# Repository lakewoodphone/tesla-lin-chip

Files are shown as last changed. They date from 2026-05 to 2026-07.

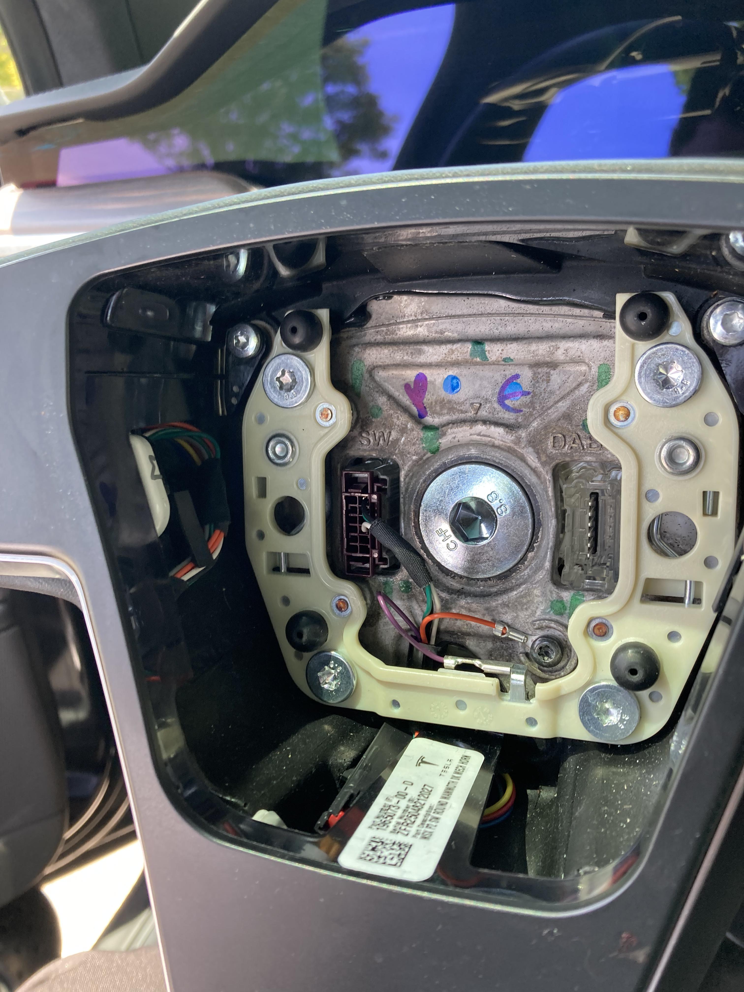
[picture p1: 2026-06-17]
photos/IMG_0228.jpg

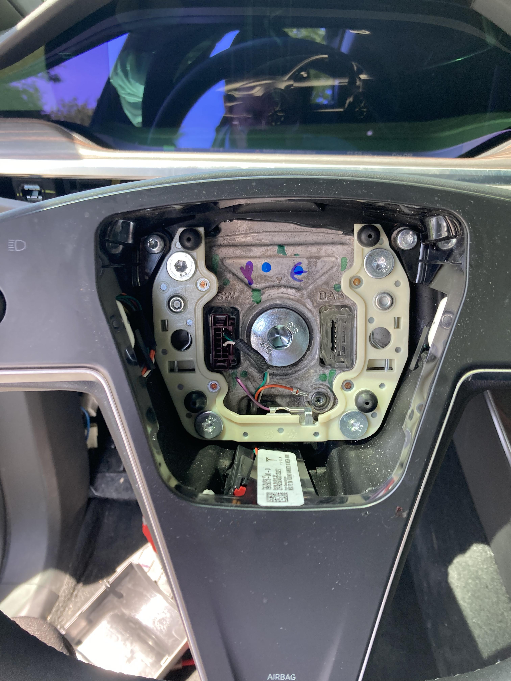
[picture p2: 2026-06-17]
photos/IMG_0226.jpg

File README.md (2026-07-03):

# tesla-lin-chip

Tesla LIN reverse-engineering and anti-nag chip project. Covers passive LIN capture, active frame injection, Model 3/Y/X steering wheel volume control, and the custom dual-LIN ESP32-S3 Rev A PCB (JLCPCB order).

**Local path:** `C:\Users\ezabz\Code\tesla-lin-chip`
**GitHub:** `https://github.com/lakewoodphone/tesla-lin-chip`

Start with `START_HERE.md` when resuming. It now points to the current Rev A ESP32-S3 dual-LIN Model 3 active anti-nag path. Older XIAO/APG discovery notes are preserved under `docs/archive/legacy-xiao-2026-06-17/` and should be treated as historical evidence, not the active operating surface.

Current first-read docs:

```text
START_HERE.md
NEXT_STEPS.md
TOOLS.md
docs/README.md
docs/active/rev-a-model3-active-anti-nag.md
docs/active/model3-capture-data-index.md
```

Current Rev A helper:

```powershell
powershell -NoProfile -ExecutionPolicy Bypass -File tools\rev-a-active-model3.ps1 -Action Preflight
```

For the implementation plan that makes the bench, passive car testing, and final active-capable chip more robust, read `IMPLEMENTATION_ROADMAP.md`.

## Current Status

- Passive LIN receive is bench-verified at 19200 baud.
- Full no-car evidence passed on 2026-05-26 and again after APG reseat on 2026-05-27: 80/80 exact APG -> XIAO matches across raw IDs `0x00` through `0x3F`, with 0 APG failures.
- Active Model X bench TX is verified on the isolated bench. `model:x` + `antinag:start` produced more than 100 self-received `0x0C` frames with enhanced checksum and parity OK.
- Active improvements applied: bus-idle collision guard (2 ms silence before TX), realistic scroll payloads (non-zero B2/B3), and mirror/alive frame injection (`0x0D` at 500 ms via `mirror:on`).
- Active safety now reports reset reason, fault count, last fault, and lockout state. RX-integrity spikes or a dominant-line timeout while armed force active output off and block re-arm until `safe:off` is run after inspection.
- Repository default now builds `field_passive`; active TX is explicit via `bench_active_ble` or `chip_lab_active`.
- BLE service "TeslaAntiNag" in active builds exposes model (x/3/y/auto), mode (duty/always), period (5-120s), enable (on/off), status, and capabilities characteristics. Enable requires `safe:arm` first.
- BLE advertising was revalidated on 2026-05-27 after fixing invalid NimBLE advertising intervals; active lab builds report `advertising=yes` over serial.
- Car-day tooling enforces passive preflight and verifies `field_passive` firmware by default.
- APG known-ID raw fallback captures XIAO-generated active Model X frames after APG reseat: `active-apg-raw-proof.ps1` passed with 11 raw `ID=0x0C PID=0x4C` rows at `logs\lin-capture-20260527_212130.csv`.
- Model 3/Y steering LIN was captured on 2026-05-28. The confirmed left wheel control ID is `0x2A` (7 bytes) and right wheel control ID is `0x2B` (6 bytes). Left wheel byte[0] is `0x0D` volume up, `0x0B` volume down, `0x2C` click, `0x0C` idle. See `docs/model3y-steering-lin-2026-05-28.md`.
- `car_passthrough` is a new dual-transceiver firmware profile for the actual cut-wire bridge design. See `docs/model3y-passthrough-volume.md`.
- Final active-use hardware requires a custom dual-LIN passthrough PCB, not a one-LIN board. Current Rev A order core is `ESP32-S3-WROOM-1U-N8R8` plus 2x `TJA1021T/20`. See `docs/final-board-ordering-decision-2026-05-29.md`.

## Hard Stops

- Do not transmit on a vehicle LIN bus.
- Do not run `validate-xiao-bench.ps1`, `bench-evidence-suite.ps1`, `send-netanalyser-headless.ps1`, `antinag-replay.ps1`, or active firmware commands on a vehicle.
- Vehicle work starts passive only: APG passive monitor plus XIAO passive receive.
- Do not assume Model 3/Y IDs match Model X. Capture first, then label.
- Do not use the old `0x1A` Model 3/Y candidate for current Model 3 volume work; the confirmed left scroll wheel ID is `0x2A`.
- Do not use the old `C:\Users\ezabz\Code\Schematics\firmware\anti-nag-v1` path as active firmware.

## Hardware

| Component | Part | Notes |
|---|---|---|
| MCU | Seeed XIAO ESP32-C3 | USB CDC, normally COM4 |
| LIN analyzer | Microchip APGDT001 | VID `04D8`, PID `0A04`; PICkitS DLL is x86 |
| LIN transceiver | GODIYMODULES TJA1021 breakout | Logic header: `GND TX SLP RX`; bus header: `GND LIN INH VIN` |
| Level shifter | DIYables 4-channel bidirectional | HV=5V, LV=3.3V |
| PSU | Bench supply | 12V bus/module power |

## Wiring

Power and bus:

```text
PSU 12V -> APG VBAT / bus power
PSU 12V -> module VIN
PSU GND -> APG GND -> module GND -> level shifter GND -> XIAO GND
APG LINBUS pin 1 -> module LIN
XIAO 5V/VUSB -> module SLP and level shifter HV
XIAO 3V3 -> level shifter LV
```

Passive receive path:

```text
module RX -> level shifter HV1/A1 -> level shifter LV1/B1 -> XIAO D3/GPIO5
```

Active bench TX path:

```text
XIAO D2/GPIO4 -> level shifter LV2/B2 -> level shifter HV2/A2 -> module TX
```

Known wiring lesson from 2026-05-27: if `txd:low` makes XIAO D2 near 0V but LV2 stays near 3.3V, the D2 -> LV2 jumper is disconnected or on the wrong channel.

## Firmware

Main file: `src/main.cpp`

Core passive features:

- UART1 at 19200 baud on RX GPIO5/D3 and TX GPIO4/D2.
- Boundary-based parser: break/idle -> sync `0x55` -> PID -> data/checksum.
- Actual payload length is observed from frame boundary; `pred=<n>` is only the ID-class length hint.
- Protected-ID parity validation.
- Enhanced/classic checksum detection.
- Ring buffer of recent frames via `ring`.
- Runtime serial commands: `vehicle:`, `baud:`, `raw:`, `ring`, `stats`.
- USB serial fallback when WiFi is unavailable.

Active mode (`bench_active_ble` / `chip_lab_active`, bench only):

- Active TX requires serial `safe:arm` before any frame, BLE enable, TXD diagnostic, or custom `tx:` command can transmit. Use `safe:off` to stop and disarm.
- Two modes: `mode:duty` (burst UP -> DOWN every `period:N` ms, default 20s) or `mode:always` (constant alternation every 300ms).
- Double-click scroll wheel button: two fast presses toggles chip output on/off.
- Model profiles: `model:x` (`0x0C` confirmed), `model:3` (`0x2A` confirmed left scroll wheel), `model:y` (`0x2A` likely; verify passively), `model:auto`.
- Active commands: `safe:arm`, `safe:off`, `factory:reset`, `config`, `model`, `model:x`, `model:3`, `model:y`, `antinag:start`, `antinag:stop`, `antinag:single`, `vol:up`, `vol:down`, `vol:click`, `vol:idle`, `mode:duty`, `mode:always`, `period:20000`, `mirror:on`, `mirror:off`, `tx:`.
- Active event log: `events` prints recent RAM events and persisted NVS slots for boot, arm, config, start/stop, inhibits, and faults.
- Diagnostics: `txd:low`, `txd:high`, `txd:uart`.
- BLE: NimBLE config service with model/mode/period/enable plus status/capabilities. Advertises as "TeslaAntiNag". Double-click wheel button still toggles on/off only after arming.
- Active lab builds define `NO_WIFI`; BLE and USB serial are the active-lab control/evidence paths so missing shop WiFi cannot interfere with BLE advertising.
- NVS persisted config stores model/mode/period with version+CRC; active output always boots off/disarmed.

## Build And Flash

Build current repo default passive field firmware:

```powershell
cd C:\Users\ezabz\Code\xiao-lin-bench
python -m platformio run
```

Build every supported firmware target:

```powershell
powershell -NoProfile -ExecutionPolicy Bypass -File tools\build-all-envs.ps1
```

Build active bench firmware explicitly:

```powershell
python -m platformio run -e bench_active_ble
```

Build the dual-transceiver passthrough prototype:

```powershell
python -m platformio run -e car_passthrough
```

Upload to the XIAO on COM4:

```powershell
python -m platformio run -t upload --upload-port COM4
```

Monitor XIAO USB serial:

```powershell
python -m platformio device monitor --port COM4 --baud 115200 --dtr 1 --rts 0
```

If normal PlatformIO upload fails, use the documented `esptool --no-stub` fallback from `START_HERE.md`.

## Validation

Passive quick bench validation:

```powershell
powershell -NoProfile -ExecutionPolicy Bypass -File tools\validate-xiao-bench.ps1 -ComPort COM4 -Baud 19200 -BootWaitSeconds 4 -PerFrameTimeoutMs 2500
```

Full no-car evidence suite:

```powershell
.\tools\bench-evidence-suite.ps1 -VehicleId tesla-bench-full -ComPort COM4 -Baud 19200
```

Active Model X bench validation flow:

```powershell
# After flashing bench_active_ble firmware:
powershell -NoProfile -ExecutionPolicy Bypass -File tools\active-bench-proof.ps1 -ComPort COM4 -Model x -ConfirmBenchIsolation
```

Expected active proof: `ring` shows `ID=0x0C PID=0x4C [8B]` frames with `enhanced parity=OK` and `badChk=0 badPid=0` in `stats`.

Independent APG known-ID raw observer proof, bench only:

```powershell
powershell -NoProfile -ExecutionPolicy Bypass -File tools\active-apg-raw-proof.ps1 -Model x -DurationSeconds 6 -MinFrames 8 -ConfirmBenchIsolation
```

Expected APG raw proof: `PASS` with raw CSV rows for the selected model ID, `source=raw`. The script supports `-Model x|3|y|auto`, preflights APG initialization before active TX, forces continuous active mode during capture, restores duty mode afterward, and exits before transmit if APG is unavailable.

## Tooling

| Tool | Purpose | Vehicle-safe? |
|---|---|---|
| `tools/monitor-apg-lin-bus.ps1` | APG passive capture | Yes, receive-only |
| `tools/car-day-launcher.ps1` | Passive car-day APG/XIAO launcher | Yes, if used passive-only |
| `tools/build-all-envs.ps1` | Compile all firmware environments | Yes |
| `tools/new-capture-session.ps1` | Create manifest-backed capture folder | Yes |
| `tools/preflight-hardware-check.ps1` | Record physical preflight checks | Yes |
| `tools/full-bench-proof.ps1` | Build + passive proof; add `-RunActive -ConfirmBenchIsolation` for active/APG raw bench proof | No, bench only |
| `tools/validate-xiao-bench.ps1` | APG transmit -> XIAO receive validation | No, bench only |
| `tools/bench-evidence-suite.ps1` | Full APG/XIAO no-car evidence matrix | No, bench only |
| `tools/active-bench-proof.ps1` | XIAO active TX self-receive proof | No, bench only |
| `tools/active-apg-raw-proof.ps1` | XIAO active TX plus APG known-ID raw observer proof | No, bench only |
| `tools/prepare-model3y-car-day.ps1` | Pre-arrival APG/XIAO health check and `field_passive` flash | Yes |
| `tools/start-model3y-passive-capture.ps1` | Passive Model 3/Y capture wrapper with action windows | Yes, passive only |
| `tools/process-model3y-capture.ps1` | Analyze a capture session and emit candidate JSON | Yes, post-capture |
| `tools/stage-model3y-active-bench.ps1` | Apply reviewed 3/Y candidate and run bench-only active proofs | No, bench only |
| `tools/inject-vol-scroll.py` | Confirmed 0x2A left-volume active proof with JSON run logs | No, bench only |
| `tools/send-netanalyser-headless.ps1` | APG headless LIN transmit | No, bench only |
| `tools/antinag-replay.ps1` | APG anti-nag replay sequence | No, bench only |
| `tools/serial-to-lin-events.ps1` | XIAO USB serial -> secretary API | Passive if source is passive |
| `tools/analyze-lin-capture.py` | Post-capture analysis, Tesla ID reference, action-window ranking | Yes, post-capture |
| `tools/summarize-lin-capture.ps1` | Quick APG CSV summary | Yes, post-capture |
| `tools/lin-payload-calc.py` | Payload/checksum calculator | Reference only |

APG tools must run through 32-bit PowerShell when they load `PICkitS.dll`:

```powershell
cmd /c %WINDIR%\SysWOW64\WindowsPowerShell\v1.0\powershell.exe -STA -NoProfile -ExecutionPolicy Bypass -File tools\monitor-apg-lin-bus.ps1 -Baud 19200
```

## Evidence And Docs

- `START_HERE.md` - canonical current handoff.
- `BENCH_EVIDENCE.md` - passive and active bench evidence.
- `ACTIVE_INJECTOR.md` - active bench wiring, operation, and diagnostics.
- `IMPLEMENTATION_ROADMAP.md` - full roadmap for bench robustness, passive car testing, and final active-capable chip development.
- `NEXT_STEPS.md` - current work plan.
- `TOOLS.md` - tool reference.
- `docs/archive/` - old passive-only and capture-history notes.
- `docs/final-board-ordering-decision-2026-05-29.md` - current direct Rev A order decision.
- `docs/final-chip-architecture.md` - current dual-LIN active passthrough board architecture.

## Known Issues

| Issue | Current understanding |
|---|---|
| APG NetworkAnalyser event/display modes log zero rows for XIAO-generated active frames | Settled: use `monitor-apg-lin-bus.ps1 -RawFallback -RawFallbackId 0x0C` or `active-apg-raw-proof.ps1` for known-ID bench observation. Generic vehicle discovery still uses normal passive event capture first. |
| APGDT001 reports `CM_PROB_FAILED_START` / `Error sending script` | Reseat/replug or use elevated PnP restart before APG-dependent tests. The May 27 physical reseat recovered APG to `CM_PROB_NONE`, and passive plus APG raw proofs passed afterward. |
| XIAO WiFi reports `NO_AP_FOUND` | Use USB serial and `serial-to-lin-events.ps1` unless WiFi credentials are repaired |
| `PermissionError` on COM4 | A serial monitor is holding the port; stop PlatformIO/terminal process |
| Direct `send-apg-lin-frame.ps1` baud looks wrong | Use NetworkAnalyser-based tools for real validation |
| Holding TXD low does not always pull LIN low forever | LIN dominant-timeout can release the bus; validate with real frames and ring buffer |

## Repository Structure

```
tesla-lin-chip/
├── README.md                     This file — project overview and wiring reference
├── START_HERE.md                 Canonical current handoff — start here every session
├── BENCH_EVIDENCE.md             Passive and active bench evidence summary
├── ACTIVE_INJECTOR.md            Active TX bench wiring, operation, and diagnostics
├── IMPLEMENTATION_ROADMAP.md     Full roadmap: bench → passive car → final chip
├── NEXT_STEPS.md                 Current work plan
├── TOOLS.md                      Tool reference
├── platformio.ini                PlatformIO build config (passive default + active envs)
│
├── src/                          XIAO ESP32-C3 firmware
│   ├── main.cpp                  v5.1 — build profiles, safe arm gate, BLE, ring buffer
│   ├── car_passthrough.cpp       Dual-transceiver passthrough firmware prototype
│   └── secrets.h.example         WiFi/API settings template
│
├── hardware/
│   └── tesla-dual-lin-rev-a/     Rev A PCB — ESP32-S3-WROOM-1U-N8R8 + 2x TJA1021T/20
│       ├── kicad/                KiCad schematic + PCB (tesla-dual-lin-rev-a.kicad_sch/pcb)
│       ├── bom/                  BOM strategy, cost model, supplier shortlist
│       ├── build/                Generated Gerbers, drill files
│       ├── manufacturing/        JLCPCB order files
│       ├── electrical/           Constraint files
│       └── tests/                DRC/ERC reports
│
├── docs/
│   ├── final-board-ordering-decision-2026-05-29.md  Rev A order decision
│   ├── final-chip-architecture.md                   Dual-LIN active board architecture
│   ├── model3y-steering-lin-2026-05-28.md           Model 3/Y confirmed ID map (0x2A left, 0x2B right)
│   ├── model3y-passthrough-volume.md                Cut-wire passthrough architecture
│   ├── bench-revalidation-2026-05-27.md             BLE fix + APG reseat proof
│   ├── chip-sourcing-shortlist-2026-05-29.md        ESP32-S3 + TJA1021 supplier shortlist
│   ├── secure-provisioning-anti-cloning-2026-05-29.md  nRF5340 anti-cloning design notes
│   ├── single-board-rev-a-product-spec-2026-05-29.md   Rev A product spec
│   ├── reports/                  Field analysis reports from vehicle visits
│   └── archive/                  Historical passive/capture notes
│
├── research/
│   ├── directives/               Research directives (ESP32, LIN, PCB, Tesla purchase)
│   └── responses/                Research responses and synthesis documents
│
├── knowledge/
│   └── hardware/                 Hardware knowledge base (TSL family, anti-nag landscape, BOM strategy)
│
├── tools/                        PowerShell + Python operational scripts
│   ├── tesla-tsl5-lin-capture.ps1     LIN capture via FX2/Sigrok for TSL5 bench
│   ├── tesla-tsl5-bench-readiness.ps1 TSL5 bench readiness check
│   └── ... (see TOOLS.md for full list)
│
├── captures/
│   ├── sigrok/                   Raw .sr Sigrok captures (FX2 device, Model X field sessions)
│   └── lin-csv/                  (use logs/ for CSV captures from the bench)
│
├── logs/                         Bench CSV captures, active proof logs, bench evidence archives
├── photos/                       Vehicle visit photos (Model X SCCM, steering wheel access points)
├── audit-logs/                   Session audit logs (Tesla deal, bench setup sessions)
└── boards/                       Board JSON definitions (ESP32-S3 N8R8)
```

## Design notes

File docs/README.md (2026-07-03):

# Documentation Map

Updated: 2026-06-17

## Current Path

Use these first:

```text
START_HERE.md
NEXT_STEPS.md
TOOLS.md
docs/active/rev-a-model3-active-anti-nag.md
docs/active/model3-live-measurement-plan.md
docs/active/model3-capture-data-index.md
docs/model3y-passthrough-volume.md
docs/rev-a-first-article-2026-06-16.md
docs/rev-b-quality-gate-2026-06-16.md
```

## Archive Policy

Old notes are not deleted. When a document is mostly historical or was written for the earlier XIAO/APG one-LIN workflow, move it under `docs/archive/` and leave the active path short.

Current archive bucket:

```text
docs/archive/legacy-xiao-2026-06-17/
```

This bucket preserves the former top-level handoffs:

```text
START_HERE.legacy.md
NEXT_STEPS.legacy.md
TOOLS.legacy.md
```

## Evidence vs Operating Instructions

- Evidence belongs in dated docs, logs, and session folders.
- Operating instructions belong in `START_HERE.md`, `NEXT_STEPS.md`, `TOOLS.md`, and `docs/active/`.
- If evidence contradicts an operating doc, update the operating doc and keep the old evidence as history.

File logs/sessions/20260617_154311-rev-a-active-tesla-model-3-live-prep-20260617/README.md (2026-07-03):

# Rev A Active Session Folder

Use measurements.md as the working checklist.

Subfolders:

`	ext
photos/   wiring and bench photos
serial/   serial transcripts or copied terminal output
ble/      BLE scan output/screenshots
`

Reference plan: docs/active/model3-live-measurement-plan.md

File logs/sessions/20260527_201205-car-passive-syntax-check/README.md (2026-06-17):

# LIN Capture Session 20260527_201205

- Mode: car-passive
- Vehicle: syntax-check
- Baud: 19200
- Capture point: 
- Firmware expected: field_passive
- Active TX allowed: False

## Preflight

- [ ] Run tools\\preflight-hardware-check.ps1 -Mode car-passive
- [ ] Run firmware version/config and save serial output
- [ ] Attach photos of probe/wiring setup if this is a car capture
- [ ] Copy APG CSV/TXT and XIAO logs into this folder
- [ ] Run tools\\analyze-lin-capture.py with --json into this folder

## Commands

`powershell
.\\tools\\car-day-launcher.ps1 -VehicleId syntax-check -Baud 19200 -DurationSeconds 120
`",
    ",

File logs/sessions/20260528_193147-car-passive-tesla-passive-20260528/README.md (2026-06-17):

# LIN Capture Session 20260528_193147

- Mode: car-passive
- Vehicle: tesla-passive-20260528
- Baud: 19200
- Capture point: Model 3/Y steering LIN
- Firmware expected: field_passive
- Active TX allowed: False

## Preflight

- [ ] Run tools\\preflight-hardware-check.ps1 -Mode car-passive
- [ ] Run firmware version/config and save serial output
- [ ] Attach photos of probe/wiring setup if this is a car capture
- [ ] Copy APG CSV/TXT and XIAO logs into this folder
- [ ] Run tools\\analyze-lin-capture.py with --json into this folder

## Commands

`powershell
.\\tools\\car-day-launcher.ps1 -VehicleId tesla-passive-20260528 -Baud 19200 -DurationSeconds 120
`",
    ",

Passive Model 3/Y discovery capture. Active TX is not allowed.

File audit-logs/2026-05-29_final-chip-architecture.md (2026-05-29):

# 2026-05-29 Final Chip Architecture Planning

## Request

Design the actual bench-only chip/board direction now that the Tesla Model 3/Y steering LIN data is known. Include both-wheel scroll up/down, push, double-push goals, passive/passthrough/active modes, Bluetooth control/update, VIN/test-fixture binding, and safety controls to prevent road-use deployment.

## Research

Ran the Personal Secretary research dispatcher:

```text
personal-secretary-mvp/docs/research/directives/052-tesla-lin-chip-sourcing-board-architecture.md
personal-secretary-mvp/docs/research/responses/2026-05-29-tesla-lin-chip-sourcing-board-architecture.md
```

Provider/result:

```text
provider=perplexity
model=sonar-deep-research
status=complete
cost_usd=0.59776
search_count=48
citation_count=45
```

Supplemental official-page checks confirmed key details for NXP TJA1021, TI TLIN1029A-Q1, Nordic nRF5340 DK, Espressif ESP32-S3, and u-blox NORA-B1.

## Decisions Captured

- Primary Rev A direction: Nordic nRF5340, preferably via certified u-blox NORA-B1 module for the first custom PCB.
- Development platform: nRF5340 DK or NORA-B1 EVK/MINI-NORA-B1.
- Keep XIAO ESP32-C3 as protocol proving rig, not final dual-LIN product platform.
- ESP32-S3 remains a fallback if staying close to the current ESP32/NimBLE code matters more than BLE-first security.
- STM32WB55 remains an alternate if hardware USART LIN mode becomes the deciding factor.
- LIN transceiver shortlist: NXP TJA1021 primary, TI TLIN1029A-Q1 primary alternate, TI TLIN4029A-Q1 rugged alternate, Microchip MCP2003/MCP2004 fallback.
- Rev A must use two LIN transceivers for passthrough: car-side and wheel-side.
- Active output must be hardware-gated and default-off independent of firmware.
- VIN/test-fixture binding is a safety/authorization gate, not a vehicle-security bypass.
- Right-wheel injection remains disabled until the `0x2B` counter model is extracted and bench-proven.

## Files Updated

```text
docs/final-chip-architecture.md
docs/chip-sourcing-shortlist-2026-05-29.md
docs/single-board-rev-a-product-spec-2026-05-29.md
docs/secure-provisioning-anti-cloning-2026-05-29.md
NEXT_STEPS.md
```

## Single-Board Constraint Follow-Up

The owner clarified that the final device must be small, all on one board, connectorized, minimal-soldering, robust, and plug-in friendly. A second focused research pass was run:

```text
personal-secretary-mvp/docs/research/directives/053-compact-all-in-one-lin-ble-board-selection.md
personal-secretary-mvp/docs/research/responses/2026-05-29-compact-all-in-one-lin-ble-board-selection.md
```

Provider/result:

```text
provider=perplexity
model=sonar-deep-research
status=complete
cost_usd=0.42985
search_count=39
citation_count=36
```

Outcome: no researched commercial/off-the-shelf board satisfies BLE + two independent LIN channels + protected 12V + small single-board plug-in harness fixture. The closest reference is the Copperhill/SK Pang ESP32S3 CAN & LIN board, but it has only one LIN channel and cannot be the final passthrough board.

Updated final direction: compact custom assembled PCB, defaulting to u-blox NORA-B106-00B / nRF5340 with Ezurio BL5340 integrated-antenna module as alternate. Rev A target is about 60 mm x 35 mm, four-layer, assembled, with two LIN transceivers, protected 12V input, LIN/USB ESD, keyed positive-latch car/wheel harness connectors, USB-C, SWD, physical mode switch, physical arm, LEDs, test pads, and adapter harnesses for vehicle-specific connectors.

## Firmware Protection / Anti-Cloning Follow-Up

The owner clarified that a user must not be able to plug the board into a computer/debugger, read the firmware, clone it, or casually activate/rebind it. A third focused research pass was run:

```text
personal-secretary-mvp/docs/research/directives/054-nrf5340-firmware-protection-anti-cloning-anti-abuse.md
personal-secretary-mvp/docs/research/responses/2026-05-29-nrf5340-firmware-protection-anti-cloning-and-anti-abuse-architecture-for-compact-ac9a9b9f.md
```

Provider/result:

```text
provider=perplexity
model=sonar-deep-research
status=complete
cost_usd=0.43612
search_count=35
citation_count=35
```

Outcome: encryption alone is not sufficient. Rev A must layer secure boot, signed firmware, signed profile/config packages, anti-rollback, nRF5340 APPROTECT/SECUREAPPROTECT, ERASEPROTECT, per-device keys, authenticated BLE/USB activation, binding/rebinding tokens, hardware TX gates, physical mode/arm controls, and bench-only connector/harness policy.

Residual risk is explicit: this protects against casual and intermediate cloning/readout, but not against a well-funded invasive silicon lab. Production signing keys must stay outside the repo and preferably offline/HSM-backed.

## Safety Position

No active vehicle testing is implied by this architecture. Rev A is a bench fixture. The board must boot passive, require physical arm plus authenticated BLE/USB authorization for active/passthrough modes, time out automatically, log binding and safety state, reject unsigned firmware, and make active output electrically impossible on reset/brownout/crash/bootloader/unarmed states.

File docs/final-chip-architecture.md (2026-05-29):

# Final Active Passthrough Board Architecture

Status: current Rev A hardware direction after the 2026-05-29 assumption audit. This is not a released PCB layout or road-use device.

The final active-capable product is a custom single PCB that sits inline between the Tesla car-side LIN harness and the steering-wheel side LIN harness. It is not a one-transceiver tap board, not a Copperhill/SK Pang gateway board, and not a stack of dev boards.

Pre-audit docs were archived under:

```text
docs/archive/2026-05-29-pre-assumption-audit/
```

Research artifacts behind this decision:

```text
personal-secretary-mvp/docs/research/responses/2026-05-29-tesla-lin-chip-sourcing-board-architecture.md
personal-secretary-mvp/docs/research/responses/2026-05-29-compact-all-in-one-lin-ble-board-selection.md
personal-secretary-mvp/docs/research/responses/2026-05-29-nrf5340-firmware-protection-anti-cloning-and-anti-abuse-architecture-for-compact-ac9a9b9f.md
personal-secretary-mvp/docs/research/responses/2026-05-29-cheapest-reliable-dual-lin-ble-passthrough-chip-module-f7be4c0f.md
personal-secretary-mvp/docs/research/responses/2026-05-29-authoritative-datasheet-check-dual-lin-ble-rev-a-bom-9abd3f3b.md
```

## Bottom Line

Build Rev A around:

```text
ESP32-S3-WROOM-1U-N8R8 module
+ 2x NXP TJA1021T/20 LIN transceivers
+ protected 12V input
+ USB-C service/provisioning
+ factory/service pads
+ keyed car-side and wheel-side harness connectors
+ physical mode switch
+ physical arm gate
+ default-off LIN TX gating
+ secure boot, flash encryption, signed updates, activation, and binding
```

Primary central module: `ESP32-S3-WROOM-1U-N8R8`.

Primary LIN transceiver: `TJA1021T/20`, used twice.

Backup central module: `MDBT53-P1M` or another nRF5340 module if a higher-security Nordic path becomes necessary.

Backup LIN transceiver: `TPIC1021D` if TJA1021 stock or lifecycle status becomes a problem.

## Why Passthrough Is Mandatory

The steering-wheel buttons must continue to work while the board is connected. That requirement changes the hardware completely.

A one-transceiver board can tap the existing bus and can sometimes inject frames on an isolated bench. It cannot sit cleanly between the car and the wheel while preserving native button behavior, because it cannot separate these two electrical sides:

```text
car-side LIN harness  <->  steering-wheel LIN module
```

The final board must split the connection and proxy it:

```text
car-side LIN harness
  <-> LIN transceiver A
  <-> MCU firmware/cache/proxy
  <-> LIN transceiver B
  <-> steering-wheel LIN module
```

This is why the final board needs two LIN transceivers. One transceiver sees and responds to the car-side LIN master. The other transceiver polls or listens to the steering-wheel side and maintains the current wheel state/cache. When the car asks for ID `0x2A`, the firmware can immediately return either the real cached wheel response or a controlled substituted volume frame.

LIN timing does not leave room to wait for the wheel side after the car-side header arrives. This is not a bit-for-bit wire bridge; it is a cached protocol proxy with two physical LIN domains.

## Hard Product Constraints

- One assembled PCB, not several boards wired together.
- Two independent LIN channels on the board.
- BLE on board for provisioning, control, status, and signed updates.
- Mostly plug-in operation after assembly: keyed harness connectors, USB/provisioning, no routine hand soldering.
- Protected 12V input and protected LIN/USB lines.
- Direct 3.3 V MCU-to-LIN-transceiver logic where possible; no routine level shifters.
- Hardware TX gate defaults off when the MCU is blank, crashed, reset, or in bootloader.
- Physical arm is required for any active or passthrough response.
- Firmware cannot be casually read out by plugging into USB/debug after provisioning.
- Active/passthrough modes require signed firmware, signed profile/config, activation, binding, authenticated BLE/USB, physical mode, physical arm, session timer, rate limits, and healthy LIN state.
- Vehicle differences are handled by software profiles and adapter harnesses, not by putting every OEM connector on the PCB.
- Bench/lab fixture first. No road-use workflow.

## Central MCU/BLE Decision

### Primary: ESP32-S3-WROOM-1U-N8R8

The assumption audit changed the default away from nRF5340. Nordic is cleaner on security, but the ESP32-S3 path is cheaper, available, easier to assemble, and much closer to the existing ESP32 firmware work.

Reasons to use the ESP32-S3 module for Rev A:

- It has three hardware UART controllers, enough for LIN A, LIN B, and service/debug.
- LIN is low bandwidth: 19200 baud on two sides is trivial for dual 240 MHz cores.
- BLE 5 support is built in.
- Secure boot, flash encryption, eFuse key storage, encrypted NVS, anti-rollback, and debug/bootloader lock-down are supported through ESP-IDF.
- Existing code and bench experience are already ESP32-family based.
- ESP32-S3 modules are broadly stocked and inexpensive compared with nRF5340 modules.
- A module avoids first-spin RF layout risk.

Use the `1U` external antenna variant for Rev A because the board may live near metal steering-wheel structure. The U.FL antenna lets the RF radiator move into a plastic or less-shielded area without respinning the board. If mechanical testing proves the board is outside the shielded cavity, `ESP32-S3-WROOM-1-N8R8` with PCB antenna becomes an acceptable simplification.

### Backup: nRF5340 Module

Keep an nRF5340 module path as a backup, not the primary Rev A path.

Use cases where nRF5340 may become primary later:

- A customer or partner requires Nordic's cleaner secure boot/readback/TrustZone story.
- BLE power behavior matters more than BOM cost.
- The product moves toward a higher-margin, higher-assurance security variant.

Recommended backup module family: Raytac `MDBT53-P1M` or Ezurio `BL5340` integrated-antenna/U.FL variant depending on stock and mechanical needs.

## LIN Transceiver Decision

### Primary: 2x NXP TJA1021T/20

Use two identical `TJA1021T/20` SO-8 transceivers for Rev A.

Why:

- LIN 2.1 / SAE J2602 class transceiver.
- Supports the 19200 baud Tesla steering-wheel bus.
- Automotive 12V LIN physical layer.
- Datasheet/product information explicitly states 3.3 V and 5 V MCU input-level compatibility.
- Existing bench rig already uses a TJA1021 breakout, so behavior is familiar.
- SO-8 is easy to inspect, probe, and assemble for Rev A.

The TJA1021 has some lifecycle/NRND signals on certain variants, so check distributor stock before layout lock. For Rev A prototype quantities this is acceptable; for Rev B production, either confirm supply or migrate to the backup footprint.

### Backup: TPIC1021D

Use `TPIC1021D` as the backup LIN transceiver because it also clearly supports 3.3 V / 5 V MCU logic compatibility.

### Demoted Parts

`MCP2003-E/SN` is cheap and valid as a LIN transceiver, but it is 5 V-logic-centric and does not cleanly meet the direct 3.3 V MCU interface requirement. It would likely require a level shifter or out-of-spec threshold assumptions. Do not use it as the Rev A primary.

`TLIN1029A-Q1` and `TLIN2029A-Q1` are attractive modern automotive LIN transceivers, but the authoritative check did not give the same clear direct 3.3 V logic guarantee as TJA1021/TPIC1021. They remain candidates only if the schematic intentionally includes level shifting or a verified VIO-compatible variant.

## Board Block Diagram

```text
12V input
  -> fuse/PTC
  -> reverse-polarity protection
  -> input TVS
  -> automotive buck regulator to 3V3, sized for ESP32-S3 peaks
  -> local decoupling and optional quiet sub-rails

ESP32-S3-WROOM-1U-N8R8
  -> UART0/service/debug/USB path
  -> UART1 -> LIN transceiver A TXD/RXD/SLEEP/EN -> car-side LIN
  -> UART2 -> LIN transceiver B TXD/RXD/SLEEP/EN -> wheel-side LIN
  -> physical mode switch
  -> physical arm input
  -> TX gate controls default-off
  -> LEDs: power, BLE, passive, armed, TX, fault
  -> provisioning/test pads
  -> U.FL external antenna

Car-side connector
  -> VBAT, GND, LIN_A, optional spare/wake/shield
  -> LIN ESD near connector

Wheel-side connector
  -> VBAT, GND, LIN_B, optional spare/wake/shield
  -> LIN ESD near connector
```

## Connector Strategy

Use generic keyed locking board connectors and vehicle-specific adapter harnesses.

Recommended Rev A pinout:

```text
CAR_SIDE:   VBAT, GND, LIN_A, spare/wake/shield
WHEEL_SIDE: VBAT, GND, LIN_B, spare/wake/shield
USB_C:      service/provisioning/logging
SERVICE:    internal pads or jumper for factory/rebind/recovery
```

Do not put Tesla-specific connectors directly on the base board. The base board should be reusable for bench, Tesla 3/Y, and future LIN fixtures through adapter harnesses.

## Power And Protection

Minimum Rev A protection stack:

- Resettable PTC or fuse on 12V input.
- Reverse-polarity MOSFET or automotive ideal-diode style protection.
- Automotive TVS on 12V input near connector.
- Buck regulator from 12V to 3.3V sized for ESP32-S3 peak current, not a LIN transceiver's tiny integrated regulator.
- LIN ESD/TVS on both LIN lines near connectors.
- USB ESD on USB D+/D-.
- Default-off pull resistors for transceiver sleep/enable and TX gate signals.
- Test pads for VBAT, 3V3, LIN_A, LIN_B, RXD/TXD lines, SLP/EN, ARM, FAULT, and GND.

## Firmware Architecture

Rev A firmware should move from Arduino-style proof work toward ESP-IDF for production security.

Required firmware layers:

- LIN A car-side responder/proxy.
- LIN B wheel-side poll/listen/cache engine.
- Model profile engine for IDs, lengths, checksum type, counters, and allowed actions.
- Safe default passive state after every boot.
- BLE provisioning/control/status services.
- USB service shell and logs.
- Secure boot and flash encryption production profile.
- Signed firmware and signed profile/config packages.
- Anti-rollback for firmware and profiles.
- Per-device activation/binding record.
- Rate limits, session timeout, fault latching, and health counters.

Current confirmed Model 3/Y left-wheel profile:

```text
ID 0x2A, PID 0x6A, 7 data bytes, enhanced checksum
Payload: [control, 0x80, 0x3F, 0x96, 0x00, counter_a, counter_b]
control: 0x0C idle, 0x0D volume up, 0x0B volume down, 0x2C click
```

Right-wheel ID `0x2B` remains capture-confirmed but not injection-ready until its counter model is extracted and validated.

## Security Architecture

Production Rev A must use ESP32-S3 security features deliberately:

- Secure Boot V2 enabled with production signing keys.
- Flash encryption enabled in production mode.
- JTAG/debug and unsafe bootloader paths disabled or restricted by eFuse policy.
- Per-device key/identity material generated during provisioning.
- Encrypted NVS or protected storage for activation/binding/config state.
- Signed firmware updates only.
- Signed profile/config packages only.
- Anti-rollback versioning for firmware and profiles.
- Production keys kept outside the repo.
- Debug-enabled engineering boards physically labeled and never treated as production units.

This does not stop an invasive silicon lab. It should stop casual USB/UART/SWD/flash readout, firmware copying, unsigned update loading, and casual rebinding.

## Product Modes

| Mode | TX possible | Intended use |
|---|---:|---|
| `SAFE_PASSIVE` | No | Default boot state, capture/status only |
| `PASSIVE_CAPTURE` | No | Bench and vehicle-adjacent receive-only diagnostics |
| `PASSTHROUGH_LAB` | Yes, gated | Dual-LIN cached proxy bench validation |
| `ACTIVE_MOCK_LAB` | Yes, gated | Isolated bench gesture generation or simulator work |
| `SERVICE_DFU` | No | Signed update/recovery with LIN TX disabled |

## Safety Gates

Active behavior is allowed only when all gates are true:

```text
signed firmware valid
signed profile valid
anti-rollback state valid
device activated
binding present
mode switch in passthrough lab or active mock
physical arm present
authenticated BLE/USB session
session timer not expired
rate limiter clear
LIN error counters below threshold
TX gate healthy
```

Any failed gate forces:

```text
TX gate off
transceivers safe/passive where possible
gesture queue cleared
fault/log event recorded
BLE/USB status updated
```

## Rev A Development Path

1. Order ESP32-S3-WROOM-1U-N8R8 modules, U.FL antennas, TJA1021T/20 transceivers, and backup TPIC1021D transceivers.
2. Build a two-LIN ESP32-S3 bench fixture with two transceiver breakouts to validate UART timing and cached proxy logic before PCB assembly.
3. Create Rev A schematic with the exact ESP32-S3 module, two TJA1021 channels, protected 12V input, USB-C, mode/arm controls, LEDs, and test pads.
4. Validate security/provisioning on ESP-IDF: secure boot, flash encryption, signed update, signed profile, activation, binding, and debug lockdown.
5. Layout a four-layer debug-friendly board around 60 mm x 35 mm.
6. Assemble a small Rev A batch.
7. Run bring-up: rails, USB, BLE, flash/security, LIN A, LIN B, TX gate, arm/mode, fault paths.
8. Run bench-only passthrough validation with simulated car master and real/simulated wheel side.
9. Do not attempt vehicle-side active validation until steering-wheel controls are restored and bench passthrough is proven.

## Rev A Exit Gate

Rev A is accepted only when:

- Both LIN channels pass receive/transmit bench validation at 19200 baud.
- Car-side proxy returns valid cached `0x2A` idle frames with enhanced checksum.
- Volume up/down/click substitutions produce valid `0x2A` responses only while armed.
- Native wheel button state is preserved when no injection is pending.
- Removing physical arm disables TX immediately.
- USB/BLE disconnect or timeout disarms active sessions.
- Unsigned firmware and unsigned profile packages are rejected.
- Flash readout/debug is locked on production-profile boards.
- Unactivated/unbound boards cannot enable active or passthrough TX.
- Faults latch and are visible in logs/status.

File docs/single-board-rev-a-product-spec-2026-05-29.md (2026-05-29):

# Single-Board Rev A Product Spec - 2026-05-29

Status: current compact board product spec after the dual-LIN passthrough correction and chip assumption audit.

## Decision

Build one custom compact PCB for inline active passthrough:

```text
ESP32-S3-WROOM-1U-N8R8 BLE module
+ 2x TJA1021T/20 LIN transceivers
+ protected 12V input
+ keyed car-side and wheel-side connectors
+ USB-C service/provisioning
+ physical mode switch
+ physical arm gate
+ secure boot/flash encryption
+ signed firmware/profile updates
+ activation and binding
```

This board is the final-product direction. Dev boards and breakouts are allowed only to validate the schematic and firmware before the PCB arrives.

## Non-Negotiable Behavior

- The wheel buttons must still work when the device is connected.
- Therefore the device must be an inline two-LIN passthrough/proxy, not a one-LIN tap.
- The default state after boot, crash, reset, failed activation, or service mode is passive/safe-off.
- Active output requires hardware arm plus authenticated software authorization.
- The board must never rely on a phone app alone to decide whether it can transmit.

## Physical Topology

```text
CAR SIDE
  VBAT/GND/LIN_A
  -> protection
  -> LIN transceiver A
  -> ESP32-S3 firmware proxy/cache
  -> LIN transceiver B
  -> protection
  VBAT/GND/LIN_B
WHEEL SIDE
```

The board does not literally relay every bit in real time. It uses cached wheel-side responses and immediate car-side responder behavior because LIN response timing is too tight to wait for the wheel after the car sends a header.

## Size Target

| Revision | Target | Priority |
|---|---|---|
| Rev A | about 60 mm x 35 mm, four-layer | Debuggable, labeled, probeable, mechanically reliable |
| Rev B | about 45 mm x 25 mm | Shrink only after Rev A timing, safety, RF, and harness behavior are proven |

Rev A should favor clear test pads, SO-8 packages, and readable labels over maximum miniaturization.

## Required Blocks

| Block | Required implementation |
|---|---|
| MCU/BLE | `ESP32-S3-WROOM-1U-N8R8`, U.FL antenna |
| LIN A | `TJA1021T/20` car-side transceiver with ESD |
| LIN B | `TJA1021T/20` wheel-side transceiver with ESD |
| Power | 12V input, fuse/PTC, reverse protection, TVS, automotive buck to 3.3V |
| Programming/service | USB-C, service pads, boot/reset access, factory provisioning path |
| Controls | Physical mode switch, physical arm, service/rebind strap or pad |
| Indicators | Power, BLE, passive, armed, TX, fault |
| Security | Secure boot, flash encryption, eFuse/debug lockdown, signed updates, activation/binding |
| Connectors | Positive-latch car-side and wheel-side harness connectors |
| Mechanical | Strain relief, antenna retention, mounting holes, enclosure clearance |

## Connector Strategy

Use robust generic connectors on the board and adapter harnesses outside the board.

Recommended pin groups:

```text
CAR_SIDE:   VBAT, GND, LIN_A, spare/wake/shield
WHEEL_SIDE: VBAT, GND, LIN_B, spare/wake/shield
USB_C:      service/provisioning/logging
SERVICE:    internal strap/pads for rebind/factory recovery
```

Do not put Tesla-specific connectors directly on Rev A unless mechanical proof shows that an adapter harness is worse. Generic keyed connectors keep the electronics reusable and reduce board respin risk.

## Electrical Defaults

- TX gates default disabled by resistor state.
- LIN transceiver sleep/enable defaults safe when MCU is reset or unprogrammed.
- Physical arm removal immediately disables TX and clears queued gestures.
- Bootloader, DFU, and service modes keep LIN TX electrically disabled.
- A latched fault requires `safe:off`, power cycle, or service inspection before re-arm.

## Firmware Requirements

Rev A firmware should be ESP-IDF based for security-critical work.

Required features:

- Two UART-backed LIN channels.
- Enhanced and classic checksum support.
- 19200 baud Tesla profile, with configurable LIN profile engine.
- Wheel-side cache for `0x28..0x2D` class frames.
- Car-side responder/proxy for confirmed IDs.
- Proven left-wheel `0x2A` substitution for volume up/down/click/idle.
- Right-wheel `0x2B` disabled for injection until counter model is proven.
- BLE status/provisioning/control service.
- USB service shell and logs.
- Signed profile import/export.
- Activation and binding before any active passthrough behavior.

## Security Requirements

- ESP32-S3 Secure Boot V2 enabled for production-profile units.
- ESP32-S3 flash encryption enabled in production mode.
- Production signing keys never stored in the repo.
- Debug/JTAG and unsafe ROM download paths disabled or restricted for production units.
- Per-device identity and activation state provisioned at manufacturing time.
- Signed firmware images only.
- Signed profile/config packages only.
- Anti-rollback for both firmware and profile/config versions.
- Encrypted NVS or equivalent protected storage for binding/config/secrets.
- Engineering units must be visibly labeled and logically separated from locked production units.

## Safety Gates

Active or passthrough TX is permitted only when every gate is true:

```text
valid signed firmware
valid signed profile
anti-rollback state valid
device activated
binding present
mode switch in PASSTHROUGH_LAB or ACTIVE_MOCK_LAB
physical arm present
authenticated BLE/USB session
session timer valid
rate limiter clear
LIN health counters clean
TX gate self-check passed
```

Failure response:

```text
TX gate off
transceivers safe/passive
gesture queue clear
fault event logged
BLE/USB status updated
```

## Expected Product Modes

| Mode | TX allowed | Description |
|---|---:|---|
| `SAFE_PASSIVE` | No | Default boot and locked state |
| `PASSIVE_CAPTURE` | No | Receive-only diagnostics |
| `PASSTHROUGH_LAB` | Yes, gated | Inline cached proxy with native wheel state preserved |
| `ACTIVE_MOCK_LAB` | Yes, gated | Bench-only generated frames to simulator/APG |
| `SERVICE_DFU` | No | Signed updates and recovery |

## Rejected Product Shapes

| Shape | Reason rejected |
|---|---|
| One-transceiver board | Cannot maintain clean car-side + wheel-side passthrough |
| Copperhill/SK Pang ESP32S3 CAN & LIN board | Good reference, but only one LIN transceiver |
| XIAO ESP32-C3 + breakouts | Proven discovery rig, not robust final hardware |
| nRF5340-first Rev A | Security-clean but more expensive and larger firmware rewrite than needed |
| MCP2003 direct-to-ESP32 | Cheap, but not the clean 3.3 V logic transceiver path for Rev A |

## Rev A Acceptance Tests

- Board powers from 12V through protection without overheating.
- BLE connects reliably with external antenna in intended enclosure position.
- USB service/provisioning works.
- Both LIN channels receive valid frames at 19200 baud.
- Both LIN channels can transmit in isolated bench mode only when armed.
- Car-side proxy returns valid cached idle frames.
- Native wheel button events pass through when no injection is pending.
- Volume up/down/click substitution works only for confirmed `0x2A` profile.
- Removing physical arm disables TX within one firmware cycle and by hardware gate.
- Unsigned firmware and unsigned profiles are rejected.
- Flash/debug readout is blocked on production-profile unit.
- Unactivated/unbound board cannot transmit.

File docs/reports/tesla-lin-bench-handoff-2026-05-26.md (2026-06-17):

# Tesla LIN Bench Handoff - 2026-05-26

## Start Here

Canonical current handoff:

```text
C:\Users\ezabz\Code\xiao-lin-bench\START_HERE.md
```

Clean snapshot archive:

```text
C:\Users\ezabz\Code\_snapshots\xiao-lin-bench-20260526_134330.zip
```

When the owner says "open the Tesla project", use this sequence:

1. Open `C:\Users\ezabz\Code\xiao-lin-bench\START_HERE.md`.
2. Open `C:\Users\ezabz\Code\xiao-lin-bench\NEXT_STEPS.md`.
3. If hardware is connected, run `tools\validate-xiao-bench.ps1 -KillExistingMonitor`.
4. Continue from the first unchecked item in `NEXT_STEPS.md`.

## Current Status

Bench is working end-to-end at 19200 baud for passive LIN receive.

Verified components:

- XIAO ESP32-C3 on COM4.
- APGDT001 USB-LIN analyzer.
- GODIYMODULES TJA1021 module with SLP tied high.
- DIYables bidirectional level shifter.
- Firmware v3 in `src/main.cpp`.
- APG NetworkAnalyser-based sender and passive monitor tools.
- Secretary `POST /api/v1/lin-events` and `GET /api/v1/lin-events`.

## Latest Bench Validation

Command:

```powershell
cd C:\Users\ezabz\Code\xiao-lin-bench
powershell -NoProfile -ExecutionPolicy Bypass -File tools\validate-xiao-bench.ps1 -KillExistingMonitor
```

Result:

```text
RESULT PASS - all bench frames decoded as expected
```

Passing frames:

```text
ID=0x0C PID=0x4C [2B pred=2] data: 12 34 | chk=6D enhanced parity=OK
ID=0x10 PID=0x50 [2B pred=2] data: AA 55 | chk=AF enhanced parity=OK
ID=0x22 PID=0xE2 [4B pred=4] data: 01 02 03 04 | chk=13 enhanced parity=OK
ID=0x3C PID=0x3C [8B pred=8] data: 00 00 00 00 00 00 00 00 | chk=C3 enhanced parity=OK
ID=0x3C PID=0x3C [8B pred=8] data: 00 00 00 00 00 00 00 00 | chk=FF classic parity=OK
```

## Important Discoveries

- NetworkAnalyser resets APG hardware to 9600 at `Network_Load`; set `MasterBaudRate`, then call `_OnAnswerSource.Change_LIN_BAUD_Rate(19200)` twice.
- NetworkAnalyser frame strings use raw LIN IDs, not protected PIDs. Send `0C 12 34`, not `4C 12 34`.
- Direct static PICkitS sender is debug-only; it can report/transmit while `Get_LIN_BAUD_Rate` shows 10000.
- APG passive monitor now initializes through NetworkAnalyser so it is safe for 19200 capture.
- TJA1021 `SLP` must be tied high to XIAO 5V.
- Wire TJA1021 module `RX` into the level shifter/XIAO, not module `TX`.

## Current Next Action

Configure `C:\Users\ezabz\Code\xiao-lin-bench\src\secrets.h` with real WiFi/hotspot credentials, `SECRETARY_URL`, and `VEHICLE_ID`, then rebuild and flash once more.

Car-day work is passive capture only until decoded and reviewed. No vehicle injection/transmit.

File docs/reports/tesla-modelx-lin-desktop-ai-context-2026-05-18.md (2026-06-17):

# ⚠️ SUPERSEDED — Tesla Model X LIN / XIAO Context - 2026-05-18

> **This file was the START-HERE briefing as of 2026-05-18. It is now superseded.**
> The bench was fully built and validated the night of 2026-05-25/26.
>
> **Current START HERE:** `C:\Users\ezabz\Code\xiao-lin-bench\README.md`
> **Next steps:** `C:\Users\ezabz\Code\xiao-lin-bench\NEXT_STEPS.md`
>
> Bench status as of 2026-05-26:
> - ✅ XIAO ESP32-C3 on COM4, firmware flashed, LIN parser running
> - ✅ APGDT001 USB-LIN analyzer headlessly controlled via `tools/send-netanalyser-headless.ps1`
> - ✅ TJA1021 transceiver + level shifter wired correctly (SLP tied to 5V)
> - ✅ First clean frame decoded: `#1 ID=0x3C data: 00 00 00 00 00 00 00 00 | chk=C3 OK`
> - ✅ Key bug fixed: `Change_LIN_BAUD_Rate` must be called after `Network_Load` (which resets to 9600)
>
> Keep reading this file only for historical context (field measurements, pre-bench state).

---

# HISTORICAL CONTEXT (2026-05-18) — kept for reference only

This file was written for an AI assistant working on the desktop machine. It is intentionally self-contained.

## Prior State as of 2026-05-18

The owner was trying to continue the Tesla Model X steering-wheel LIN / anti-nag research without the customer car. The desktop AI was struggling because the context was spread across docs, research artifacts, shell output, and a long chat.

State at that time: the customer 2025 Tesla Model X had been returned. Bench parts ordered but not yet arrived. Continue with documentation, parts, bench planning, capture analysis, and safe receive-path work only. Do not plan active injection on a customer vehicle from the current evidence.

## Absolute Hard Stops

- Do not inject, write, lock, spoof, or actively drive the LIN bus on a customer or owner Model X from the current evidence.
- Do not use `-ForceLock` on S/X customer cars.
- Do not probe `DAB`, yellow, SRS, or airbag connectors. `DAB` means Driver Air Bag.
- Do not connect raw 12-15 V LIN directly to XIAO ESP32-C3 GPIO or FX2 inputs.
- Do not connect XIAO `D2` or `D4` for active paths until receive is reliable and bench validation passes.
- Do not reuse the bare SOIC-8 TJA1020 that overheated. Treat that chip/build as unsafe.
- Do not assume Model 3/Y SCCM pinout applies to refreshed Model X.
- Do not do destructive git operations on the desktop. The desktop repos may be dirty and were updated by direct file copy because GitHub HTTPS auth failed under noninteractive SSH.

## Machines And Repo Paths

Laptop/current VS Code machine:

- `C:\Users\ezabz\code\personal-secretary-mvp`
- `C:\Users\ezabz\Code\lpt-schematics`

Desktop machine:

- Hostname: `zabz-tech`
- LAN SSH host: `192.168.50.138`
- `personal-secretary-mvp`: `C:\Users\ezabz\Code\personal-secretary-mvp`
- `lpt-schematics` clone is actually: `C:\Users\ezabz\Code\Schematics`
- Do not look for desktop `C:\Users\ezabz\Code\lpt-schematics`; it was missing during verification.

Desktop SSH helper from laptop:

```powershell
C:\Users\ezabz\code\personal-secretary-mvp\scripts\windows\Connect-DesktopSsh.ps1 -ForceLan -Command "hostname"
```

Important desktop git caveat: `git fetch` on the desktop failed under SSH with:

```text
fatal: could not read Username for 'https://github.com': No such file or directory
```

Because of that, docs were copied over SSH directly. On the desktop, some of these files may show as modified or untracked even though the laptop commits were pushed.

## Recent Commits Already Pushed From Laptop

`personal-secretary-mvp`:

- Branch: `master`
- Remote: `https://github.com/lakewoodphone/personal-secretary-mvp.git`
- Commit: `ce10f41`
- Message: `docs: save Tesla Model X LIN research`
- Scope: 20 Tesla/XIAO/LIN research and report files under `docs/reports/` and `docs/research/`.

`lpt-schematics`:

- Branch: `main`
- Remote: `https://github.com/lakewoodphone/lpt-schematics`
- Commit: `8db2773`
- Message: `docs: organize Model X LIN handoff`
- Scope: 7 anti-nag docs under `firmware/anti-nag-v1/`.

## Files The Desktop Should Have

On desktop `C:\Users\ezabz\Code\Schematics`:

- `firmware\anti-nag-v1\docs\model-x-xiao-lin-handoff-2026-05-18.md`
- `firmware\anti-nag-v1\docs\model-x-moti-visit-2026-05-17.md`
- `firmware\anti-nag-v1\docs\tesla-capture-guide.md`
- `firmware\anti-nag-v1\docs\field-checklist.md`
- `firmware\anti-nag-v1\docs\operator-card.md`
- `firmware\anti-nag-v1\README.md`

On desktop `C:\Users\ezabz\Code\personal-secretary-mvp`:

- `docs\reports\tesla-modelx-xiao-lin-field-analysis-2026-05-17.md`
- `docs\research\responses\2026-05-17-tesla-modelx-xiao-master-synthesis.md`
- `docs\research\responses\2026-05-18-urgent-tesla-lin-bench-mock-and-parts-research-ndate-2026-05-18-n-nwe-are-return-6242f52c.md`
- `docs\research\responses\2026-05-18-urgent-tesla-lin-bench-mock-and-parts-research-ndate-2026-05-18-n-nwe-are-return-6242f52c.json`
- Research directives 044, 045, 046, 047 under `docs\research\directives\`.

This file should also be copied to:

- `C:\Users\ezabz\Desktop\TESLA_MODEL_X_LIN_START_HERE_FOR_AI_2026-05-18.md`
- `C:\Users\ezabz\Code\Schematics\firmware\anti-nag-v1\docs\desktop-ai-context-2026-05-18.md`
- `C:\Users\ezabz\Code\personal-secretary-mvp\docs\reports\tesla-modelx-lin-desktop-ai-context-2026-05-18.md`

## Vehicle And Visit Facts

- Customer: Moti Zaks / Muteezax.
- Vehicle: 2025 Tesla Model X refresh, dark silver, AWD.
- Partial VIN / serial detail: `SF468907`.
- Plate: `H65 VSL`.
- Goal of visit: passive LIN discovery for steering-wheel / anti-nag research.
- Visit mode: capture-only. No BLE lock/write, no injection, no `-ForceLock`.
- Field access: steering wheel center airbag/horn pad was released using two stick-like tools through the rear wheel release holes.
- Useful connector found: labeled `SW`.
- Connector to avoid: labeled `DAB`; this is Driver Air Bag / SRS.

## SW Connector Wiring From Field Measurements

The `SW` connector had green, white, and black populated wires.

| Wire | Field measurement | Interpretation |
|---|---:|---|
| Black | about 1.8 mV to chassis | Ground / near-ground reference |
| Green | about 15.43 V | Vehicle low-voltage power; do not use for logic capture |
| White | about 11.57 V initially | LIN candidate before connector fully seated |
| White | about 8.15 V after SW connector was seated | Active/loaded LIN bus average |

Critical correction: early captures were taken while the SW connector was not fully seated, so the car was not reading steering-wheel presses. Those early captures still proved bus traffic on the white wire, but they did not show real wheel input changes.

## Confirmed Capture Wiring

Successful passive capture path:

```text
SW connector white wire
    -> backprobe / test lead
    -> breadboard row 1
    -> 4x10k divider
    -> breadboard row 4
    -> FX2 D0

Vehicle chassis ground
    -> breadboard GND rail
    -> FX2 GND
```

Do not connect the SW white wire directly to FX2 or XIAO. It must go through the divider or, preferably for XIAO receive, through a real LIN transceiver.

## Capture Artifacts

Useful capture folders in the `lpt-schematics` anti-nag project:

| Purpose | Path | Notes |
|---|---|---|
| First manual, SW not seated | `firmware/anti-nag-v1/captures/moti-modelx-manual-20260517-133400/white-sw-d0-90s.sr` | Decoded LIN, but steering controls were not being read |
| Seated / controls active | `firmware/anti-nag-v1/captures/moti-modelx-seated-20260517-134748/white-sw-seated-60s.sr` | Primary discovery capture |
| Hands-off baseline | `firmware/anti-nag-v1/captures/moti-modelx-baseline-20260517-135436/white-sw-baseline-30s.sr` | Baseline comparison |
| Single-control | `firmware/anti-nag-v1/captures/moti-modelx-single-control-20260517-135746/white-sw-single-control-30s.sr` | Best one-action comparison capture |

Ignore or treat as failed/debug:

- `firmware/anti-nag-v1/captures/moti-modelx-targeted-20260517-133732/`
- `firmware/anti-nag-v1/captures/moti-modelx-targeted-20260517-133739/`
- `moti-modelx-targeted-verified-*` folders from transient command experiments.

FX2 connection IDs change. Always run `sigrok-cli --scan` immediately before capture.

## Protocol Facts

- LIN baud confirmed: `19200`.
- Observed IDs on SW white bus: `0x0C`, `0x0D`, `0x0E`, `0x0F`, `0x16`, `0x17`.
- Main control-sensitive candidate: ID `0x0C`.
- PID for ID `0x0C`: `0x4C`.
- Frame layout: Break -> sync `0x55` -> PID -> 8 data bytes -> checksum.
- Checksum type: LIN 2.x enhanced checksum, includes PID and data.
- `0x0C` is strong enough for bench analysis planning, not strong enough for in-vehicle active manipulation.

Useful decode command pattern:

```powershell
& 'C:\Program Files\sigrok\sigrok-cli\sigrok-cli.exe' `
  -i white-sw-seated-60s.sr `
  -P "uart:rx=D0:baudrate=19200:format=hex,lin:version=2" `
  --protocol-decoder-samplenum > lin_decoded_exact_19200.txt
```

sigrok may emit only `lin-1: Break condition` plus raw `uart-1: XX` bytes. Analysis scripts must reconstruct frames from break -> `0x55` sync -> PID -> data/checksum. Do not rely only on friendly LIN PID/data annotations.

## Decoded ID 0x0C Semantics

The user explicitly said they scrolled up and down for volume change during capture. That ties the changing payloads to left steering-wheel scroll behavior.

Frame has 8 data bytes plus checksum:

| Byte | Name | Idle | Active / observed range | Meaning |
|---|---|---:|---|---|
| B0 | Control / scroll delta | `0x10` | `0x0A` to `0x15` | Direction/position around neutral |
| B1 | Button/control bits | `0x00` | `0x04`, `0x08`, `0x0C`, `0x10`, `0x1C` | Bit-packed control state; `0x04` likely touch/engage |
| B2 | Rate | `0x00` | `0x08` to `0x48` | Instantaneous scroll velocity |
| B3 | Accumulated count | `0x00` | `0x10` to `0xB0` | Accumulated scroll count, often about 2x B2 |
| B4 | Reserved | `0x00` | `0x00` | Always zero in observed data |
| B5 | Reserved | `0x00` | `0x00` | Always zero in observed data |
| B6 | Status | `0xC0` | `0xC0` | Invariant alive/status |
| B7 | Counter | `XF` | `0x0F` to `0xFF` with low nibble F | Rolling 4-bit counter in upper nibble |
| B8 | Checksum | variable | variable | LIN enhanced checksum |

Confirmed B0 interpretation:

| B0 value | Meaning |
|---|---|
| `0x10` | Neutral, wheel at rest |
| Greater than `0x10`, such as `0x11` to `0x15` | Scroll up / volume increase |
| Less than `0x10`, such as `0x0F` to `0x0A` | Scroll down / volume decrease |

Example new `0x0C` payloads from single-control vs baseline:

```text
10 04 00 00 00 00 C0 CF
10 04 00 00 00 00 C0 DF
11 00 00 00 00 00 C0 FF
10 00 00 10 00 00 C0 FF
10 04 00 00 00 00 C0 FF
```

Interpretation examples:

- `10 04 00 00 ...` means B1 bit 2 set: scroll touch/engage.
- `11 00 00 00 ...` means B0 one step above neutral: scroll up.
- `10 00 00 10 ...` means accumulated count tick in B3.

## Enhanced Checksum Formula

For ID `0x0C`, PID is `0x4C`. The checksum includes PID and all 8 data bytes.

```python
def lin_enhanced_checksum(pid: int, data: list[int]) -> int:
    checksum_sum = pid
    for value in data:
        checksum_sum += value
        if checksum_sum > 0xFF:
            checksum_sum -= 0xFF
    return 0xFF - checksum_sum
```

This was verified 15/15 against real payloads from baseline, single-control, and seated captures.

## Other IDs

- `0x0D`: same approximate frame rate as `0x0C`, but only 17 unique payloads across full seated session. Mostly rolling counter / passive mirror-like behavior. It did not gain single-control payloads vs baseline in the final comparison.
- `0x0E` and `0x0F`: alternate between two values, likely heartbeat/alive toggles. `0x0F` had one minor new payload but far lower confidence than `0x0C`.
- `0x16` and `0x17`: static across captures, likely configuration/version/status frames.

## XIAO ESP32-C3 State

The XIAO firmware, flashing, and USB logging pipeline are recovered. The remaining blocker is physical-layer conditioning into ESP32-C3 RX.

Observed diagnostic pattern:

- USB CDC heartbeat stable.
- `rx`, `breaks`, `syncerr`, and `skips` increase.
- `frames` remains `0`.
- Divider row 4 measured about `2.575 V`.

Interpretation: XIAO is seeing electrical activity, but the divided waveform is too marginal/noisy for reliable UART LIN decode. Treat this as a physical-layer problem, not a PlatformIO or USB problem, unless diagnostics change.

Known intended XIAO pins in the current firmware work:

- `D3/GPIO5`: LIN RX.
- `D2/GPIO4`: LIN TX.
- `D4/GPIO6`: CD4066B / active path control.

For passive receive next step, only `D3/GPIO5` and GND should matter, fed from LIN transceiver RXD.

Known-good PlatformIO settings:

```ini
platform = espressif32@6.9.0
board = seeed_xiao_esp32c3
framework = arduino
upload_protocol = esptool
upload_speed = 115200
monitor_speed = 115200
monitor_dtr = 0
monitor_rts = 0
build_flags =
  -DARDUINO_USB_MODE=1
  -DARDUINO_USB_CDC_ON_BOOT=1
  -DCORE_DEBUG_LEVEL=3
  -DCONFIG_UART_ISR_IN_IRAM=1
```

Direct esptool `--no-stub` at 115200 is the recovery path when PlatformIO upload is unstable.

## Hardware Decision

Current ordered equipment inventory and bench organization is saved in `docs/reports/tesla-lin-bench-equipment-inventory-2026-05-19.md`.

Abandoned path:

- Bare/tiny SOIC-8 TJA1020 breadboard attempt overheated badly. Do not continue that exact hardware path.
- Do not hand-wire or revive a loose tiny TJA chip by guessed pinout. That failure mode is exactly what the new bench plan is avoiding.

Recommended path:

- Use APGDT001 as the PC-side USB-LIN master/analyzer.
- Use a ready-made TJA1021-class or MC33662-class TTL UART to LIN transceiver breakout module only as the XIAO-side physical-layer interface, after measuring its pin labels and logic voltages.
- Recommended Amazon candidate from research/shopping: ASIN `B0F31584W1`, TJA1021-based TTL UART <-> LIN module.
- TJA1021/MC33662 class is appropriate for LIN 2.x / ISO 17987 12 V systems, 3.3 V logic, and up to 20 kBd. Tesla bus is 19.2 kBd.
- Avoid CAN transceiver modules. CAN is a different physical layer.
- Avoid USB-TTL-only adapters. They do not provide LIN physical-layer level shifting.
- Avoid RS485 modules. RS485 is differential and not LIN.

## Correct Receive Topology

For vehicle passive receive or bench passive receive:

```text
Vehicle or bench LIN wire
    -> LIN transceiver LIN pin

LIN transceiver RXD
    -> XIAO D3/GPIO5

Common ground
    -> XIAO GND and transceiver GND

Vehicle/bench LV rail
    -> transceiver VBAT only, fused/protected
```

Do not connect raw LIN to XIAO. Do not connect XIAO `D2` or `D4` during passive receive stabilization.

## Bench Mock Goal

Goal: continue work without the Tesla by reproducing the steering-wheel LIN cluster off-vehicle.

Core bench topology:

```text
12-15 V bench supply with current limit/fuse
    -> Tesla steering-wheel module green LV power
    -> LIN transceiver VBAT

Bench supply ground
    -> Tesla module black ground
    -> LIN transceiver ground
    -> XIAO ground

XIAO UART TX/RX
    -> LIN transceiver TXD/RXD

LIN transceiver LIN
    -> Tesla module white LIN
```

Bench master requirements:

- 19200 bps.
- LIN break at least 13 dominant bit times.
- Sync byte `0x55`.
- PID `0x4C` for ID `0x0C`.
- 8 data bytes plus enhanced checksum.
- Correct LIN master pull-up / termination: typically 1k plus diode from VBAT to LIN. Verify whether the module includes this; add it if not.

## Parts To Order Or Stage

Minimum:

- TJA1021 or MC33662 TTL-to-LIN module/breakout with separate VBAT, GND, LIN, TXD, RXD.
- Adjustable 0-20 V bench supply with current limiting, or known-good 12-15 V supply.
- Inline automotive fuse holder and 2-5 A blade fuses for Tesla module LV power.
- Small screw-terminal board or proto board for repeatable wiring.
- Jumper wires, labels, and non-destructive harness pigtails.
- DMM.

Strongly useful:

- Logic analyzer or oscilloscope with LIN decode. FX2/sigrok is acceptable if carefully decoded.
- Extra TJA1021/MC33662 modules so one failed board does not stop work.
- TVS / basic automotive transient protection components for the bench harness.
- Mating connector or sacrificial harness pigtail for the Tesla steering-wheel module if available.

Do not buy as substitutes:

- CAN transceiver module.
- RS485 module.
- Bare USB-TTL adapter.
- Random 12 V relay / optocoupler board marketed for automotive signals without LIN support.

## What Was Still Worth Capturing If The Vehicle Was Present

If the car is somehow still available, these are useful but not required enough to hold the vehicle indefinitely:

- Clear photos of SW connector orientation, pin numbering, wire colors, part labels, and module labels/barcodes.
- Green-to-black voltage in off, accessory/wake, and active/ready states.
- White LIN idle/min/max voltage to black ground, ideally scoped.
- Approximate module current draw if safe.
- No-touch baseline capture.
- Single-control captures for left scroll up/down, right controls, voice, turn signal/stalks, and other steering controls.
- Power-up/wake capture from cold/off to active.
- Restore SW connector fully seated and confirm no airbag/steering warnings.

The working decision already given: the Tesla did not need to be held once photos/restoration/no-warning checks were done.

## Tooling And Script State

Important local `lpt-schematics` scripts were improved during the session but may not have been committed in the doc-only push. Check their presence before depending on desktop copies:

- `firmware/anti-nag-v1/scripts/analyze-lin-capture.ps1`
- `firmware/anti-nag-v1/scripts/compare-lin-captures.ps1`
- `firmware/anti-nag-v1/scripts/flash-xiao-field.ps1`
- `firmware/anti-nag-v1/scripts/read-xiao-diagnostic.ps1`
- `firmware/anti-nag-v1/scripts/lin-payload-calc.py`

At the time of handoff, these were untracked or modified locally in the laptop `lpt-schematics` working tree and were deliberately not included in the two doc-only commits. If the desktop AI needs these tools and they are missing on desktop, copy them from the laptop repo or ask the owner before committing/staging broader work.

Useful script behavior:

- `analyze-lin-capture.ps1` reconstructs frames from raw sigrok break + UART byte annotations and reports per-capture varying IDs.
- `compare-lin-captures.ps1` ranks baseline-vs-event new payloads; the rerun ranked `0x0C` top.
- `lin-payload-calc.py` can verify/generate enhanced checksums and candidate payloads; keep generated payload use bench-only.

## Suggested Next Work Order For Desktop AI

1. Read this file first, then read `C:\Users\ezabz\Code\Schematics\firmware\anti-nag-v1\docs\model-x-xiao-lin-handoff-2026-05-18.md`.
2. Verify whether the desktop has the latest docs by checking the files listed above. Do not force-reset or clean the desktop repos.
3. If asked to continue hardware work, focus on a transceiver RXD -> XIAO D3 passive receive adapter.
4. If asked to order parts, recommend TJA1021/MC33662-class LIN module, 12-15 V bench supply/current limit, inline fuses, screw terminal/proto board, and analyzer/scope support. Mention ASIN `B0F31584W1` as the cheap Amazon candidate.
5. If asked to run analysis, use the seated, baseline, and single-control captures. Ignore targeted/debug folders unless specifically investigating failed commands.
6. If asked about active anti-nag/injection, answer that current evidence is bench-analysis-only; active work must wait until receive quality, attribution, bench replay, isolation, and non-customer validation gates pass.
7. If asked why XIAO is not decoding frames, explain physical layer margin: divider row 4 shows transitions but is not reliable enough for ESP32-C3 UART LIN decode; use proper LIN transceiver RXD.
8. Keep all customer-facing conclusions conservative: Model X refresh is not a supported customer install from this evidence alone.

## Confidence Gates Before Any Active Step

These gates must pass in order:

1. Passive capture quality gate: stable decoded frames with transceiver receive path and no persistent checksum/parity anomalies.
2. Attribution gate: repeated labeled datasets prove `0x0C` semantics better than all other IDs.
3. Bench replay gate: framing, PID, schedule, and enhanced checksum validated off-vehicle.
4. Isolation gate: active path hardware cannot unintentionally drive the bus.
5. Controlled non-customer validation gate: bounded reversible tests, no adverse vehicle effects.
6. Customer-car gate: explicit owner approval after all prior gates pass.

Current status: these gates have not all passed. Stay passive/bench-only.

## Short Answer If Owner Asks What We Know

We found a real 19.2 kbps LIN bus on the 2025 Model X steering-wheel `SW` connector white wire. The green wire is about 15.4 V LV power, black is ground, and `DAB` is airbag/SRS and must not be touched. The strongest control frame is ID `0x0C` / PID `0x4C`; B0 centers at `0x10`, rises for volume up, falls for volume down, B1 `0x04` looks like touch/engage, B6 is constant `0xC0`, and B7 is a rolling counter. Checksum is LIN enhanced. The customer car should remain research-only; next step is a TJA1021/MC33662 LIN transceiver module feeding clean RXD into XIAO D3 and a fused 12-15 V bench mock.

## Do Not Lose This Context

The practical reason this file exists: the desktop AI did not have enough context from the scattered docs. Keep this as the first briefing for future desktop chats about Tesla Model X LIN, XIAO, anti-nag, or Moti Zaks vehicle work.

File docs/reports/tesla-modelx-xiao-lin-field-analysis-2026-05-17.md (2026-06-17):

# Tesla Model X XIAO LIN Field Analysis (2026-05-17)

> **Status as of 2026-05-26: BENCH COMPLETE.** The blocker documented here (physical-layer signal conditioning / `frames=0`) has been resolved. A proper TJA1021 transceiver + level shifter was added and first clean LIN frame decoded: `#1 ID=0x3C data: 00 00 00 00 00 00 00 00 | chk=C3 OK`.
>
> **Active project is now `C:\Users\ezabz\Code\xiao-lin-bench`.**  
> This doc is preserved as the field evidence baseline and root-cause record.

---

## Scope

This document consolidates field observations, firmware state, serial diagnostics, and risk analysis for the 2025 Tesla Model X steering wheel LIN work performed on 2026-05-17.

Goal of this phase: establish reliable passive receive on XIAO ESP32-C3 and validate whether candidate LIN frame ID `0x0C` can be safely advanced toward controlled testing.

## Executive Summary

The firmware stack and flashing/logging pipeline are now operational and stable:

- Build succeeds on `espressif32@6.9.0`.
- Direct esptool `--no-stub` flashing at `115200` is reliable.
- USB CDC logging on COM6 is stable with ESP32-C3-specific flags enabled.

However, passive decode on the current resistor-divider tap is not yet valid:

- XIAO reads transitions (`rx` flips, `breaks` and `skips` rise).
- No valid LIN sync/PID decode (`frames=0`).
- Measured tap voltage `row4 -> GND = 2.575V` indicates the node is active and electrically safe, but likely marginal for robust UART-high discrimination on ESP32-C3 under in-vehicle noise/edge conditions.

Conclusion: software path is recovered; current blocker is physical-layer signal conditioning into XIAO RX.

## Live Hardware / Field Context

- Vehicle: 2025 Tesla Model X (Moti visit set)
- Proven candidate wire for passive LIN capture: SW white wire
- Passive divider chain in use: 4x10k ladder
- Current XIAO hookup:
  - `D3/GPIO5` -> divider row 4 (RX tap)
  - `GND` -> shared ground
  - `D2/GPIO4` and `D4/GPIO6` intentionally disconnected for passive mode
- Voltage:
  - `row4 -> GND = 2.575V`

Safety status for current customer-car work:

- Keep passive-only mode.
- Do not connect TX/injection path yet.
- Do not perform write/lock/injection actions until receive path is clean and frame semantics are reconfirmed.

## Firmware / Build State (Current)

External source tree in active use: `C:\Users\ezabz\Code\lpt-schematics\firmware\anti-nag-v1`

### platformio.ini

Current key settings:

- `platform = espressif32@6.9.0`
- `upload_protocol = esptool`
- `upload_speed = 115200`
- `monitor_dtr = 0`
- `monitor_rts = 0`
- `-DARDUINO_USB_MODE=1`
- `-DARDUINO_USB_CDC_ON_BOOT=1`
- BLE intentionally stubbed for field build stability

### Config and scan start

- `SCAN_ID_START = 0x0C`
- `SCAN_ID_END = 0x2F`
- Auto-scan starts at `0x0C` when no locked frame ID exists.

### Runtime diagnostics in loop heartbeat

Heartbeat reports include:

- `baud`, `inv`, `scan`, `candidate`, `known`
- `rx`
- `breaks`, `syncerr`, `skips`, `frames`
- `err`, `inj`

This instrumentation is sufficient to separate:

1. board dead / serial dead,
2. RX electrically dead,
3. RX active but decode-invalid.

Current state is (3).

## Verified Command Outcomes

### Flash / transport

Direct esptool no-stub write with verification succeeded after PlatformIO uploader instability.

Known stable command family (already validated during session):

- `--chip esp32c3 --port COM6 --baud 115200 --before usb_reset --after hard_reset --no-stub write_flash ...`

### Serial capture

Stable COM6 diagnostic capture returned repeating heartbeats, for example:

- `ALIVE #2 ... rx=1 breaks=157 syncerr=160 skips=3960 frames=0 ...`
- `ALIVE #3 ... rx=1 breaks=237 syncerr=240 skips=5880 frames=0 ...`
- `ALIVE #4 ... rx=1 breaks=317 syncerr=320 skips=7800 frames=0 ...`
- `ALIVE #5 ... rx=0 breaks=397 syncerr=401 skips=9720 frames=0 ...`

Interpretation:

- Data transitions are present.
- Parser is not seeing clean LIN sync/PID sequences.
- This is not a firmware boot crash or dead COM problem.

## Technical Root-Cause Analysis

Most probable cause chain:

1. Raw LIN waveform is being reduced via passive divider to a logic-level-adjacent tap.
2. At row4, idle sits near `2.575V`, only moderately above ESP32-C3 VIH threshold margin in real noisy automotive conditions.
3. Edge distortion/noise plus threshold margin causes UART byte stream corruption.
4. Stream shows activity but cannot consistently produce valid `0x55` sync and parity-valid PID.

Secondary contributors considered:

- Wrong baud: tested broadly during session, no decode win.
- RX inversion mismatch: attempted runtime inversion probe, resulted in instability and was rolled back.
- USB/serial transport issue: ruled out by stable heartbeat telemetry.

## Risks and Guardrails

### Immediate technical risks

- False confidence from "activity seen" without frame decode.
- Overstepping into injection with incomplete receive confidence.
- Raising tap voltage unsafely (for example by moving to a high divider node) and damaging XIAO GPIO.

### Operational guardrails

- Passive capture only on customer vehicle.
- Keep `D2` and `D4` disconnected until explicit bench validation gates are met.
- No frame lock/write action from candidate findings alone.

## Recommended Next Actions

### Priority A (field-safe)

1. Keep current wiring (`D3 + GND` only).
2. Add mild pull-up assist from row4 to XIAO `3V3` using ~`30k-47k` effective resistance to improve high-level margin without overdriving pin limits.
3. Re-capture heartbeat and evaluate whether `frames` starts incrementing.

### Priority B (preferred robust path)

1. Insert a proper LIN physical receiver stage (for example TJA1020-class transceiver RXD output) between vehicle LIN and XIAO RX.
2. Feed only cleaned logic-level RXD into `D3/GPIO5`.
3. Re-run passive decode metrics and compare frame quality with FX2 baseline.

### Priority C (validation/control)

1. Reconfirm control sensitivity of ID `0x0C` under repeatable input sequences.
2. Build byte-level transition matrix and entropy/time correlation before any lock/injection decision.
3. Keep customer-car testing non-invasive until deterministic control mapping is established.

## Open Questions

1. Exact row-level waveform shape at the XIAO pin (rise/fall, ringing, duty under load).
2. Whether Schmitt/comparator conditioning materially outperforms transceiver RXD for this setup.
3. Whether a software edge-time decoder on GPIO can recover frames if UART remains unreliable.

## Artifact Relationship

This report is the local evidence baseline. Research directives 044/045/046 extend this with external documentation and comparative engineering options, then synthesis should be folded back into this operating plan.

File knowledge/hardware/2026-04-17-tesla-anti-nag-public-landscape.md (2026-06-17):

---
title: "Tesla Anti-Nag Public Landscape - 2026 Snapshot"
date: 2026-04-17
category: research
tags: [tesla, anti-nag, autopilot, tsl5, tsl6, public-landscape, automotive]
status: in-progress
priority: high
related:
  - research/hardware/2026-04-17-tesla-research-set-overview.md
  - research/hardware/2026-04-17-tesla-tsl-family-reverse-engineering-map.md
  - research/hardware/2026-04-17-tesla-tsl-source-matrix.md
  - research/hardware/2026-04-17-tesla-tsl-vendor-family-timeline.md
  - research/hardware/2026-04-17-tesla-tsl-decision-memo.md
  - research/hardware/2026-04-17-tesla-tsl-bench-proof-plan.md
  - research/hardware/2026-04-17-tesla-anti-nag-vendor-map-and-diy-difficulty.md
  - hardware-diagnostics/intake-moti-zaks-tesla-modules-2026-04-15.md
case_type: customer-linked-research
customer_name: Moti Zaks
customer_phone: +17328061206
---

# Tesla Anti-Nag Public Landscape - 2026 Snapshot

## Purpose

This note expands the Tesla `TSL` research into the broader latest public ecosystem around Autopilot and FSD nag-reduction products, adjacent accessories, and public owner behavior.

This is a research map, not a field playbook. It is intended to capture what people appear to be using, how those methods are publicly framed, and where the ecosystem seems to be moving.

It does not document procedural camera interference, update pinning, or other tactical evasion workflows.

## Research Set Position

This is the current-market context note for the Tesla bundle.

Use it when the question is `what are people doing now`, not when the question is `what exactly is the seized board`.

## Customer / Case Linkage

- Customer: Moti Zaks
- Phone: (732) 806-1206
- Ticket: Unknown
- Order: Unknown
- Work Order ID: Unknown
- Related Case Log: hardware-diagnostics/intake-moti-zaks-tesla-modules-2026-04-15.md
- Related Main Note: research/hardware/2026-04-17-tesla-tsl-family-reverse-engineering-map.md
- Related Matrix: research/hardware/2026-04-17-tesla-tsl-source-matrix.md

## Executive Snapshot

- The public market no longer looks like a single anti-nag gadget category. It now looks like several overlapping method families.
- The older pattern was narrow steering-wheel-path hardware. The newer pattern is broader plug-style or app-linked ecosystems that advertise anti-nag as one feature among many.
- Compatibility claims are increasingly software-version-sensitive.
- The split between `basic Autopilot` and `FSD with stronger camera-era attention enforcement` now matters more than it did in older seller copy.
- Chinese vendor ecosystems look increasingly OTA-driven, mini-program-linked, and feature-bundled rather than one-device-one-function.

## Current Public Method Families

| Family | Public framing | Typical placement or surface | What is actually being claimed | Current internal take |
| --- | --- | --- | --- | --- |
| Manual driver compensation | Owner habit, not product | Hands on wheel or controls | Owners discuss satisfying nag requirements through driving behavior rather than hardware | Important context, but not a product family |
| Passive physical add-ons | `Buddy`, weight, or nag-reduction accessory | Steering wheel | Simple physical bias or wheel interaction substitutes remain openly sold | Oldest and bluntest public category |
| Steering-wheel-path electronics | `TSL2`, `TSL5`, steering-wheel auxiliary chips | Steering wheel connector area | Simulated wheel or scroll input through a local path | Best match for the seized `TSL5` board |
| Plug-style OBD or gateway modules | `TSL6` and similar | Rear console, OBD-like, passenger-side, or front hidden location depending on platform | Faster install, app linkage, broader feature bundles, still centered on nag reduction | Strongly looks like the later mainstream commercial family |
| Multifunction Tesla accessory platforms | `Commander`, `S3XY Buttons`, `S3XY Knob`, broader Chinese `6代模块` stack | App plus connected controller or gateway | Anti-nag-like behavior is advertised as one convenience feature among many automations | Shows the market is converging toward broader control ecosystems |

## What Feels Newer Than The Older TSL Story

### 1. App-linked ecosystems are replacing single-purpose boards

The older `TSL` story can be told as one hardware family at a time. The newer public picture is less tidy.

- The Chinese-side `TSL电子模块` ecosystem now looks like app plus firmware plus multi-product branding, not just one PCB label.
- Vendor-run Chinese posts describe push firmware updates, mini-program configuration, and linkage across `6代模块`, `非凡司令官 / 非凡指挥官`, and adjacent modules such as `WL5`.
- Late-2025 Chinese posts explicitly advertise firmware support against Tesla software `2025.38.11`, which means the ecosystem is now openly competing on update cadence.

### 2. OBD or gateway-style devices are being sold as the easy mainstream option

Owner reports and seller pages now consistently frame `TSL6`-class devices as the easier install path compared with steering-wheel teardown.

- Tesla Motors Club owner reports describe `TSL6` as a daisy-chained rear or OBD-style module.
- Seller pages market `TSL6` around fast install, OTA support, and version compatibility.
- This newer family appears to have become the commercial default for `Model 3/Y`-type fitments.

### 3. Anti-nag is being absorbed into broader feature stacks

Enhance Auto's `Buttons` and `Commander` ecosystem is not marketed as a single anti-nag gadget. It is marketed as a broad Tesla control platform with many shortcuts and automations.

- Public reviews and community posts describe `continuous autopilot` as one feature inside a larger automation stack.
- The official product page emphasizes high action count, app macros, and commander-based integration rather than a single-purpose nag device.
- This suggests a broader market trend: anti-nag behavior is becoming bundled into multi-feature controllers instead of being sold only as standalone modules.

### 4. Software whiplash is now part of the product category itself

Public discussion increasingly treats compatibility as temporary rather than fixed.

- Owner discussion on Tesla Motors Club says scroll-wheel acknowledgement behavior degraded on `FSD v12`-era releases while still working for some `AP` use cases.
- Public seller copy now repeatedly qualifies products with phrases like `AP only`, `not FSD`, or `works if scroll-wheel acknowledgement works on your car`.
- The market is responding by advertising updates, OTA support, and newer fitment claims for `Highland`, `Juniper`, and refreshed `S/X` vehicles.

## High-Level Public `How`

At a non-procedural level, the public ecosystem appears to cluster around three mechanism stories:

### Wheel-input satisfaction

Many public products and owner descriptions still revolve around the idea that a valid wheel-side interaction is enough to satisfy the system in some modes or software versions.

This is the strongest public story behind `TSL2`, `TSL5`, and many seller descriptions of `TSL6`.

### Gateway or command-surface integration

Newer products increasingly present themselves as connected controllers that sit on a broader vehicle-access path and trigger multiple software-facing conveniences, with nag reduction as only one result.

This is the strongest public story behind `TSL6` and Commander-class products.

### Attention-system boundary management

Recent owner chatter shows a growing split between what works against simple wheel or torque prompts and what no longer works once stronger camera-based attention logic becomes the real limiter.

This is the most important reason the `AP` versus `FSD` distinction is now central.

## What The Latest Public Sources Are Actually Saying

### Tesla Motors Club owner reports

- `TSL6` is being discussed as the easier plug-style successor to older wheel-installed solutions.
- Some owners say it works well for `AP` while not solving stronger `FSD` attention enforcement.
- Some owners describe scroll-wheel toggle behavior and pairing or control paths that line up with older `TSL` claims.
- The same thread shows that users increasingly think in terms of firmware drift and temporary effectiveness.

### Seller pages and marketplaces

- `TSL6` is now marketed with `Highland`, `Juniper`, and late-model fitment language.
- Listings increasingly qualify compatibility with phrases like `AP only` or `works only if turning the scroll wheel clears the warning on your car`.
- Older wheel-centric devices are still sold, but the higher-visibility marketing energy is now around faster install and broader convenience language.

### Chinese vendor ecosystem

- `TSL电子模块` appears as a mini-program or app name, not just a PCB label.
- `6代模块`, `非凡司令官 / 非凡指挥官`, and adjacent modules like `WL5` are being sold as updateable, Bluetooth-capable, app-configurable systems.
- The ecosystem increasingly markets custom buttons, linked modules, and other non-core features, which makes it feel more like a platform than a single nag-removal device.

### Adjacent mainstream accessory ecosystem

- `S3XY Buttons` and `Commander` show that the commercial space around Tesla convenience automation is now mature enough that AP-related features can be marketed as one small subset of a much wider control surface.
- This is important because it means future Tesla `TSL` work should not be framed only as `anti-nag hardware`. The broader market is converging toward programmable Tesla-side control ecosystems.

## What This Means For The Repo's TSL Interpretation

- `TSL5` now looks even more like an older or narrower wheel-path family rather than the state of the art.
- `TSL6` looks less like `the next board number` and more like a later market phase: easier install, broader feature bundling, stronger app identity, and heavier software-compatibility marketing.
- The Chinese `TSL电子模块` and `6代模块` material suggests that later public `TSL` branding may be inseparable from the vendor's software ecosystem.
- Future Tesla notes in this repo should treat `anti-nag` as one slice of a broader Tesla accessory-control market, not the whole picture.

## Safety And Analysis Boundary

This note intentionally stops short of operational tactics.

- It does not document camera-coverage workflows.
- It does not document update-avoidance or firmware-pinning tactics.
- It does not document field-install steps.

Those tactics are increasingly present in public chatter, but they are not needed to understand the product landscape or to classify the seized board correctly.

## Source Base Used For This Snapshot

- Tesla Motors Club owner discussion on anti-nag devices and later software behavior
- Evooor seller pages and news posts for `TSL6`
- AliExpress and other marketplace snippets for late-model `TSL6` and wheel-based products
- Enhance Auto `Buttons` and `Commander` product material and public reviews
- Chinese-language Bilibili vendor posts for `TSL电子模块`, `6代模块`, `非凡司令官 / 非凡指挥官`, and `WL5`

## Internal Recommendation

Use this note as the repo's answer to `what are people doing now`.

Use the family map and source matrix when the question is `what exactly is this seized board`.

Use the bench proof plan when the question is `what should we physically test next`.

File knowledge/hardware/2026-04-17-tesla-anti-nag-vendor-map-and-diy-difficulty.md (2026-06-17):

---
title: "Tesla Anti-Nag Vendor Map And DIY Difficulty"
date: 2026-04-17
category: research
tags: [tesla, vendor-map, diy-difficulty, anti-nag, autopilot, automotive]
status: in-progress
priority: high
related:
  - research/hardware/2026-04-17-tesla-research-set-overview.md
  - research/hardware/2026-04-17-tesla-anti-nag-public-landscape.md
  - research/hardware/2026-04-17-tesla-tsl-vendor-family-timeline.md
  - research/hardware/2026-04-17-tesla-tsl-source-matrix.md
  - research/hardware/2026-04-17-tesla-tsl-family-reverse-engineering-map.md
  - research/hardware/2026-04-17-tesla-tsl-decision-memo.md
  - hardware-diagnostics/intake-moti-zaks-tesla-modules-2026-04-15.md
  - docs/customer-operations/sync-records/tesla-modules-moti-zaks-2026-04-15.json
case_type: customer-linked-research
customer_name: Moti Zaks
customer_phone: +17328061206
---

# Tesla Anti-Nag Vendor Map And DIY Difficulty

## Purpose

This note answers two current questions from the public-source side:

1. Which companies or brands appear to be the main current players in this space?
2. At a high level, how hard would it be to make one yourself?

This is a market and engineering-effort note only. It does not provide a build recipe, schematic, firmware design, installation sequence, or field-evasion workflow.

## Research Set Position

This is the vendor-role and difficulty note for the Tesla bundle.

Use it for maker-versus-seller attribution and high-level engineering effort, not for seized-board identification or exact architecture claims.

## Customer / Case Linkage

- Customer: Moti Zaks
- Phone: (732) 806-1206
- Ticket: Unknown
- Order: Unknown
- Work Order ID: Unknown
- Related Case Log: hardware-diagnostics/intake-moti-zaks-tesla-modules-2026-04-15.md
- Related Main Note: research/hardware/2026-04-17-tesla-tsl-family-reverse-engineering-map.md
- Related Landscape Note: research/hardware/2026-04-17-tesla-anti-nag-public-landscape.md

## Scope Warning

The public market mixes actual makers, ecosystem operators, brands, affiliate sellers, and generic storefront resellers.

So this note distinguishes:

- `maker-like`: strong public evidence that the brand designs or owns the platform or ecosystem
- `brand-distributor`: a distinct brand that markets and sells the category but is not clearly proven to be the OEM
- `reseller`: a storefront repeating the category without clear evidence of original engineering ownership

## Short Answer

If the question is `who really seems to matter right now`, the strongest names from public sources are:

- `Enhance Auto` for the mainstream multifunction controller ecosystem
- `AP PAPA` for physical nag-reduction phone-holder style products
- `非凡科技FPV` and the `TSL电子模块 / 6代模块 / 非凡司令官 / 非凡指挥官` ecosystem for the later Chinese OTA mini-program stack
- `T-Launch` and `Evooor` as visible sellers of `TSL6`-class products in the Western-facing market

If the question is `how hard is it to make one`, the answer depends heavily on which type:

- physical wheel-bias accessory: relatively easy compared with everything else
- narrow wheel-path electronics like older `TSL5`-style products: hard, but not insane for an experienced embedded reverse engineer
- modern plug-style or OBD controller with software resilience: very hard
- full current-market ecosystem with app, OTA, cross-model support, and constant compatibility upkeep: extremely hard

## Vendor Map

| Brand or company | Best current role | Main public evidence | Current confidence | Notes |
| --- | --- | --- | --- | --- |
| `Enhance Auto` | Maker-like platform owner | Official `S3XY` pages and blogs describe the `Commander` as `the brain behind all S3XY products`, with OTA updates, app integration, and automations including `Continuous Autopilot` | Strong | This is clearly more than a reseller. It looks like a real product platform company. |
| `AP PAPA` | Maker-like nag-reduction brand | Official site says `after spending years on research & design, we have developed` the nag-reduction device line; product family spans Tesla plus Ford and Volvo | Moderate to strong | Public evidence supports treating this as a real product brand, though full OEM manufacturing arrangements are still not public. |
| `非凡科技FPV` | Maker-like or ecosystem-operator brand | Official Bilibili account pushes dated firmware updates, app or mini-program updates, synchronized release notes, and feature bundles across `6代模块`, `非凡司令官`, `非凡指挥官`, and related modules | Strong | This is the clearest public operator of the later Chinese `TSL电子模块` ecosystem. |
| `TSL电子模块` | Software and ecosystem label, not just one board | Public Chinese posts treat it as the mini-program or app surface for updates and settings | Strong | Better understood as a software-facing ecosystem name than as a standalone company. |
| `T-Launch` or `Teslaunch` | Brand-distributor, possibly private-label seller | Official store and official social media presence sell `TSL6` products and related accessories, but public evidence does not clearly prove original engineering ownership | Moderate | Important public-facing seller, but do not automatically treat it as the OEM. |
| `Evooor` | Brand-distributor or curated seller | Official collection and blogs market `TSL6` anti-nag products, fitment, and compatibility language | Moderate | Publicly visible seller with its own content marketing, but no strong evidence that it designed the hardware. |
| `EVAAM` | Reseller or distributor | Sells `AP PAPA` products under an `Autopilot Buddy & Nag Elimination` category | Strong | Best treated as a reseller channel, not the original design owner. |
| `AFA Motors`, `Hautosport`, `JAAutoUSA`, similar storefronts | Reseller | Multiple storefronts repeat near-identical steering-wheel module listings with little evidence of original engineering identity | Moderate | These look more like cloned or syndicated store listings than primary makers. |

## Main Companies By Product Class

### 1. Mainstream multifunction controller ecosystem

The clearest name here is `Enhance Auto`.

- Official material presents `Commander` as the core brain behind a larger `S3XY` ecosystem.
- Public sources explicitly connect it to `Continuous Autopilot` and many other automation features.
- This is not being sold as one narrow anti-nag device. It is sold as a Tesla control platform.

Internal read:

- This is a real engineering company in the adjacent market, not a thin storefront.
- It matters because it shows where the market is going: broader Tesla control platforms instead of one-purpose anti-nag boards.

### 2. Physical nag-reduction holder category

The clearest name here is `AP PAPA`.

- Official site frames the products as `nag reduction device & cellphone holder` combinations.
- It spans multiple variants such as `Lite`, `Standard`, `Pro`, `MagSafe`, and `Yoke`.
- The same brand also markets similar concept products for non-Tesla vehicles, which makes it look like a distinct brand family rather than a one-off Tesla accessory page.

Internal read:

- This appears to be a product brand with its own category identity.
- It is a different class from the later `TSL6` ecosystem and from `Commander`-style OBD controllers.

### 3. Chinese OTA mini-program and module ecosystem

The strongest public operator here is `非凡科技FPV`, with ecosystem labels including:

- `TSL电子模块`
- `6代模块`
- `非凡司令官`
- `非凡指挥官`
- `WL5`

Why this matters:

- Public posts are dated and update-oriented, not just static listings.
- The same account announces firmware compatibility with Tesla software `2025.38.11` and synchronized pushes through the `TSL电子模块` mini-program.
- The ecosystem is marketed as a growing stack of features, modules, remote controls, Bluetooth buttons, and settings rather than a single anti-nag part.

Internal read:

- This is the strongest current evidence of a maker-like Chinese ecosystem behind later `TSL6`-era products.
- If one wants to understand where the TSL market ended up, this stack matters more than any one reseller.

### 4. Western-facing `TSL6` seller layer

The most visible names are `T-Launch` and `Evooor`.

- `T-Launch` publicly rebrands from `Teslaunch` and is repeatedly linked in videos and listings around `TSL6`.
- `Evooor` maintains `TSL6` product pages, compatibility posts, and anti-nag collections.

Internal read:

- These are important commercial channels.
- But public evidence is weaker that they are the original engineering source.
- At present they are better treated as visible brand-distributors than as confirmed OEMs.

## If You Mean `Who Actually Makes The Hardware?`

Public evidence is strongest for these conclusions:

- `Enhance Auto` clearly makes or owns its own controller ecosystem.
- `非凡科技FPV` clearly operates the later Chinese module and app ecosystem.
- `AP PAPA` likely owns a real product line in the physical-holder category.
- `T-Launch`, `Evooor`, and many similar storefronts are easier to prove as sellers than as original hardware makers.

That distinction matters because the public market is full of duplicated listings and affiliate-driven pages.

## How Hard Would It Be To Make One Yourself?

## Difficulty Table

| Product target | High-level difficulty | Why |
| --- | --- | --- |
| Simple physical wheel-bias holder or accessory | Low to medium | Mechanical design, fitment, and user ergonomics are the main issues, not deep embedded control |
| Older narrow steering-wheel-path electronics | Medium-high to high | Requires reverse engineering the wheel-side path, reliable embedded behavior, packaging, and model fitment |
| Plug-style `TSL6`-class module | High to very high | Requires broader vehicle integration, fitment variation, more software logic, and stronger compatibility handling |
| `Commander`-class multifunction Tesla controller | Very high | Requires hardware, app, OTA, automation framework, product QA, and constant software maintenance |
| Current market-ready platform with cross-model support and frequent updates | Extreme | The hard part becomes long-term maintenance, compatibility drift, support burden, and regression testing, not just one prototype board |

## Practical Engineering Read

### Easiest category to replicate

The easiest category is the physical nag-reduction holder class.

Why:

- Mostly mechanical
- No deep Tesla-side protocol stack required
- No OTA or app layer required

Why it is still a weak target:

- It is the least interesting technically
- It is the least aligned with where the market is moving
- It is also less relevant once attention enforcement shifts away from simple wheel prompts

### Hard but still plausible as a narrow research project

An older `TSL5`-style narrow wheel-path module is hard but not absurd as a lab reverse-engineering project.

What makes it hard:

- You need to identify the actual wheel-side path correctly
- Model and year variation can break assumptions quickly
- You need robust behavior under automotive electrical conditions
- Wireless control and app linkage add another layer if included

Internal read:

- For an experienced embedded and automotive reverse engineer, a narrow proof-of-concept is plausible.
- For a generalist starting from scratch, it is not a quick weekend project.

### Where it becomes genuinely difficult

The modern `TSL6` or `Commander` phase is much harder than a single board suggests.

The hard parts are:

- cross-model and cross-year fitment
- reacting to Tesla software changes
- handling `AP` versus `FSD` behavior drift
- maintaining app or mini-program control surfaces
- OTA delivery and update safety
- customer-facing support and documentation

This is why the later Chinese ecosystem now advertises firmware pushes and synchronized updates. The difficulty is not only hardware anymore. It is maintenance.

## Clean Bottom Line On DIY Difficulty

If your goal is:

- `one-off lab curiosity`: hard but plausible for a narrow older wheel-path product class
- `something current and robust`: very hard
- `a product that competes with the current market leaders`: extremely hard

The main reason is not that the electronics are magically impossible. The main reason is that Tesla-side behavior keeps shifting, and the commercially serious players are now solving a moving compatibility problem, not just a one-time hardware problem.

## Best Current Internal Answer

The main publicly visible companies in this space are not all equal.

- Treat `Enhance Auto` as the clearest mainstream controller-platform company.
- Treat `AP PAPA` as the clearest physical nag-reduction product brand.
- Treat `非凡科技FPV` and the `TSL电子模块 / 6代模块 / 非凡` stack as the clearest late Chinese maker-like ecosystem.
- Treat `T-Launch` and `Evooor` as important seller brands, but not automatically as the hardware OEM.

And on the DIY question:

- copying an old narrow category is much easier than matching the current market
- matching the current market means solving hardware, software, app surface, update cadence, and compatibility drift together
- that is why making one for research is one thing, and making a current competitive product is a very different level of difficulty

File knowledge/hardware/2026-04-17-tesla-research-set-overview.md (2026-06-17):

---
title: "Tesla Research Set Overview"
date: 2026-04-17
category: research
tags: [tesla, overview, navigation, reverse-engineering, automotive]
status: in-progress
priority: high
related:
  - research/hardware/2026-04-17-tesla-tsl-family-reverse-engineering-map.md
  - research/hardware/2026-04-17-tesla-tsl-source-matrix.md
  - research/hardware/2026-04-17-tesla-tsl-vendor-family-timeline.md
  - research/hardware/2026-04-17-tesla-tsl-decision-memo.md
  - research/hardware/2026-04-17-tesla-tsl-bench-proof-plan.md
  - research/hardware/2026-04-17-tesla-tsl-bench-session-worksheet.md
  - research/hardware/2026-04-18-tesla-multi-board-diagnostic-comparison-plan.md
  - research/hardware/2026-04-18-tesla-multi-board-comparison-worksheet.md
  - research/hardware/2026-04-17-tesla-anti-nag-public-landscape.md
  - research/hardware/2026-04-17-tesla-anti-nag-vendor-map-and-diy-difficulty.md
  - external-research/2026-04-15-tsl5-ch571f-return-review/INDEX.md
  - external-research/2026-04-15-tsl5-ch571f-return-review/2026-04-15-vetted-synthesis.md
  - hardware-diagnostics/intake-moti-zaks-tesla-modules-2026-04-15.md
  - docs/customer-operations/sync-records/tesla-modules-moti-zaks-2026-04-15.json
case_type: customer-linked-research
customer_name: Moti Zaks
customer_phone: +17328061206
---

# Tesla Research Set Overview

## Purpose

This note is the navigation layer for the Tesla research bundle in this repo.

Use it when the question is not yet `what is the answer`, but `which Tesla note should I open first`.

This research set now covers:

- seized-board identification
- public family lineage
- strict evidence classification
- later market and vendor evolution
- bench-priority planning
- live worksheet execution

## Customer / Case Linkage

- Customer: Moti Zaks
- Phone: (732) 806-1206
- Ticket: Unknown
- Order: Unknown
- Work Order ID: Unknown
- Related Case Log: hardware-diagnostics/intake-moti-zaks-tesla-modules-2026-04-15.md
- Related Sync Record: docs/customer-operations/sync-records/tesla-modules-moti-zaks-2026-04-15.json
- Intake Summary: Customer brought Tesla-related hardware that now appears to be a small `TSL5` board and harness assembly rather than loose Tesla battery modules.

## Current Set Status

The Tesla document set is now organized into one flagship synthesis plus supporting notes for evidence, chronology, market context, and next-step execution.

The flagship answer remains:

- `2026-04-17-tesla-tsl-family-reverse-engineering-map.md`

Everything else either supports, stress-tests, expands, or operationalizes that note.

## Related External Review Folder

The related external research folder is:

- `external-research/2026-04-15-tsl5-ch571f-return-review/`

Use that folder for upstream returned-research triage and citation history.

Use this internal bundle for the current repo working position.

## Recommended Reading Order

If opening this set cold, read in this order:

1. `2026-04-17-tesla-tsl-family-reverse-engineering-map.md`
2. `2026-04-17-tesla-tsl-source-matrix.md`
3. `2026-04-17-tesla-tsl-vendor-family-timeline.md`
4. `2026-04-17-tesla-tsl-decision-memo.md`
5. `2026-04-17-tesla-anti-nag-public-landscape.md`
6. `2026-04-17-tesla-anti-nag-vendor-map-and-diy-difficulty.md`
7. `2026-04-17-tesla-tsl-bench-proof-plan.md`
8. `2026-04-17-tesla-tsl-bench-session-worksheet.md`

If multiple boards are on hand, insert these before the single-board bench notes:

1. `2026-04-18-tesla-multi-board-diagnostic-comparison-plan.md`
2. `2026-04-18-tesla-multi-board-comparison-worksheet.md`

## By Question

### What is the seized board?

- Start with `2026-04-17-tesla-tsl-family-reverse-engineering-map.md`
- Then use `2026-04-17-tesla-tsl-source-matrix.md`

### Which claims are actually well supported?

- Use `2026-04-17-tesla-tsl-source-matrix.md`
- Then confirm wording in `2026-04-17-tesla-tsl-decision-memo.md`

### How did the market evolve from older TSL labels to the newer ecosystem?

- Use `2026-04-17-tesla-tsl-vendor-family-timeline.md`
- Then use `2026-04-17-tesla-anti-nag-public-landscape.md`

### What are people doing now, and what changed in 2025 to 2026?

- Use `2026-04-17-tesla-anti-nag-public-landscape.md`
- Then use the late rows in `2026-04-17-tesla-tsl-source-matrix.md`

### Who looks like an actual maker versus a seller or reseller?

- Use `2026-04-17-tesla-anti-nag-vendor-map-and-diy-difficulty.md`
- Then use `2026-04-17-tesla-tsl-vendor-family-timeline.md`

### What should be said confidently versus conditionally?

- Use `2026-04-17-tesla-tsl-decision-memo.md`

### What should be tested next on the physical board?

- Use `2026-04-17-tesla-tsl-bench-proof-plan.md`
- Then run the session using `2026-04-17-tesla-tsl-bench-session-worksheet.md`

### How should multiple boards be compared before picking one to deep-dive?

- Use `2026-04-18-tesla-multi-board-diagnostic-comparison-plan.md`
- Then run the session using `2026-04-18-tesla-multi-board-comparison-worksheet.md`

## Note Roles

| Note | Role | Best use |
| --- | --- | --- |
| `2026-04-17-tesla-tsl-family-reverse-engineering-map.md` | Flagship synthesis | Best single-file answer to `what do we think this is` |
| `2026-04-17-tesla-tsl-source-matrix.md` | Strict evidence base | Best file for confidence discipline and claim tagging |
| `2026-04-17-tesla-tsl-vendor-family-timeline.md` | Chronology and phase map | Best file for market evolution and lineage order |
| `2026-04-17-tesla-tsl-decision-memo.md` | Wording boundary | Best file for future note-writing discipline |
| `2026-04-17-tesla-anti-nag-public-landscape.md` | Latest ecosystem map | Best file for `what are people doing now` |
| `2026-04-17-tesla-anti-nag-vendor-map-and-diy-difficulty.md` | Vendor and difficulty view | Best file for `who matters` and `how hard would it be` |
| `2026-04-17-tesla-tsl-bench-proof-plan.md` | Ranked test strategy | Best file for planning the next physical session |
| `2026-04-17-tesla-tsl-bench-session-worksheet.md` | Live capture template | Best file for executing a bench session cleanly |
| `2026-04-18-tesla-multi-board-diagnostic-comparison-plan.md` | Comparison-first strategy | Best file for deciding how to work through several boards in one project |
| `2026-04-18-tesla-multi-board-comparison-worksheet.md` | Multi-board live capture template | Best file for comparing boards before choosing the deepest target |

## Current Internal Bottom Line

- The seized board is still best classified as a `TSL5` family board.
- The family separation between `TSL2`, `TSL5`, and `TSL6` is stronger than any exact signal-path proof.
- The public market has moved beyond single-purpose anti-nag boards toward broader controller ecosystems, OTA updates, and app-linked product stacks.
- The biggest remaining uncertainty is physical board behavior, not internet-side taxonomy.

## Organization Rule For Future Updates

When new Tesla evidence comes in, update in this order:

1. `2026-04-17-tesla-tsl-source-matrix.md`
2. `2026-04-17-tesla-tsl-family-reverse-engineering-map.md`
3. whichever supporting note is actually affected:
   - timeline
   - landscape
   - vendor map
   - decision memo
   - bench plan
4. `research/hardware/INDEX.md`

This keeps the evidence base primary and prevents the overview notes from drifting away from the matrix.

## Current Bundle Inventory

- `2026-04-17-tesla-tsl-family-reverse-engineering-map.md`
- `2026-04-17-tesla-tsl-source-matrix.md`
- `2026-04-17-tesla-tsl-vendor-family-timeline.md`
- `2026-04-17-tesla-tsl-decision-memo.md`
- `2026-04-17-tesla-tsl-bench-proof-plan.md`
- `2026-04-17-tesla-tsl-bench-session-worksheet.md`
- `2026-04-18-tesla-multi-board-diagnostic-comparison-plan.md`
- `2026-04-18-tesla-multi-board-comparison-worksheet.md`
- `2026-04-17-tesla-anti-nag-public-landscape.md`
- `2026-04-17-tesla-anti-nag-vendor-map-and-diy-difficulty.md`

## Best Current Use

If a future session only opens one Tesla note, open the family map.

If a future session needs to verify a claim, open the source matrix.

If a future session is at the bench, open the worksheet.

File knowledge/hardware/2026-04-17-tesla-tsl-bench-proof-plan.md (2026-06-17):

---
title: "Tesla TSL Bench-First Proof Plan"
date: 2026-04-17
category: research
tags: [tesla, tsl5, tsl6, bench-plan, reverse-engineering, automotive, hardware]
status: in-progress
priority: high
related:
  - research/hardware/2026-04-17-tesla-research-set-overview.md
  - research/hardware/2026-04-17-tesla-tsl-family-reverse-engineering-map.md
  - research/hardware/2026-04-17-tesla-tsl-source-matrix.md
  - research/hardware/2026-04-17-tesla-tsl-decision-memo.md
  - research/hardware/2026-04-17-tesla-tsl-bench-session-worksheet.md
  - research/hardware/2026-04-18-tesla-multi-board-diagnostic-comparison-plan.md
  - research/hardware/2026-04-18-tesla-multi-board-comparison-worksheet.md
  - hardware-diagnostics/intake-moti-zaks-tesla-modules-2026-04-15.md
  - docs/customer-operations/sync-records/tesla-modules-moti-zaks-2026-04-15.json
case_type: customer-linked-research
customer_name: Moti Zaks
customer_phone: +17328061206
---

# Tesla TSL Bench-First Proof Plan

## Purpose

This note turns the remaining Tesla `TSL5` mechanism uncertainty into a ranked bench program.

The goal is not to make the module work in a car. The goal is to collapse uncertainty at the board level, with the fewest destructive steps and the highest information gain per hour.

## Current Hold — 2026-05-10

- Source docs were reconciled from this curated set, `C:\Users\ezabz\Code\lpt-hub`, old chat context, and `C:\Users\ezabz\Code\Schematics`.
- The exact `SCROLL_WHEEL_FRAME_ID` and payload are still unknown.
- The Schematics passive vehicle-sniffer branch exists and uses XIAO `D3/GPIO5` through a 4x10k divider, but its three saved 2026-05-10 captures produced `0` LIN frames.
- `sigrok-cli` is installed and the FX2 analyzer scans as `fx2lafw:conn=1.40`.
- The active TJA1020 bench wiring path is paused until the generic TJA1020 breadboard guide is reconciled with the board-measured `SH1020F2S` / TJA1020-family pin map.
- Do not call for a Tesla visit until the passive divider, COM29 sniffer, and backprobe kit are preflighted.

## Research Set Position

This is the planning layer between the synthesis notes and the live worksheet.

Use it after the family map, source matrix, and decision memo have defined what still needs proof.

If multiple boards are available, start with the multi-board comparison plan and worksheet first, then come back to this note for the one board selected as the best deep-dive target.

## Customer / Case Linkage

- Customer: Moti Zaks
- Phone: (732) 806-1206
- Ticket: Unknown
- Order: Unknown
- Work Order ID: Unknown
- Related Case Log: hardware-diagnostics/intake-moti-zaks-tesla-modules-2026-04-15.md
- Related Sync Record: docs/customer-operations/sync-records/tesla-modules-moti-zaks-2026-04-15.json
- Related Main Note: research/hardware/2026-04-17-tesla-tsl-family-reverse-engineering-map.md
- Related Source Matrix: research/hardware/2026-04-17-tesla-tsl-source-matrix.md

## Operating Rules

- Stay non-destructive until the continuity and trace picture is complete.
- Prefer measurements that collapse multiple theories at once.
- Treat public internet claims as hypothesis generators, not proof.
- Do not escalate to vehicle-side testing until the bench evidence says which wired path actually matters.

## Ranked Checks

| Rank | Check | Main Question Resolved | Expected Info Gain | Risk |
| --- | --- | --- | --- | --- |
| 1 | Full harness and connector truth table | Is the seized board truly using a 3-wire path, and is `DOUT` actually present in the installed assembly? | Very high | Very low |
| 2 | Sterile power and BLE re-test | Did the earlier `FNB58` advertiser belong to the board, and what does the module expose when isolated? | Very high | Very low |
| 3 | Rail map and current-state profile | Is the board a simple BLE tag, or a more serious wired interface board with multiple powered domains? | High | Low |
| 4 | Underside trace map and component-role pass | Do the TI device, SOIC-8, inductor, and regulator support an inline wired-interface architecture? | High | Low |
| 5 | Passive BLE and app-surface inventory | Does the firmware or BLE surface directly expose `TSL电子模块`, versioning, update flow, or user-control clues? | Medium-high | Low |
| 6 | Passive wired-signal capture only after the above | Is the wired path consistent with observation, translation, or injection? | High | Medium |

## Check 1: Full Harness And Connector Truth Table

### Objective

Create one definitive map from connector cavity to wire color to PCB net to labeled pad.

### Why this is first

This single step has the best chance of collapsing the `inline proxy` versus `parallel observer` versus `one-way injector` debate.

### Minimum output

- Connector shell size and cavity count
- Which cavities are populated
- Which conductor lands on `DIN`, `DOUT`, `VCC`, and `GND`
- Whether `DOUT` is only a pad, only a test point, or actually routed to the observed harness

### What would change the model fast

- If the installed harness really omits `DOUT`, the board starts looking less like a classic full inline proxy.
- If `DOUT` is routed but simply absent on the currently photographed lead, the inline theory stays much stronger.

## Check 2: Sterile Power And BLE Re-Test

### Objective

Repeat the power-up in a clean RF environment and verify what the board itself advertises.

### Why this matters

The earlier `FNB58` result is useful but still not clean enough to treat as settled.

### Minimum output

- Bench supply voltage and current at idle
- Whether a BLE advertiser appears at all
- Advertised name, manufacturer data, services, and writable or notifiable characteristics if present
- Whether the board's BLE surface changes after power cycling or waiting

### What would change the model fast

- A repeatable `TSL`- or vendor-linked BLE surface would strengthen the `CH571F hosts user-facing control` picture.
- No advertiser at all would push attention back toward wake conditions, alternate radio behavior, or a mistaken earlier attribution.

## Check 3: Rail Map And Current-State Profile

### Objective

Identify the board's powered domains and whether the wireless and wired sides look independently meaningful.

### Minimum output

- Regulator output voltage
- Static current in idle state
- Any current change during BLE advertising or user interaction
- Which major ICs sit on the regulated rail versus the incoming supply

### Why this matters

This is the fastest way to separate a trivial radio board from a real vehicle-interface board.

## Check 4: Underside Trace Map And Component-Role Pass

### Objective

Use sharp underside imagery and continuity work to connect the major silicon blocks to the labeled nets.

### Minimum output

- Trace path from connector to TI-marked TSSOP-16
- Trace path from connector to SOIC-8
- Trace path from connector to `CH571F`
- Any obvious isolation, level shifting, or power-switching features

### Why this matters

Right now the broad architecture is still inferred from top-side clues. One clean underside pass could settle whether the TI device is on the main wired path or just supporting power or switching.

## Check 5: Passive BLE And App-Surface Inventory

### Objective

Inventory the software-facing setup surface without assuming the app must stay connected during normal operation.

### Minimum output

- BLE UUID inventory
- Characteristic permissions and notify or write roles
- Any readable strings, firmware identifiers, or update endpoints
- Any visible linkage to `TSL电子模块`, `蓝牙版`, or the Chinese mini-program ecosystem
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

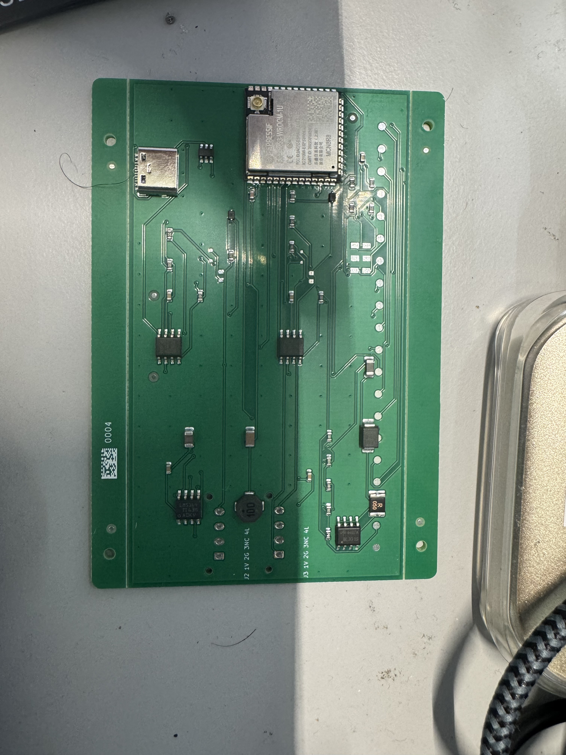
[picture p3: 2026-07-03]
photos/rev-a-first-article-2026-06-16/tesla-dual-lin-rev-a-board-arrival-01.jpg

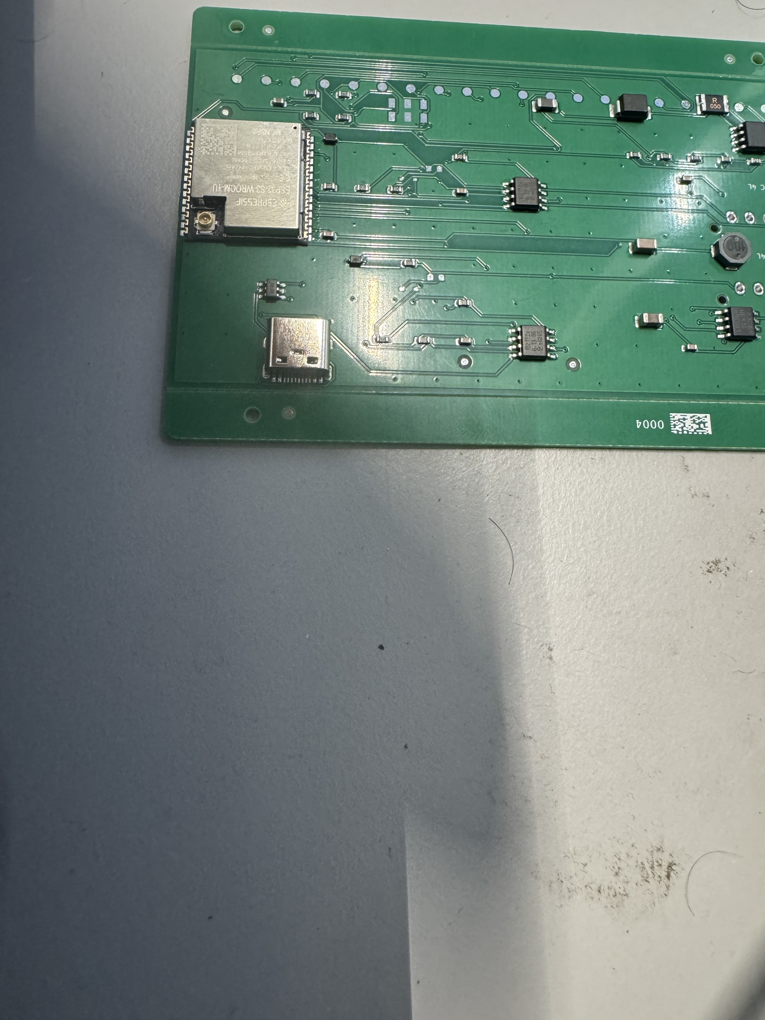
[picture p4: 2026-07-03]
photos/rev-a-first-article-2026-06-16/tesla-dual-lin-rev-a-board-arrival-04.jpg

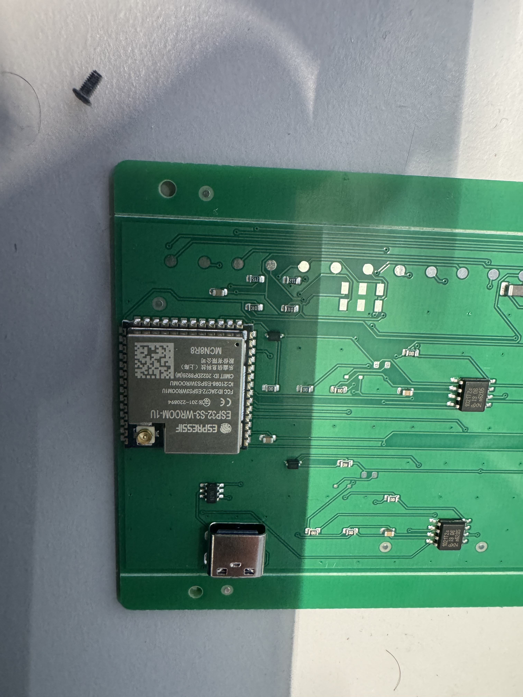
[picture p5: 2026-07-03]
photos/rev-a-first-article-2026-06-16/tesla-dual-lin-rev-a-board-arrival-03.jpg

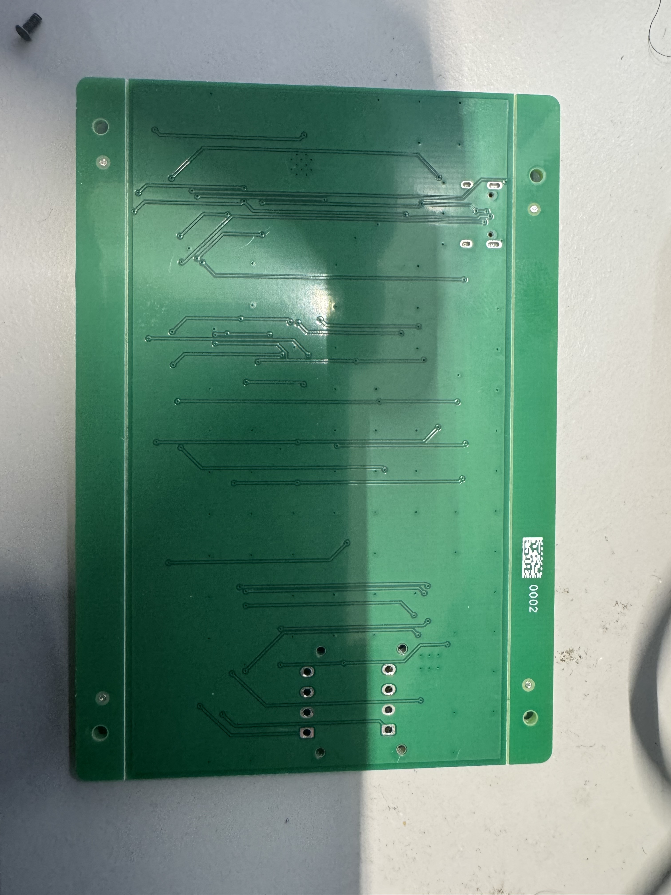
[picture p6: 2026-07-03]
photos/rev-a-first-article-2026-06-16/tesla-dual-lin-rev-a-board-arrival-02.jpg

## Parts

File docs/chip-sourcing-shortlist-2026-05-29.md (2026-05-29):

# Chip Sourcing Shortlist - 2026-05-29

Status: current order-oriented shortlist after the assumption audit and authoritative datasheet check. Earlier nRF5340-first and broad shortlist versions are archived under `docs/archive/2026-05-29-pre-assumption-audit/`.

## Direct Order Decision

For the first custom active-capable dual-LIN passthrough board, order around this core:

```text
ESP32-S3-WROOM-1U-N8R8
+ 2x TJA1021T/20
```

This is the cheapest reliable path that still satisfies the actual requirement: the wheel buttons continue working while the board is connected inline, and the board can actively substitute/proxy known frames when armed.

## Why This Replaced The nRF5340-First Plan

The original recommendation favored NORA-B106 / BL5340 because Nordic has a clean BLE/security story. The assumption audit challenged that and found that ESP32-S3 is the better Rev A default:

- Much cheaper module.
- Easier and faster firmware migration from the existing ESP32 proof work.
- Enough UARTs and timing headroom for two LIN channels.
- Secure Boot V2, flash encryption, eFuse key storage, encrypted config, anti-rollback, and debug lockdown are adequate for this threat model.
- Broad distributor availability and easy module assembly.

nRF5340 remains a valid backup if the product later needs a stronger formal security story or a Nordic-specific customer requirement.

## Primary Parts

| Function | Primary part | Why |
|---|---|---|
| BLE MCU module | `ESP32-S3-WROOM-1U-N8R8` | Cheap, stocked, 3 UARTs, BLE 5, secure boot/flash encryption, external antenna flexibility |
| LIN transceiver A | `TJA1021T/20` | 3.3 V/5 V MCU logic compatible, LIN 2.1/SAE J2602 class, familiar from current TJA1021 bench rig |
| LIN transceiver B | `TJA1021T/20` | Same part on both sides simplifies firmware, validation, and failure analysis |
| Antenna | 2.4 GHz U.FL antenna compatible with Espressif module guidance | Lets RF radiator move outside metal-heavy steering-wheel area |
| Firmware framework | ESP-IDF | Required path for secure boot, flash encryption, signed OTA/profile, anti-rollback, and production provisioning |

## Backup Parts

| Function | Backup part | Use if |
|---|---|---|
| BLE MCU module | `MDBT53-P1M` nRF5340 module | ESP32-S3 path is blocked by security/customer/regulatory requirement |
| BLE MCU alternate | Ezurio `BL5340` | Raytac module stock/mechanics are worse |
| LIN transceiver | `TPIC1021D` | TJA1021 stock/lifecycle risk is unacceptable |
| ESP32 module alternate | `ESP32-S3-WROOM-1-N8R8` | Board/antenna can sit in a plastic/open area and internal PCB antenna is proven reliable |

## Do Not Use As Final Core

| Part / board | Reason |
|---|---|
| Copperhill/SK Pang ESP32S3 CAN & LIN board | One LIN transceiver only; cannot do final car-side + wheel-side passthrough |
| MikroE LIN Click / one LIN breakout | Add-on board only; one LIN; no BLE core |
| XIAO ESP32-C3 | Existing proof rig only; too constrained for final dual-LIN + secure provisioning |
| ESP32-S3 dev board by itself | Useful bring-up board, not final harness fixture |
| `MCP2003-E/SN` | Cheap but 5 V-logic-centric; not the clean direct 3.3 V ESP32 interface we want |
| `TLIN1029A-Q1` / `TLIN2029A-Q1` | Attractive but demoted until exact 3.3 V logic path is verified or level shifting is intentionally added |
| Bare nRF5340 or bare ESP32-S3 chip | Avoid bare RF chip on Rev A; use certified module first |

## What To Buy Now

Order enough to cover one PCB spin plus bench mistakes:

| Qty | Item | Purpose |
|---:|---|---|
| 5-10 | `ESP32-S3-WROOM-1U-N8R8` | Primary Rev A MCU/BLE modules |
| 5-10 | 2.4 GHz U.FL antennas/pigtails | BLE antenna placement testing |
| 20 | `TJA1021T/20` | Two per board plus spares |
| 10 | `TPIC1021D` | Backup LIN transceiver validation |
| 1-2 | ESP32-S3-DevKitC-1 or equivalent WROOM-based dev board | ESP-IDF bring-up while PCB is designed |
| 2-4 | TJA1021 breakout boards | Immediate two-LIN passthrough bench wiring before PCB |
| assorted | 12V TVS, LIN ESD, USB ESD, PTC/fuse, reverse-protection MOSFET/controller, buck regulator samples | Protection/power schematic validation |
| assorted | keyed connector samples | Fit check for car-side/wheel-side harness split |

If ordering only one thing for the final board core, order `ESP32-S3-WROOM-1U-N8R8`. If ordering the actual dual-LIN core set, order that plus two `TJA1021T/20` per board.

## First PCB Seed BOM

| Block | Seed choice |
|---|---|
| MCU/BLE | ESP32-S3-WROOM-1U-N8R8 |
| LIN A | TJA1021T/20, SO-8 |
| LIN B | TJA1021T/20, SO-8 |
| Antenna | U.FL 2.4 GHz antenna, mechanically retained |
| Power | Automotive 12V to 3.3V buck, >500 mA headroom |
| Input protection | PTC/fuse, reverse-polarity MOSFET/controller, automotive TVS |
| LIN protection | LIN ESD/TVS diode on each LIN connector |
| USB | USB-C service connector with ESD and correct CC resistors |
| Controls | Mode switch, physical arm, service/rebind strap/pad |
| Indicators | Power, BLE, passive, armed, TX, fault LEDs |
| Connectors | Keyed positive-latch car-side and wheel-side harness connectors |
| Test points | VBAT, 3V3, LIN_A, LIN_B, RXD/TXD A/B, SLP/EN A/B, ARM, FAULT, GND |

## Open Before Layout Lock

- Confirm distributor stock for `ESP32-S3-WROOM-1U-N8R8`, `TJA1021T/20`, and `TPIC1021D` on the actual order day.
- Confirm whether `TJA1021T/20` lifecycle status is acceptable for prototype and short-run production.
- Choose exact automotive buck regulator and ESD/TVS parts.
- Choose connector family after measuring enclosure/harness space.
- Confirm U.FL antenna retention and antenna location so the pigtail cannot loosen in use.

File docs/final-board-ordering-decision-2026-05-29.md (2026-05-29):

# Final Board Ordering Decision - 2026-05-29

Status: current direct ordering answer for the first active-capable dual-LIN passthrough PCB.

## Order This Core

```text
ESP32-S3-WROOM-1U-N8R8
+ 2x NXP TJA1021T/20
+ 2.4 GHz U.FL antenna
```

This is the current final-board core. It is not the Copperhill board and not the nRF5340 DK. Those are useful references/dev tools, but they are not the orderable final passthrough board architecture.

## Why

The real requirement is not merely active LIN injection. The wheel buttons must continue to work while the device is installed. That means the device must sit inline and proxy the bus:

```text
car side <-> LIN A <-> MCU proxy/cache <-> LIN B <-> wheel side
```

That requires two LIN transceivers. A one-transceiver board cannot cleanly separate the car and wheel sides, so it cannot be the final active-use board.

## What Changed From The Previous Assumption

Earlier docs favored nRF5340 modules such as NORA-B106 or BL5340 because Nordic has a clean security story. After the assumption audit and datasheet check, the Rev A default changed:

| Question | Current answer |
|---|---|
| Is nRF5340 required? | No. ESP32-S3 is good enough and much cheaper for this threat model. |
| Does ESP32-S3 have enough UART/timing headroom? | Yes. Three UARTs and dual 240 MHz cores are more than enough for dual 19200 baud LIN plus BLE. |
| Is ESP32-S3 security enough? | Yes for casual cloning/readout resistance if Secure Boot V2, flash encryption, eFuse lockdown, signed updates, and anti-rollback are implemented correctly in ESP-IDF. |
| Does WiFi hurt the design? | Not materially if firmware never enables WiFi and secure boot prevents unauthorized firmware. |
| Is a certified module worth it? | Yes. Use a module for Rev A to avoid RF layout/certification risk. |
| Internal antenna or U.FL? | U.FL for Rev A because the steering-wheel area may be metal-heavy; external antenna placement reduces BLE risk. |
| Which LIN transceiver? | `TJA1021T/20` because it explicitly supports 3.3 V/5 V MCU logic and matches existing bench experience. |

## Immediate Buy List

For a practical Rev A order, buy:

| Qty | Part | Purpose |
|---:|---|---|
| 5-10 | `ESP32-S3-WROOM-1U-N8R8` | Rev A central BLE MCU module |
| 5-10 | 2.4 GHz U.FL antenna/pigtail | BLE antenna placement testing |
| 20 | `TJA1021T/20` | Two LIN transceivers per board plus spares |
| 10 | `TPIC1021D` | LIN transceiver backup path |
| 1-2 | ESP32-S3-DevKitC-1 or equivalent WROOM-based dev board | ESP-IDF bring-up while PCB is designed |
| 2-4 | TJA1021 breakout boards | Immediate dual-LIN bench passthrough wiring |

If you want the single most important item: `ESP32-S3-WROOM-1U-N8R8`.

If you want the smallest complete final-core order: `ESP32-S3-WROOM-1U-N8R8` plus two `TJA1021T/20` per board.

## Backup Decision

If the ESP32-S3 path is blocked, use an nRF5340 module:

```text
Raytac MDBT53-P1M
or Ezurio BL5340
```

Do this only if security/regulatory/customer requirements justify the higher cost and firmware rewrite.

## Rejected For Final Active Use

| Option | Rejection reason |
|---|---|
| Copperhill/SK Pang ESP32S3 CAN & LIN | One LIN only; cannot be inline passthrough by itself |
| Nordic nRF5340 DK | Excellent dev kit, not the final compact board |
| u-blox EVK-NORA-B1 | Dev kit only; still needs custom board |
| XIAO ESP32-C3 | Existing proof rig; too constrained for final dual-LIN/security path |
| MCP2003-E/SN | Cheap LIN part, but not the clean direct 3.3 V logic choice for ESP32-S3 |
| TLIN1029A-Q1 / TLIN2029A-Q1 | Good automotive parts, but demoted until exact 3.3 V logic/VIO path is intentionally designed |

## Final Practical Answer

The final active-use board is a custom PCB, and its core should be ordered now as:

```text
ESP32-S3-WROOM-1U-N8R8
2x TJA1021T/20 per board
```

That is the cheapest reliable path that still fully supports BLE control, dual-LIN passthrough, firmware protection, activation/binding, and active volume behavior without breaking the steering-wheel buttons.

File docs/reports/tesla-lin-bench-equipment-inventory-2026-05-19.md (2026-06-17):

# Tesla LIN Bench Equipment Inventory - 2026-05-19

Status: **BENCH BUILT AND VERIFIED 2026-05-26. See `C:\Users\ezabz\Code\xiao-lin-bench\README.md` for the final wiring diagram and `NEXT_STEPS.md` for what's next.** Parts arrived 2026-05-24; bench built and first clean LIN frame decoded the night of 2026-05-25/26. This file documents what was ordered and why — the active project is now `xiao-lin-bench`.

## Executive Summary

The ordered equipment is enough to build a real no-car LIN bench network and stop relying on the overheated tiny raw SOIC-8 TJA chip setup.

Important correction: the abandoned part is the loose/bare tiny TJA1020-style chip path. The current plan uses the APGDT001 as the real PC-side USB-LIN master/analyzer. A ready-made TJA1021-class breakout module is only for the XIAO-side LIN physical layer, and only after its pinout and RXD logic voltage are measured. Do not use a loose tiny SOIC TJA chip or the old overheated breadboard build.

The new lab direction is:

```text
Windows PC + Microchip APGDT001 USB-LIN analyzer/master
    -> 12-14 V LIN bench bus
    -> TJA1021 LIN transceiver module
    -> level-shifted Seeed XIAO ESP32-C3 UART
```

This lets us generate LIN master traffic, log responses, validate 19200 baud behavior, test PID `0x4C` / raw ID `0x0C`, verify enhanced checksum handling, and make the XIAO receive path reliable before touching a vehicle.

This does not prove in-car Tesla behavior by itself. Real vehicle wake/sleep timing, noise, grounding, and any active in-car injection still require careful later validation. If no physical Tesla steering-wheel module is on the bench, this setup can validate our electronics and fake/simulated LIN traffic, but it cannot prove a real Tesla module's payload behavior until the module or vehicle bus is connected.

## Ordered Equipment

### Mouser Order

| Item | Part / Listing | Qty | Purpose | Notes |
| --- | --- | ---: | --- | --- |
| Microchip LIN Serial Analyzer | Mouser `579-APGDT001`, manufacturer `APGDT001` | 1 | Real USB-LIN analyzer/master/snooper for PC-side bench work | User-confirmed Mouser listing showed 57 in stock, can ship immediately, unit price `$52.02`, interface type LIN/USB, operating supply 12 V to 14 V. |

APGDT001 is the main new capability. It lets the PC act as the LIN master on the bench, so we are no longer depending on a raw LIN chip plus hand-rolled timing just to create a bus.

### Amazon Cart

| Category | Item | Known ID / Detail | Expected Qty | Purpose | Storage Bucket |
| --- | --- | --- | ---: | --- | --- |
| LIN physical layer | Ready-made TJA1021 TTL UART to LIN breakout modules | ASIN `B0F31584W1` | 2 | XIAO-side LIN transceiver boards only; one primary, one spare. This is not the old bare tiny TJA chip path. | `Tesla LIN - transceivers` |
| Logic protection | DIYables 4-channel logic level shifter pack | ASIN `B0F9NCV286` | 1 pack | Protect XIAO 3.3 V GPIO if module RXD/TXD are 5 V logic | `Tesla LIN - XIAO interface` |
| Bench wiring | Terminal block distribution modules | Teansic 2x6 style, ASIN from prior cart context `B0DL51PXZX` | 1 kit | Clean bus/power breakout instead of loose breadboard wiring | `Tesla LIN - power and terminals` |
| Jumpers | ELEGOO Dupont jumper wires | ASIN `B01EV70C78` | Cart showed 2 packs | Temporary low-current logic connections | `Tesla LIN - jumpers` |
| Power wiring | BNTECHGO 22 AWG red/black silicone wire | ASIN `B07HGT44XY` | 1 | 12-14 V bench power, fused feeds, ground runs | `Tesla LIN - power and terminals` |
| Signal wiring | BNTECHGO 28 AWG silicone wire | Cart item from recovered list | 1 | Thin signal leads and tidy bench harnesses | `Tesla LIN - signal wire` |
| Protection | Mini inline fuse holder kit | MuHize mini fuse kit, ASIN `B08937HX12` | 1 kit | Fuse every 12-14 V bench feed before boards/modules | `Tesla LIN - power and terminals` |
| Reversible connections | WAGO 221 lever nuts | ASIN `B0CJ5QF3VX` | 1 kit | Reusable low-voltage bench joins without twisting/soldering | `Tesla LIN - power and terminals` |
| Vehicle-safe probing | Back-probe kit | 10-piece 0.7 mm back probe kit from cart | 1 | Probe connectors from the back without cutting harnesses | `Tesla LIN - vehicle probing` |
| Test leads | Multimeter/back-probe/piercing lead set | 6-piece lead kit from cart | 1 | Bench measurements and optional nonpreferred piercing leads | `Tesla LIN - vehicle probing` |

Piercing probes are last resort only. Use normal back-probing first. Do not pierce Tesla harness insulation unless there is no connector-safe option and the work has a reason worth the damage risk.

## Existing Equipment To Keep With This Kit

| Item | Current Role |
| --- | --- |
| Adjustable bench power supply | User already has this; use current limit for all first power-on work. |
| Seeed XIAO ESP32-C3 and current firmware/logging path | Embedded side of the test system. Known intended pins: RX on `D3/GPIO5`, TX on `D2/GPIO4`, active-path control later on `D4/GPIO6`. |
| Resistor assortment | Keep available for pull-ups, dividers, and quick safe measurement adapters. |
| FX2/sigrok logic analyzer setup | Secondary capture tool for checking waveform timing and validating APGDT001/XIAO observations. Do not connect raw 12-15 V LIN directly to FX2. |
| USB-C cables / PC tooling | Needed for XIAO serial logs and APGDT001 PC software. |

## Box Organization

Use one labeled project bin: `Tesla LIN Bench`.

Inside it, separate the small parts into these sub-bags or boxes:

| Label | Contents | Rule |
| --- | --- | --- |
| `01 USB-LIN Tool` | APGDT001, USB cable, any Mouser packing slip/manual | This is the master/analyzer. Keep it with documentation. |
| `02 LIN Transceivers` | TJA1021 modules, spare headers, module notes | These replace the raw 8-pin chip path. |
| `03 XIAO Interface` | XIAO boards, level shifters, resistors, short Dupont leads | Nothing in this bag should touch raw vehicle LIN directly. |
| `04 Power Protection` | Fuse holders, fuses, WAGO connectors, terminal blocks, 22 AWG wire | Every 12-14 V feed gets current limit and fuse. |
| `05 Signal Harness` | 28 AWG wire, jumper wires, small labels | Use for short bench harnesses only. |
| `06 Vehicle Probing` | Back probes, multimeter leads, piercing leads | Back probes first; piercing only with explicit reason. |

## Bench Wiring Plan

### PC Master To Bench LIN Bus

Follow the APGDT001 silkscreen/manual for exact terminals. Do not wire by assumed color or pin order.

Expected functional connections:

```text
Bench supply positive, current limited, fused
    -> APGDT001 LIN supply / VBAT if required by tool
    -> TJA1021 module VBAT

Bench supply ground
    -> APGDT001 ground/reference
    -> TJA1021 module ground
    -> XIAO ground

APGDT001 LIN
    -> shared bench LIN bus
    -> TJA1021 module LIN pin
```

Start at 12 V with a low current limit. Raise toward 13.8-14 V only after the bus behaves normally.

### TJA1021 Module To XIAO

The Amazon TJA1021 module is not trusted until measured.

```text
TJA1021 module RXD
    -> measure idle voltage first
    -> level shifter or divider if above 3.3 V
    -> XIAO D3/GPIO5

XIAO D2/GPIO4
    -> level shifter if needed
    -> TJA1021 module TXD

TJA1021 module GND
    -> XIAO GND
```

First XIAO test should be receive-only. Leave XIAO TX inactive until APGDT001-to-XIAO receive logging is reliable.

## What This Equipment Lets Us Test Without A Car

- APGDT001 master-mode LIN frame generation at `19200` baud.
- PID `0x4C` / raw ID `0x0C` polling and logging workflows.
- Enhanced checksum generation and rejection of bad checksums.
- Repeatable schedule timing from the PC-side tool.
- XIAO UART receive reliability through a real LIN transceiver instead of the marginal divider path.
- Safe 12-14 V wiring, fused power distribution, and common-ground discipline.
- Bench-only firmware parsing of 8-byte payloads plus checksum.
- Secondary verification with FX2/sigrok or a scope if the bus looks odd.

## What Still Needs Real Hardware Later

- A physical Tesla steering-wheel module or a live vehicle connection to observe true Tesla responses.
- Confirmation of real wake/sleep behavior and module current draw.
- Confirmation that Tesla's actual master schedule matches our bench schedule assumptions.
- Any in-car active behavior testing. Current evidence supports research and bench work, not customer-car injection approval.

## First Arrival Checklist

1. Photograph the APGDT001, TJA1021 modules, level shifters, and terminal blocks before wiring.
2. Save any Mouser/Microchip paperwork with the project bin.
3. Install Microchip's APGDT001 software on the Windows bench PC.
4. Put the bench supply at 12 V with current limit enabled before connecting modules.
5. Fuse the 12 V feed before it reaches terminal blocks or modules.
6. Power one TJA1021 module alone and measure logic-side RXD idle voltage.
7. If RXD idles above 3.3 V, put the level shifter or resistor divider between RXD and XIAO `D3/GPIO5`.
8. Connect APGDT001 to the bench LIN bus and send a known frame at `19200` baud.
9. Confirm the XIAO logs stable frame activity from the transceiver RXD path.
10. Only after receive is stable, test XIAO transmit on the isolated bench bus.

## Safety Boundaries

- Do not reuse the raw overheated tiny SOIC-8 TJA LIN chip breadboard as the primary path.
- Do not wire a loose/bare tiny TJA chip by guessed pinout. Use only the APGDT001 and measured ready-made breakout modules.
- Do not connect raw 12-15 V LIN directly to XIAO GPIO or FX2 inputs.
- Do not connect XIAO `D2` transmit or `D4` active-path control to a vehicle until bench validation passes and the work is explicitly approved.
- Do not probe DAB/SRS connectors.
- Do not pierce vehicle harness insulation unless back-probing is impossible and the purpose is worth the damage risk.
- Treat APGDT001 and TJA1021 grounds as common with bench supply ground during bench tests.
- Keep every 12-14 V feed fused and current limited during first power-up.

## Known LIN Target Context

Current Tesla Model X steering-wheel LIN assumptions from the existing project context:

| Field | Current Value |
| --- | --- |
| Vehicle side wire | White SW wire is LIN |
| Power | Green is about 15.4 V low-voltage power in vehicle context |
| Ground | Black is ground |
| Baud | `19200` |
| Strongest candidate raw ID | `0x0C` |
| Strongest candidate PID | `0x4C` |
| Frame shape | Break, sync `0x55`, PID, 8 data bytes, enhanced checksum |

## References

- `docs/reports/tesla-modelx-lin-desktop-ai-context-2026-05-18.md`
- `docs/research/responses/2026-05-19-usb-lin-analyzer-master-purchase-search-87122ae9.md`
- `docs/research/responses/2026-05-19-apgdt001-faster-shipping-search-7d48bd47.md`

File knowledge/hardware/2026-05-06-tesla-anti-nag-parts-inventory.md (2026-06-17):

# Tesla Anti-Nag DIY Module — Parts Inventory

**Documented:** 2026-05-06  
**Last updated:** 2026-05-10  
**Status:** Parts on hand; capture tooling mostly ready; frame ID still not captured

## Current Hold — 2026-05-10

- Source project docs live in `C:\Users\ezabz\Code\lpt-hub\hardware\tesla-anti-nag`.
- Older passive-sniffer firmware/docs live in `C:\Users\ezabz\Code\Schematics\firmware\anti-nag-v1`.
- Three saved Schematics captures (`2026-05-10_160553`, `_161000`, `_161248`) recorded `0` LIN frames and empty serial/CSV output.
- `sigrok-cli` is installed at `C:\Program Files\sigrok\sigrok-cli\sigrok-cli.exe`; the FX2 analyzer now scans as `fx2lafw:conn=1.40` after WinUSB/Zadig.
- The active TJA1020 bench-wiring path is paused because the old generic breadboard pinout conflicts with the board-measured `SH1020F2S` / TJA1020-family map in Schematics.
- Do not ask Moti to bring the Tesla until the passive divider, COM29 sniffer, and backprobe kit are preflighted.

---

## Parts Confirmed On Hand

| # | Part | Qty | ID / Marking | Notes |
| --- | --- | --- | --- | --- |
| 1 | **CD4066BE** | ~20 | "bridge gold" brand, DIP-14 | Bus isolation switch — critical component. Confirmed 14-pin DIP. Standard CD4066B pinout applies. |
| 2 | **TSL5 anti-nag module** | 1 | Customer board (Moti Zaks) | Reference unit for reverse engineering. DO NOT damage. Return to customer after SWD dump or LIN capture. |
| 3 | **LM2596 DC-DC buck module** | 1 | "LM2596S" or "JM503RP", labeled "DCDC" | Step-down voltage regulator module board. Useful for bench 12V → 3.3V supply for testing. Not in the final build BOM — likely ordered for bench power. |
| 4 | **Seeed Studio XIAO ESP32-C3** | 1 | "XIAO ESP32-C3" | **V1 prototype MCU.** Has built-in BLE + UART. 3.3V I/O, compatible with TJA1020T. Original V1 design used this chip. |
| 5 | **ST-Link V2** | 1 | "ST LINK V2 / STMA / STM32 / RST SWIM GND 3.3V 5.0V" | STM32/STM8 programmer. ⚠️ **NOT a WCH-LinkE** — cannot program or dump CH571F (WCH RISC-V). Useful only if project pivots to STM32. |
| 6 | **TJA1020 LIN transceiver (NXP)** | multiple | "1020/C" / "NXP" / "FUP148" / "ND342" — SOIC-8 | ✅ **Confirmed TJA1020 from NXP.** Exact match to the transceiver on the TSL5 board. "FUP148" = manufacturing code, "ND342" = lot/date code. This is the LIN bus interface chip for the V1 build. |
| 7 | **CP2102 USB-to-TTL module** | 1 | "ACP2102" or "CP2102" | USB ↔ UART serial bridge. Useful for ESP32-C3 firmware flashing and serial debug. |
| 8 | **HiLetGo 8-channel USB Logic Analyzer** | 1 | "Logic Analyzer 24MHz 8 channel / ARMFPGAM 100 SCM / CH0–CH7 + GND + VCC" | 24MHz, 8-channel, Cypress FX2LP-based. Works after WinUSB/Zadig; `sigrok-cli --scan` reports `fx2lafw:conn=1.40`. Use only on logic-level RXD/divider tap, not raw 12V LIN. |
| 9 | **WCH-LinkE programmer** | 1 | WCH-LinkE | ✅ **Arrived 2026-05-09.** Required for SWD dump of TSL5's CH571F (WCH RISC-V). Pads/readout flow not yet proven. |

---

## What We Have vs What Was Originally Planned

| Planned | Have It? | Notes |
| --- | --- | --- |
| CH571F (WCH RISC-V, QFN-28) — V2 MCU | ❌ No | Not on hand. V1 path (ESP32-C3) is available. |
| WCH-LinkE programmer | ✅ Yes | **Arrived 2026-05-09.** Can now attempt SWD dump of TSL5's CH571F. |
| TJA1020T LIN transceiver (SOIC-8) | ✅ Yes | Confirmed NXP TJA1020, SOIC-8, markings: "1020/C / NXP / FUP148 / ND342". |
| CD4066B bus isolation switch | ✅ Yes | 20 pcs on hand. |
| XIAO ESP32-C3 (V1 MCU) | ✅ Yes | V1 prototype path is viable. |
| Logic analyzer | ✅ Yes (bonus) | HiLetGo 8-ch. Enables LIN bus sniffing/verification. |
| CP2102 UART bridge | ✅ Yes | For firmware flashing. |

---

## Build Path Decision

**Given available hardware, the active path is:**

### Path A — SWD dump of CH571F from Moti's TSL5: HARDWARE ARRIVED, NOT PROVEN

- ✅ WCH-LinkE arrived 2026-05-09
- Next step: identify CH571F SWD/ISP pads and prove the WCH-LinkRV/MounRiver/OpenOCD flow without damaging the customer board

### Path B — CAN brute force on a real Tesla: NOT YET

- Need OBD-II CAN adapter (not on hand)
- Need access to Moti's Tesla (hasn't been arranged)

### Path C — LIN bus sniff: VIABLE, BUT NO FRAMES YET

- We have the 8-channel logic analyzer
- We have the ESP32-C3 which can act as a LIN master stimulus
- `sigrok-cli` is installed at `C:\Program Files\sigrok\sigrok-cli\sigrok-cli.exe`
- Analyzer enumerates as `fx2lafw:conn=1.40`
- Schematics passive sniffer branch exists with a 4x10k divider into XIAO `D3/GPIO5`
- Three saved 2026-05-10 dry captures recorded `0` frames; a real signal capture is still pending
- Do not connect raw 12V LIN directly to the USB analyzer or XIAO

### V1 Prototype Build: BLOCKED ON FRAME ID / PAYLOAD

- MCU: XIAO ESP32-C3 (on hand)
- Switch: CD4066BE (on hand)
- Transceiver: candidate TJA1020/TJA1020-family parts on hand; exact bench wiring pinout must be re-verified
- Firmware: Can write and flash once Frame ID is confirmed

---

## Immediate Next Steps

1. **Re-verify passive divider rig** — four 10k resistors in series, XIAO `D3/GPIO5` at the R3/R4 tap, shared ground, no direct 12V to logic input.
2. **Run local preflight** — confirm `COM29`, sniffer firmware if using Schematics branch, and `sigrok-cli --scan` showing `fx2lafw:conn=1.40`.
3. **Only then arrange passive vehicle capture** — backprobe only, no disconnecting connectors, capture idle plus deliberate scroll events.
4. **Keep TJA1020 active bench wiring paused** — reconcile generic breadboard pinout against the board-measured `SH1020F2S` / TJA1020-family map first.
5. **SWD remains optional** — WCH-LinkE is here, but pad ID and readout are not proven.

---

## Key Technical Constants (from research)

- **Baud rate:** 19200 (NOT 9600 — this was the original bug)
- **Checksum:** LIN 2.1 Enhanced (includes PID in sum)
- **Frame ID:** Unknown — to be extracted via LIN sniff (Path C) or CAN brute force (Path B)
- **Payload (inferred):** Idle=`00 00 00 00 00 00 00 00`, Up=`00 00 01 00 00 00 00 00`, Down=`00 00 FF 00 00 00 00 00`
- **Injection timing:** Switch CD4066B open during ~200µs inter-frame space, inject, close before next 10ms poll
- **CAN verification:** Monitor CAN ID 0x3C2 (`VCLEFT_switchStatus`), bits 16–21 = `swcLeftScrollTicks`
- **Platform scope:** Pre-Highland Model 3/Y (2021–2023) — different frame structure on Highland/Juniper/Yoke

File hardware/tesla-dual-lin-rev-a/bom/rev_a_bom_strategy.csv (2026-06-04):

item | refdes | qty | subsystem | rev_a_selected_mpn | low_cost_candidate | robust_upgrade_candidate | supplier_part_status | pcba_policy | estimated_100_unit_cost_usd | decision_status | why
MCU/BLE | U1 | 1 | mcu | ESP32-S3-WROOM-1U-N8R8 | ESP32-S3-WROOM-1U-N8R8 | ESP32-S3-WROOM-1U-N8R8 | LCSC C2980300 verified earlier | SMT by PCBA vendor | 3.83 | locked | External antenna module is the right balance of BLE performance manufacturing and firmware continuity
LIN transceiver | U2 U3 | 2 | lin | TJA1021T/20/C,118 | TJA1021T/20/C,118 | TPIC1021D as backup only | LCSC C271675 verified earlier | SMT by PCBA vendor | 0.96 | locked | Two physical LIN channels are mandatory for inline passthrough
Buck regulator | U4 | 1 | power | LM5164DDA 100V 1A synchronous buck | MP2459DT-LF-Z or MP1584EN class after cost-down validation | LM5164DDA-Q1 or equivalent AEC-Q high-voltage buck | TBD supplier and TI calculator verification | SMT by PCBA vendor | 1.60 | selected_verify_calculation | Robust first-article default footprint Package_SO:HSOP-8-1EP_3.9x4.9mm_P1.27mm_EP2.41x3.1mm_ThermalVias; preliminary 174k/100k FB for 1.2V reference, 10uH inductor, 10uF 50V input, 22uF output; RON/frequency and ripple network blocked on TI calculator/WEBENCH
Reverse polarity MOSFET | Q1 | 1 | power | AO4407A-class P-channel MOSFET | AO4407A-class P-channel MOSFET | AEC-Q101 P-channel MOSFET 40V+ | TBD supplier verification | SMT by PCBA vendor | 0.18 | preferred_low_cost | MOSFET ideal-diode style protection avoids voltage drop while staying inexpensive
Input PTC/fuse | F1 | 1 | power | 1812 PPTC 0.5-0.75A hold | MF-MSMF050 or MF-MSMF075 class | AEC-Q/known derating PPTC or external harness fuse | TBD supplier verification | SMT by PCBA vendor | 0.12 | preferred_low_cost | Protects harness from board faults without a replaceable fuse in Rev A
VBAT TVS | D1 | 1 | power | SMBJ24A/SMBJ26A class | SMBJ24A or SMBJ26A | SM8S33A/SM8S36A automotive load-dump TVS | TBD supplier verification | SMT by PCBA vendor | 0.12 | hybrid_review | Low cost is enough for bench; robust upgrade may be worth it before vehicle pilot
LIN ESD | D2 D3 | 2 | lin | PESD1LIN-class single-line LIN ESD | Generic 24V single-line TVS/ESD | PESD1LIN AEC-Q class | TBD supplier verification | SMT by PCBA vendor | 0.16 | selected_verify_supplier | LIN pins use 10R series resistors plus dedicated ESD near each harness entry if stock/cost permits
USB ESD | D4 | 1 | usb | USBLC6-2SC6 | USBLC6-2SC6 / C7519 | RClamp4021ZA or equivalent premium USB array | JLC C7519 selected after post-order package correction | SMT by PCBA vendor | 0.10 | selected_first_article | MASS ORDER CHECK: keep USBLC6-2SC6 / C7519 or another verified SOT-23-6L USB ESD; do not mass order with any USON-10 auto-match
USB-C connector | J1 | 1 | usb | TYPE-C-31-M-12 class USB2 receptacle | TYPE-C-31-M-12 class | Reinforced mid-mount USB-C with same pinout | TBD supplier verification | SMT by PCBA vendor if in library | 0.22 | preferred_low_cost | Common USB2 Type-C keeps service path cheap and easy to assemble
Physical arm switch | SW1 | 1 | safety | DPDT slide switch | CK JS202011JCQN class or similar DPDT SMD slide switch | better-rated metal-frame DPDT slide switch | TBD supplier verification | Manual or PCBA if library supports | 0.35 | selected_verify_supplier | One pole gates LIN_EN; second pole drives ARM_SENSE high only when armed; verify footprint actuator direction and contact mapping
Mode switch | SW2 | 1 | ui | SPDT/SPST slide switch optional | SS-12D07 class | better-rated metal-frame switch | TBD supplier verification | Manual or PCBA if library supports | 0.18 | candidate | Mode switch is firmware input only and may move after fit testing
Harness Micro-Fit service connectors | J2 J3 | 2 | mechanical | Molex Micro-Fit 3.0 43650-0415 4-circuit vertical header | Molex Micro-Fit 3.0 43650-0415 | Tesla X178/X184 adapter pigtails after physical connector inspection | DigiKey/Mouser/common distributor; JLCPCB secondary operation if unavailable | THT by vendor or installed secondary operation | 1.40 | selected_first_article | Board ships with keyed/latching 4-cavity service connectors matching Tesla-documented VBAT/GND/NC/LIN cavity count; board-side cable mate Molex 43025-0400 plus 43030-series terminals
Input ferrite/filter | FB1 | 1 | power | 1206 ferrite 600R@100MHz 2A class | Generic 1206 ferrite | Automotive-rated ferrite or small LC filter | TBD supplier verification | SMT by PCBA vendor | 0.04 | preferred_low_cost | Cuts conducted noise before buck without much cost
Buck inductor | L1 | 1 | power | SRU5016-100Y | SRU5016-100Y / C5760316 | Higher-saturation shielded inductor after footprint revision | JLC C5760316 selected after post-order package correction | SMT by PCBA vendor | 0.61 | selected_first_article | MASS ORDER BLOCKER: first article L1 SRU5016-100Y / C5760316 is package-correct but lower margin; do not mass order until bench current and thermal margin are proven or a higher-current production inductor/footprint is selected
CC resistors | R_CC1 R_CC2 | 2 | usb | 5.1k 1% 0603 | Generic/JLC basic 0603 | Same | Generic basic | SMT by PCBA vendor | 0.01 | locked | Required USB-C device Rd resistors
Boot/reset pullups | R_EN1 R_BOOT1 | 2 | mcu | 10k 1% 0603 | Generic/JLC basic 0603 | Same | Generic basic | SMT by PCBA vendor | 0.01 | locked | ESP32 boot/reset support
LIN_EN pulldown | R_LINEN_PD1 | 1 | safety | 100k 1% 0603 | Generic/JLC basic 0603 | Same | Generic basic | SMT by PCBA vendor | 0.01 | locked | Post-switch SLP_N net must default low
ARM_SENSE pulldown | R_ARMSENSE_PD1 | 1 | safety | 100k 1% 0603 | Generic/JLC basic 0603 | Same | Generic basic | SMT by PCBA vendor | 0.01 | locked | Default-off for physical arm sense during switch travel or missing switch
LIN TXD pullups | R_LINA_TXD_PU1 R_LINB_TXD_PU1 | 2 | safety | 100k 1% 0603 to 3V3 | Generic/JLC basic 0603 | Same | Generic basic | SMT by PCBA vendor | 0.02 | locked | Keeps both TJA1021 TXD inputs recessive if MCU pins float during reset/boot/fault
Optional LIN master pullups | R_LINA_MASTER1 R_LINB_MASTER1 D_LINA_MASTER1 D_LINB_MASTER1 | 4 | lin | DNP 1k 0603 plus SOD-323 diode per channel | Generic/JLC basic resistor plus small switching diode | Populate only on channel where board is the LIN commander/master | Generic basic/stocked diode | SMT by PCBA vendor or hand-populate | 0.04 | dnp_topology_option | Leave car-side DNP when existing vehicle master remains; populate downstream side only if firmware intentionally creates an isolated commanded LIN segment
WAKE pullups | R_WAKE_A1 R_WAKE_B1 | 2 | lin | 100k 1% 0603 to VBAT_PROTECTED | Generic/JLC basic 0603 | Same | Generic basic | SMT by PCBA vendor | 0.02 | selected_verify_datasheet | Keeps active-low WAKE_N inactive; expose optional test access only
LIN series resistors | R_LINA_SER1 R_LINB_SER1 | 2 | lin | 10R 1% 0603 | Generic/JLC basic 0603 | Same | Generic basic | SMT by PCBA vendor | 0.02 | selected | Placed between harness-side LIN net and TJA1021 LIN pin
Buck feedback resistors | R_FB_TOP1 R_FB_BOT1 | 2 | power | 174k/100k 1% 0603 | Generic/JLC basic 0603 | Same | Generic basic | SMT by PCBA vendor | 0.02 | selected_verify_calculation | Preliminary for LM5164 1.2V reference; final after TI calculator review
VBAT bulk capacitor | C_BULK_IN | 1 | power | 47uF 35-50V | 47uF 35V electrolytic/polymer | 100uF 50V automotive-rated polymer | TBD supplier verification | SMT/THT by vendor or manual | 0.35 | preferred_low_cost | Input energy storage and transient smoothing
3V3 bulk capacitor | C_3V3_BULK | 1 | power | 22uF 10V X7R 0805/1206 | 22uF 10V X7R | 47uF combined low-ESR ceramics | TBD supplier verification | SMT by PCBA vendor | 0.10 | preferred_low_cost | ESP32 radio bursts need local bulk capacitance
Local decoupling | C_DECOUPLE | 8 | power | 100nF 50V X7R 0603 | Generic/JLC basic 0603 | Same | Generic basic | SMT by PCBA vendor | 0.03 | locked | Local decoupling at ICs and protection blocks
Placed local decoupling | C_U1_DEC1 C_U2_DEC1 C_U3_DEC1 C_U4_DEC1 | 4 | power | 100nF 50V X7R 0603 | Generic/JLC basic 0603 | Same | Generic basic | SMT by PCBA vendor | 0.02 | locked | Implemented on Rev A at ESP32 LIN transceiver VBAT pins and buck input
Status LEDs | LED_STATUS LED_FAULT | 2 | ui | 0603 LED optional | Generic 0603 LEDs | Same | TBD supplier verification | SMT by PCBA vendor | 0.04 | candidate | Useful for Rev A debug but can be depopulated later
Pogo pads | TP_ARRAY | 12 | test | ENIG copper pads | KiCad test pads | Same | PCB feature not purchased | PCB copper | 0.00 | locked | No hand wires for programming/test
Fiducials | FID1 FID2 FID3 | 3 | manufacturing | Global fiducials | KiCad fiducial footprints | Same | PCB feature not purchased | PCB copper | 0.00 | locked | Required for repeatable PCBA assembly
External antenna | ANT1 | 1 | rf | 2.4GHz U.FL antenna | TBD low-cost U.FL antenna | automotive-rated external 2.4GHz antenna | TBD after mechanical fit | Manual install | 1.00 | candidate | RF placement inside wheel cavity must be validated physically

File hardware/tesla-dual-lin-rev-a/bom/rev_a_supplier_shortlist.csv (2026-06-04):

item | refdes | default_choice | example_mpn_or_class | footprint_target | cost_path | status | verification_needed
MCU/BLE | U1 | locked | ESP32-S3-WROOM-1U-N8R8 | RF_Module:ESP32-S3-WROOM-1U | core | locked | Verify KiCad land pattern and paste mask against Espressif datasheet before fab
LIN transceiver | U2 U3 | locked | TJA1021T/20/C,118 | Package_SO:SOIC-8_3.9x4.9mm_P1.27mm | core | locked | Verify final symbol pin numbers against NXP datasheet during schematic review
Buck regulator | U4 | default_robust_first_article | LM5164DDA or LM5164DDAR 100V 1A synchronous buck | Package_SO:HSOP-8-1EP_3.9x4.9mm_P1.27mm_EP2.41x3.1mm_ThermalVias | robust | selected_verify_calculation | Verify TI calculator values and vendor availability before quote
Buck regulator cost-down alternate | U4_ALT | alternate | MP2459DT-LF-Z or compatible 36V 1A buck | Package_TO_SOT_SMD:SOT-23-6 | low_cost | blocked_pending_datasheet | Use only after exact datasheet pinout feedback reference and transient bench margin are verified
Buck inductor | L1 | first_article | SRU5016-100Y / C5760316 10uH 1A 900mA | Inductor_SMD:L_Bourns_SRU5016_5.2x5.2mm | low_cost | selected_first_article | MASS ORDER BLOCKER: package-correct for Rev A JLC build but lower margin; current-limit bench bring-up and prove current/thermal margin or select higher-current production inductor before mass ordering
Reverse polarity PFET | Q1 | default | AO4407A-class P-channel MOSFET | Package_SO:SOIC-8_3.9x4.9mm_P1.27mm | low_cost | selected_verify_supplier | Verify Vds Rds(on) gate rating and source/drain orientation
Input PPTC | F1 | default | 1812 PPTC 0.5A-0.75A hold | Fuse:Fuse_1812_4532Metric | low_cost | selected_verify_supplier | Check voltage rating and hot-environment derating
VBAT TVS | D1 | hybrid_default | SMBJ24A or SMBJ26A | Diode_SMD:D_SMB | low_cost | selected_verify_supplier | Check clamp against selected buck absolute maximum
VBAT TVS robust alternate | D1_ALT | alternate | SM8S33A or SM8S36A | Diode_SMD:D_SMC or vendor footprint | robust | alternate | Use for vehicle pilot if package fits and supplier can assemble
LIN ESD | D2 D3 | default_robust | PESD1LIN/PESD1CAN-class single-line ESD | Diode_SMD:D_SOD-323 or Package_TO_SOT_SMD:SOT-23 | robust | selected_verify_supplier | Verify working voltage leakage capacitance and AEC-Q if available
USB ESD | D4 | first_article | USBLC6-2SC6 / C7519 | Package_TO_SOT_SMD:SOT-23-6 | low_cost | selected_first_article | MASS ORDER CHECK: package-correct SOT-23-6L JLC replacement; do not use USON-10 auto-match parts in any larger build
USB-C connector | J1 | default | TYPE-C-31-M-12 class | Connector_USB:USB_C_Receptacle_HRO_TYPE-C-31-M-12 | low_cost | selected_verify_supplier | Verify exact connector drawing matches KiCad footprint
Physical arm switch | SW1 | default | CK JS202011JCQN-class DPDT slide switch | Button_Switch_SMD:SW_DPDT_CK_JS202011JCQN | low_cost | selected_verify_supplier | Verify DPDT contact map actuator direction and whether PCBA vendor will place it
Mode switch | SW2 | optional | SS-12D07-class SPDT/SPST slide switch | Button_Switch_SMD:SW_SPDT_PCM12 | low_cost | candidate | May depopulate if firmware config replaces physical mode
CC resistors | R_CC1 R_CC2 | default | 5.1k 1% 0603 | Resistor_SMD:R_0603_1608Metric | basic | locked | Choose JLC basic passive line
EN/BOOT resistors | R_EN1 R_BOOT1 | default | 10k 1% 0603 | Resistor_SMD:R_0603_1608Metric | basic | locked | Choose JLC basic passive line
LIN_EN pulldown | R_LINEN_PD1 | default | 100k 1% 0603 | Resistor_SMD:R_0603_1608Metric | basic | locked | Choose JLC basic passive line
LIN TXD pullups | R_LINA_TXD_PU1 R_LINB_TXD_PU1 | default | 100k 1% 0603 | Resistor_SMD:R_0603_1608Metric | basic | locked | Choose JLC basic passive line; safety default recessive TXD for active-operation board
Optional LIN master termination | R_LINA_MASTER1 R_LINB_MASTER1 D_LINA_MASTER1 D_LINB_MASTER1 | dnp | 1k 0603 plus SOD-323 switching diode | Resistor_SMD:R_0603_1608Metric + Diode_SMD:D_SOD-323 | basic | dnp_topology_option | Populate only on the segment where this board is intentionally the LIN master/commander; leave DNP on existing vehicle-master side
WAKE pullups | R_WAKE_A1 R_WAKE_B1 | default | 100k 1% 0603 to VBAT_PROTECTED | Resistor_SMD:R_0603_1608Metric | basic | selected | Verify TJA1021 WAKE_N unused recommendation in final datasheet review
LIN series resistors | R_LINA_SER1 R_LINB_SER1 | default | 10R 1% 0603 | Resistor_SMD:R_0603_1608Metric | basic | selected | Place as DFM/SI review determines
Feedback resistors | R_FB_TOP1 R_FB_BOT1 | default | 174k/100k 1% 0603 for LM5164 1.2V FB | Resistor_SMD:R_0603_1608Metric | basic | selected_verify_calculation | Only final after TI calculator review
Input ferrite | FB1 | default | 1206 600R@100MHz 2A ferrite | Ferrite_SMD:L_1206_3216Metric | low_cost | selected_verify_supplier | Check DCR and current rating
Input bulk capacitor | C_BULK_IN | default | 47uF 35V-50V | CAP_VENDOR_SPECIFIC | low_cost | selected_verify_supplier | Prefer X7R/polymer with voltage derating margin
3V3 bulk capacitor | C_3V3_BULK | default | 22uF 10V X7R 0805/1206 | Capacitor_SMD:C_0805_2012Metric | low_cost | selected_verify_supplier | Check DC bias derating
Small decoupling | C_DECOUPLE | default | 100nF 50V X7R 0603 | Capacitor_SMD:C_0603_1608Metric | basic | locked | Use near each IC supply
Placed local decoupling | C_U1_DEC1 C_U2_DEC1 C_U3_DEC1 C_U4_DEC1 | default | 100nF 50V X7R 0603 | Capacitor_SMD:C_0603_1608Metric | basic | locked | Implemented on Rev A; keep as JLC basic passive
Pogo pads | TP_ARRAY | default | 1.5mm ENIG exposed pads | TestPoint:TestPoint_Pad_D1.5mm | pcb_feature | locked | Confirm fixture pitch and bottom keepout
Fiducials | FID1 FID2 FID3 | default | 1mm copper 2mm mask opening | Fiducial:Fiducial_1mm_Mask2mm | pcb_feature | locked | Required for PCBA
Harness Micro-Fit service connectors | J2 J3 | default | Molex Micro-Fit 3.0 43650-0415 board headers plus 43025-0400 cable housings | Connector_Molex:Molex_Micro-Fit_3.0_43650-0415_1x04_P3.00mm_Vertical | serviceable | selected_first_article | Populate both car-side and wheel-side keyed/latching 4-circuit board connectors; use adapter pigtails to the final Tesla X178/X184 mates after physical inspection
External antenna | ANT1 | default | 2.4GHz U.FL whip/PCB antenna | manual_accessory | rf | candidate | Validate RF placement in wheel cavity

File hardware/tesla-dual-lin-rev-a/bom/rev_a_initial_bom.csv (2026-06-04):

refdes | qty | function | mpn | manufacturer | package_or_footprint | primary_supplier | primary_supplier_part | assembly_policy | status | notes
U1 | 1 | MCU/BLE module | ESP32-S3-WROOM-1U-N8R8 | Espressif | SMD module 19.2x18mm | LCSC | C2980300 | SMT by PCBA vendor | primary | External U.FL antenna variant; verify Espressif land pattern and MSL handling
U2 U3 | 2 | LIN transceiver | TJA1021T/20/C,118 | NXP | SO-8 | LCSC | C271675 | SMT by PCBA vendor | primary | Two required for inline passthrough; direct 3.3V MCU logic compatible
U4 | 1 | Automotive buck regulator | LM5164DDA 100V 1A synchronous buck | Texas Instruments | 8-pin SOIC PowerPAD / DDA | DigiKey/Mouser/TI/LCSC | TBD | SMT by PCBA vendor | selected_verify_calculation | Robust first-article default; preliminary 174k/100k FB, 10uH inductor, 10uF 50V input, 22uF output, 100nF bootstrap; RON/frequency and ripple network require TI calculator before production
Q1 | 1 | Reverse polarity ideal diode MOSFET | AO4407A-class P-channel MOSFET | TBD | SO-8 | LCSC/JLCPCB | TBD | SMT by PCBA vendor | selected_verify_supplier | Select by low Rds(on) Vds gate rating and source/drain orientation
F1 | 1 | Input overcurrent protection | 1812 resettable PPTC 0.5-0.75A hold | Littelfuse/Bourns or compatible | 1812 | LCSC/JLCPCB | TBD | SMT by PCBA vendor | selected_verify_supplier | Confirm voltage rating and hot-environment derating against measured board load
D1 | 1 | VBAT TVS | SMBJ24A/SMBJ26A class | Littelfuse/ST/Diodes | SMB | LCSC/JLCPCB | TBD | SMT by PCBA vendor | selected_verify_supplier | Low-cost default; robust SM8S option remains for vehicle pilot if needed
D2 D3 | 2 | LIN ESD/TVS | PESD1LIN/PESD1CAN-class single-line ESD | Nexperia/ST/Diodes | SOD-323 or SOT-23 | LCSC/JLCPCB | TBD | SMT by PCBA vendor | selected_verify_supplier | Place near car and wheel connectors with 10R series resistors
D4 | 1 | USB data ESD | USBLC6-2SC6 | STMicroelectronics | SOT-23-6L | LCSC/JLCPCB | C7519 | SMT by PCBA vendor | selected_first_article | Low-capacitance USB2 D+/D- protection near connector; corrected from package-wrong USON-10 JLC match after paid-order review
J1 | 1 | USB-C service connector | TYPE-C-31-M-12 class | TBD | USB-C 16-pin SMT | LCSC/JLCPCB | TBD | SMT if available | selected_verify_supplier | Device-only; CC1/CC2 each need 5.1k pulldown and VBUS must not backfeed VBAT
J2 | 1 | Car-side harness service connector | Molex Micro-Fit 3.0 43650-0415 4-circuit vertical header | Molex | Connector_Molex:Molex_Micro-Fit_3.0_43650-0415_1x04_P3.00mm_Vertical | DigiKey/Mouser/JLCPCB-local | TBD | THT by vendor or installed secondary operation | selected_first_article | Populated keyed/latching board connector; pinout 1 VBAT_IN 2 GND 3 NC 4 LIN_A; board-side cable mate Molex 43025-0400 plus 43030-series terminals
J3 | 1 | Wheel-side harness service connector | Molex Micro-Fit 3.0 43650-0415 4-circuit vertical header | Molex | Connector_Molex:Molex_Micro-Fit_3.0_43650-0415_1x04_P3.00mm_Vertical | DigiKey/Mouser/JLCPCB-local | TBD | THT by vendor or installed secondary operation | selected_first_article | Populated keyed/latching board connector; pinout 1 VBAT_PROTECTED 2 GND 3 NC 4 LIN_B; board-side cable mate Molex 43025-0400 plus 43030-series terminals
SW1 | 1 | Physical arm switch | CK JS202011JCQN-class DPDT slide switch | C&K or compatible | SMD/THT vendor-specific | LCSC/JLCPCB | TBD | manual or SMT/THT by vendor | selected_verify_supplier | One pole gates LIN_EN; second pole drives ARM_SENSE high only when armed
SW2 | 1 | Mode switch | TBD slide switch | C&K or equivalent | SMD/THT TBD | DigiKey/Mouser | TBD | manual or SMT/THT by vendor | candidate | Firmware input only; not sole safety gate
TP1-TP20 | 20 | Pogo/test pads | KiCad test pad | Custom | 1.5mm exposed pad | N/A | N/A | PCB copper | primary | GND 3V3 VBAT USB+ USB- UART_TX UART_RX EN BOOT LIN_A LIN_B LIN_A_TJA LIN_B_TJA LIN_EN LIN_EN_DRIVE ARM_SENSE WAKE_A_N WAKE_B_N INH_A_TP INH_B_TP
R_CC1 R_CC2 | 2 | USB-C CC pulldown | 5.1k 1% | Any | 0603 | LCSC/JLCPCB | TBD | SMT by PCBA vendor | primary | One from each CC pin to GND
R_EN1 R_BOOT1 | 2 | ESP boot/reset pullups | 10k 1% | Any | 0603 | LCSC/JLCPCB | TBD | SMT by PCBA vendor | primary | EN and GPIO0 pullups
R_LINEN_PD1 | 1 | LIN_EN default pulldown | 100k 1% | Any | 0603 | LCSC/JLCPCB | TBD | SMT by PCBA vendor | primary | Keeps both SLP_N lines low unless armed and firmware-enabled
R_ARMSENSE_PD1 | 1 | ARM_SENSE default pulldown | 100k 1% | Any | 0603 | LCSC/JLCPCB | TBD | SMT by PCBA vendor | primary | Keeps physical arm sense low during switch travel or missing-switch faults
R_WAKE_A1 R_WAKE_B1 | 2 | TJA1021 WAKE_N pullups | 100k 1% | Any | 0603 | LCSC/JLCPCB | TBD | SMT by PCBA vendor | selected_verify_datasheet | Pull active-low local wake pins high to VBAT_PROTECTED when unused
R_LINA_TXD_PU1 R_LINB_TXD_PU1 | 2 | TJA1021 TXD recessive defaults | 100k 1% | Any | 0603 | LCSC/JLCPCB | TBD | SMT by PCBA vendor | primary | External pullups keep each LIN TXD recessive if MCU pins float during reset/boot/fault
R_LINA_MASTER1 R_LINB_MASTER1 D_LINA_MASTER1 D_LINB_MASTER1 | 4 | Optional LIN master termination | DNP 1k plus SOD-323 diode | Any | 0603/SOD-323 | LCSC/JLCPCB | TBD | DNP unless topology requires | dnp_topology_option | Populate only on the segment where this board intentionally acts as LIN master/commander
R_LINA_SER1 R_LINB_SER1 | 2 | LIN series resistors | 10R 1% | Any | 0603 | LCSC/JLCPCB | TBD | SMT by PCBA vendor | selected | Between harness-side LIN net and TJA1021 LIN pin
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

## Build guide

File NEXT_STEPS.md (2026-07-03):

# Current Next Steps - Rev A Model 3 Active Anti-Nag

Updated: 2026-06-17 18:00 (post-bench-verification session)

## ✅ Completed: Bench Verification Gate (2026-06-17)

Firmware v5.5-rev-a-ble flashed and fully verified on the Rev A ESP32-S3 board:

- Serial console: COM6, 115200 baud, responding reliably
- Full boot sequence confirmed: PSRAM enabled, banner printed, NimBLE started, BLE advertising
- All 13 commands tested and passing: version, config, cache, safe:arm, safe:off, bridge:on, bridge:off, nag:on, nag:off, nag:status, nag:once, vol:click, inject:clear, reset
- Cache auto-seeded on boot with 6 Model 3 frame IDs (0x28-0x2D)
- nag:once correctly blocked when not armed (antiNagSingleCycle safety gate)
- BLE init + advertising confirmed via serial console (NimBLE extended advertising — external BLE scanner limitation, not a firmware bug)
- Board left in safe state: armed=no, nag=off, pending=0, bridge=yes

Session worksheet: `logs/sessions/20260617_154311-rev-a-active-tesla-model-3-live-prep-20260617/measurements.md`

## Resume Here — Next Gate: Unpowered Board Measurements

**Tools needed:** Multimeter (continuity + DC voltage)

1. **Power OFF** — disconnect CP2102 USB, no VBAT connected.
2. Measure continuity/resistance between TP1 (GND) and TP2 (3V3) — confirm not shorted.
3. Measure F1 (fuse) continuity — left pad to right pad, should be ~0Ω.
4. Measure TP10 (LIN_A) to TP1 (GND) — confirm not shorted.
5. Measure TP11 (LIN_B) to TP1 (GND) — confirm not shorted.
6. Measure TP10 (LIN_A) to TP11 (LIN_B) — confirm not shorted together.
7. Measure TP6 (UART0_TX) to TP7 (UART0_RX) — confirm not shorted.
8. Measure TP8 (EN) to TP1 (GND) — should be high impedance.
9. Measure TP9 (BOOT) to TP1 (GND) — should be high impedance.
10. Record all readings in the session worksheet.

## After Unpowered Gate → Bench Power Measurements

1. Connect CP2102 (3V3 + GND to TP2/TP1).
2. Measure TP2 (3V3) to TP1 (GND) — should be ~3.3V.
3. If VBAT connected: measure F1 right (VBAT_PROTECTED) to TP1.
4. Measure current draw at idle (if meter supports inline current).
5. Confirm serial console still responds on COM6 (`version`, `config`).
6. Test physical arm behavior: tie GPIO9 high, verify `safe:arm` works. Tie low, verify blocked.
7. Leave board in safe state after measurements.

## After Bench Power Gate → Car Harness Measurements

1. At the vehicle, before connecting the board:
   - Measure vehicle 12V to vehicle ground.
   - Measure car-side LIN idle voltage.
   - Measure wheel-side LIN idle voltage.
   - Verify native wheel controls work normally.
2. Photo of car/wheel connector orientation for reference.

## Live Model 3 Test Order (after all gates pass)

1. Connect only after the bench checklist is complete.
2. Start with `safe:off` and `bridge:off`.
3. Observe `config` / `stats` while connected, with no active injection.
4. Enable bridge only after native wheel behavior is understood.
5. Queue single manual events first: `vol:up:1`, `vol:down:1`, `vol:click:1`.
6. Test `nag:once` before `nag:on`.
7. If the vehicle reacts incorrectly, immediately run `safe:off` and disconnect.

## Keep Later

- Rev B mechanical/layout correction remains blocked by `docs/rev-b-quality-gate-2026-06-16.md`.
- Model X support remains historical/reference until Rev A Model 3 passthrough is proven.
- Right-wheel `0x2B` injection remains not ready; Rev A active injection currently targets left-wheel `0x2A` only.
- BLE external scanner limitation with NimBLE extended advertising — investigate if needed for production, not blocking for bench/car testing.

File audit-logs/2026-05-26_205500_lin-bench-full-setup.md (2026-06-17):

# LIN Bench Full Setup - 2026-05-26 20:55

## Summary

Complete end-to-end LIN bench buildout on the desktop node (ZABZ-TECH). The project evolved from the original TSL5 board + lpt-schematics firmware to a fully working LIN bench with APGDT001 analyzer and TJA1021 transceiver.

## What Was Done

### Phase 1: Firmware v4 Upgrade
- Upgraded `src/main.cpp` from v3 to v4:
  - Runtime vehicle ID (`vehicle:tesla-model-3`)
  - Runtime baud switch (`baud:19200`)
  - 128-frame ring buffer with `ring` dump command
  - Raw byte toggle (`raw:1`/`raw:0`)
  - Serial command handler (`vehicle:`, `baud:`, `raw:`, `ring`, `stats`)
  - Telemetry queue expanded from 16→64 frames
  - Auto-baud candidates (19200/9600/10400)

### Phase 2: Tools & Dashboard
- **`tools/car-day-launcher.ps1`** — Unified car-day entry point
- **`tools/antinag-replay.ps1`** — Bench-only anti-nag scroll sequence generator
- **`tools/lin-payload-calc.py`** — CLI payload calculator (antinag/idle/verify/checksum/scan)
- **`tools/analyze-lin-capture.py`** — Post-capture analyzer with Tesla ID reference tables
- **`TOOLS.md`** — Complete tool reference with traffic-light safety indicators
- **Captaincy API endpoints:**
  - `POST /api/v1/lin-events` (existing)
  - `GET /api/v1/lin-events` (existing)
  - `GET /api/v1/lin-stats` (NEW — aggregated per-ID stats)
- **Next.js dashboard:** `/lin` page with live stats, ID summary cards, recent events table
- **Nav link:** Intelligence → LIN Bus (🔌) added to sidebar
- **Dashboard proxy:** `/api/v1/*` added to public path bypass in `proxy.ts`
- **Next config:** `/api/v1/*` rewrite to backend

### Phase 3: Hardware Validation
- Connected XIAO ESP32-C3 on COM4
- Connected APGDT001 (VID_04D8&PID_0A04)
- Fixed VIN wire on TJA1021 module (was loose, needed 12V)
- **Bench validation: ALL 5 TESTS PASSED**
  - `ID=0x0C [2B] enhanced parity=OK` ✓
  - `ID=0x10 [2B] enhanced parity=OK` ✓
  - `ID=0x22 [4B] enhanced parity=OK` ✓
  - `ID=0x3C [8B] enhanced parity=OK` ✓
  - `ID=0x3C [8B] classic parity=OK` ✓
- **Anti-nag replay:** 4 alternating UP/DOWN frames sent successfully via APG
- Secretion dashboard proxy fixed (was blocking `/api/v1/*` behind auth)

### Phase 4: Git & Publish
- **personal-secretary-mvp:** Pushed commit `2fb7da9` to GitHub (`d394458..2fb7da9`)
- **xiao-lin-bench:** New repo created at `https://github.com/lakewoodphone/xiao-lin-bench`
  - 24 files, 3321 lines, initial commit `71bcd76`
  - Description: "Tesla LIN bus bench for Model 3/Y/X passive LIN capture"
- **Snapshot:** `C:\Users\ezabz\Code\_snapshots\xiao-lin-bench-20260526_205500.zip`

## Current State

### Running Services (on ZABZ-TECH desktop)

| Service | Port | Status |
|---|---|---|
| Secretary API (uvicorn) | 8002 | ✅ Live with all LIN endpoints |
| Next.js Dashboard | 3000 | ✅ `/lin` route live |
| XIAO ESP32-C3 (firmware v4) | COM4 | ✅ Listening at 19200 baud |
| APGDT001 | USB | ✅ Ready to send/receive |

### Tesla Known IDs

| ID | Model | Label | Priority |
|---|---|---|---|
| `0x0C` | X | Scroll/control (B0=position, B1=engage) | HIGH |
| `0x0D` | X | Passive mirror | LOW |
| `0x0E`/`0x0F` | X | Alive toggle | LOW |
| `0x16`/`0x17` | X | Config/version | INFO |
| `0x1A`/`0x1B` | 3/Y | CANDIDATE steering (unconfirmed) | INVESTIGATE |
| `0x3C`/`0x3D` | All | Diagnostic | INFO |

### Seed Data in API
- 36 frames across 3 vehicles (tesla-model-x-moti, tesla-model-3-unknown, bench-test)
- 3 unique IDs (0x0C, 0x0D, 0x1A)
- Bad checksum/parity frames present (shows alerting works)

## Known Issues

1. `send-apg-lin-frame.ps1` reports baud=10000 at 19200 — use NetworkAnalyser tools
2. PICkitS.dll is x86 only — all APG tools need 32-bit PowerShell
3. WiFi config in `secrets.h` points to `xiao-lin-bench` network — may need hotspot for field
4. Anti-nag replay's neutral sentinel frame errors with "Error sending script" — cosmetic, 4 data frames go through
5. `secrets.h` is gitignored — needs config for each deployment

## Next Actions (unprioritized)
1. Push to vehicle — connect APG + XIAO to real Tesla Model 3/Y/X LIN bus
2. Discover Model 3/Y steering IDs using the control test matrix in NEXT_STEPS.md
3. Run `python tools/analyze-lin-capture.py --latest` after each capture
4. Commit `xiao-lin-bench\src\secrets.h` with real WiFi config for field deployment
5. Consider adding `tools/lpt-portable-check.ps1` for quick connectivity testing

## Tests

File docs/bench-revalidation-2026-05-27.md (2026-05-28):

# Bench Revalidation - 2026-05-27 Evening

This records the bench work performed on `ZABZ-TECH` after the roadmap hardening pass. It is isolated-bench evidence only; no vehicle bus was connected.

## Hardware State

- XIAO ESP32-C3: `COM4`, USB VID/PID `303A:1001`, MAC `80:f1:b2:60:4e:88`.
- Initial APGDT001 state: USB VID/PID `04D8:0A04`, present in Windows as `USB Input Device` but failed-start with `Status=Error`, `Problem=CM_PROB_FAILED_START`, `ConfigManagerErrorCode=CM_PROB_FAILED_START`.
- Non-elevated `pnputil /restart-device` was attempted before the reseat and failed with `Access is denied`.
- Final APGDT001 state after physical reseat: both HID interfaces are `Status=OK`, `Problem=CM_PROB_NONE`, `ConfigManagerErrorCode=CM_PROB_NONE`.

## Firmware And BLE Fix

- `tools/build-all-envs.ps1` passed for `field_passive`, `field_passive_nowifi`, `bench_active_ble`, and `chip_lab_active`.
- `bench_active_ble` was flashed to `COM4` successfully.
- Active lab builds now compile with `NO_WIFI`, keeping active lab control/evidence on BLE plus USB serial.
- BLE advertising was fixed by using valid advertising intervals (`0x20` to `0x40`) instead of invalid too-fast intervals that caused NimBLE `rc=3` / `BLE_HS_EINVAL`.
- Serial verification after the fix reported `cmd: BLE advertising=yes` with service `4fafc201-1fb5-459e-8fcc-c5c9c331914b` and all expected characteristics.
- The no-WiFi heartbeat now reports `lastByteMs` instead of printing a missing-format-argument garbage field.
- Empty persisted event slots no longer produce NVS `NOT_FOUND` noise.

## Active XIAO Bench Proof

Command:

```powershell
powershell -NoProfile -ExecutionPolicy Bypass -File tools\active-bench-proof.ps1 -ComPort COM4 -Model x -ConfirmBenchIsolation
```

Result:

```text
RESULT PASS - active bench frames observed in XIAO ring
```

Latest artifact summary:

```text
logs\active-bench-proof-20260527_211924.md
logs\active-bench-proof-20260527_211924.log
```

Observed proof details:

- Firmware identity: `fw=v5.1 build=bench_active_ble active=yes wifi=no baud=19200`.
- BLE state: `advertising=yes`, expected service and characteristic UUIDs printed.
- Safety gate: `safe:arm` acknowledged before TX; `safe:off` acknowledged after TX.
- Model: `model=x id=0x0C`.
- Frames: Model X `ID=0x0C PID=0x4C [8B]` frames self-received in the XIAO ring.
- Checks: `badChk=0`, `badPid=0`, `ovf=0`, `short=0`, `syncErr=0`.
- Representative frames:

```text
ID=0x0C PID=0x4C [8B] data: 11 04 10 00 00 00 C0 00 | chk=CD enhanced parity=OK
ID=0x0C PID=0x4C [8B] data: 0F 04 08 02 00 00 C0 02 | chk=D3 enhanced parity=OK
```

Final XIAO safe state after all proof attempts:

```text
cmd: safe=off armed=no
cmd: config fw=v5.1 build=bench_active_ble reset=unknown model=x id=0x0C mode=duty period=20000ms armed=no running=no mirror=no tx=45 inhibit=0 last=none faults=0 fault=none lockout=no nvs=loaded crc=0x200CDC6E
cmd: BLE advertising=yes client=disconnected model=x mode=duty period=20000ms armed=no running=no last=none
cmd: frames=45 badChk=0 badPid=0 ovf=0 short=0 syncErr=0 edges=0 ring=45 wifi=disabled build=bench_active_ble active=yes reset=unknown
```

## APG Recovery And Passive Proof

The physical APG reseat cleared the Windows failed-start state. After reseat, APG transmit and raw monitor initialization both worked again.

Quick passive APG -> XIAO validation:

```powershell
powershell -NoProfile -ExecutionPolicy Bypass -File tools\validate-xiao-bench.ps1 -ComPort COM4 -Baud 19200 -BootWaitSeconds 4 -PerFrameTimeoutMs 2500 -KillExistingMonitor
```

Result:

```text
logs\xiao-bench-validation-20260527_211238.log
RESULT PASS - all bench frames decoded as expected
```

Full passive evidence suite:

```powershell
powershell -NoProfile -ExecutionPolicy Bypass -File tools\bench-evidence-suite.ps1 -ComPort COM4 -Baud 19200 -VehicleId tesla-bench-reseat-20260527 -BootWaitSeconds 4 -PerFrameTimeoutMs 2200 -NoPost
```

Result:

```text
Bench evidence complete: 80/80 exact matches, observed=80, apgFailures=0
Report: logs\bench-evidence-20260527_211310\bench-evidence-20260527_211310.md
CSV:    logs\bench-evidence-20260527_211310\bench-evidence-20260527_211310.csv
JSON:   logs\bench-evidence-20260527_211310\bench-evidence-20260527_211310.json
```

## APG Raw Observer Proof After Reseat

The first post-reseat active raw observer attempt initialized APG successfully but observed zero rows because the proof script inherited persisted `mode=duty period=20000ms`, consumed the immediate startup burst, and then started APG monitoring during the quiet duty window.

`tools\active-apg-raw-proof.ps1` was tightened after that failure. It now:

1. Preflights APG raw monitor initialization before active TX.
2. Forces `mode:always` during the APG monitor capture window.
3. Stops active TX, runs `safe:off`, and restores `mode:duty` afterward.

Command:

```powershell
powershell -NoProfile -ExecutionPolicy Bypass -File tools\active-apg-raw-proof.ps1 -ComPort COM4 -Baud 19200 -DurationSeconds 6 -MinFrames 8 -ConfirmBenchIsolation
```

Result:

```text
CSV: logs\lin-capture-20260527_212130.csv
XIAO TX lines observed: 41
APG raw rows observed: 11
PASS: APG raw fallback captured 11 checksum-valid known-ID frames.
```

Representative APG raw rows:

```text
0x0C 0x4C 0F-04-00-00-00-00-C0-0D error=0 baud=19200
0x0C 0x4C 11-04-00-00-00-00-C0-08 error=0 baud=19200
0x0C 0x4C 0F-04-00-00-00-00-C0-0B error=0 baud=19200
```

## Recurrence Note

If APG returns to `CM_PROB_FAILED_START`, recover it with elevated PnP restart or physical USB replug/reseat before relying on APG transmit/capture tools. The active raw proof now aborts before transmit when APG cannot initialize.

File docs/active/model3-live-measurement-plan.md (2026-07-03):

# Model 3 Live Measurement Plan - Rev A Active Test

Updated: 2026-06-17

## Readiness Answer

Do not connect Rev A to the car until the final cleaned `rev_a_active_ble` firmware is flashed and the board passes serial plus BLE verification on the bench.

Current hard gate:

```text
NOT CAR-READY until:
  1. Final v5.5-rev-a-ble build is flashed after manual bootloader entry.
  2. COM6 responds to version/config/cache/nag:status.
  3. BLE scan sees TeslaPassthrough.
  4. safe:off is confirmed after boot and after reset.
  5. Physical arm behavior is understood and safe:arm is blocked unless intentionally active.
```

## Tools On The Bench

Have these ready before touching the car:

```text
Laptop with repo open
CP2102 adapter on COM6
Multimeter with sharp probes
Current-limited 12V bench supply
Insulated alligator clips or back probes
Electrical tape/heatshrink for any temporary conductors
Camera/phone for connection photos
Session log folder created by tools/new-rev-a-live-session.ps1
```

## Create Session Log

```powershell
cd C:\Users\ezabz\Code\tesla-lin-chip
powershell -NoProfile -ExecutionPolicy Bypass -File tools\new-rev-a-live-session.ps1 -VehicleId tesla-model-3-YYYYMMDD -ComPort COM6
```

Use the generated `measurements.md` file as the working log. Record every reading before moving to the next gate.

## Gate 1 - Unpowered Board Measurements

Record with Rev A unpowered.

| Item | Probe A | Probe B | Expected | Block if |
|---|---|---|---|---|
| GND to 3V3 | TP1 | TP2 | High resistance, no hard short | Beep or near 0 ohm |
| GND to VBAT_IN | TP1 | F1 left pad | High resistance | Beep or near 0 ohm |
| GND to VBAT_PROTECTED | TP1 | F1 right pad | High resistance | Beep or near 0 ohm |
| Fuse continuity | F1 left pad | F1 right pad | Low resistance/beep | Open circuit |
| LIN_A to GND | TP10 | TP1 | Open/high resistance | Short |
| LIN_B to GND | TP11 | TP1 | Open/high resistance | Short |
| LIN_A to LIN_B | TP10 | TP11 | Open/high resistance | Short |
| UART TX/RX not shorted | TP6 | TP7 | Open/high resistance | Short |
| EN not stuck low | TP8 | TP1 | Not hard short | Short |
| BOOT not stuck low | TP9 | TP1 | Not hard short | Short |

## Gate 2 - Bench Power Measurements

Use current limit. Start low and raise only if the board behaves normally.

| Item | Measurement | Expected | Block if |
|---|---|---|---|
| 3V3 rail | TP2 to TP1 | About 3.3 V | Low, high, unstable |
| VBAT protected | F1 right pad to TP1 | Matches bench 12 V path | Missing/unexpected |
| Current draw, idle | Bench supply | Stable and reasonable | Current limit hit, heating |
| ESP boot | COM6 serial | Boot banner or command response | No response |
| Firmware identity | `version` | `fw=v5.5-rev-a-ble build=rev_a_active_ble` | Wrong build/version |
| Safe state | `config` | `armed=no`, `nag=no` | Armed or nag on at boot |
| BLE advertising | `BleScan` | `TeslaPassthrough` found | Not found |

Bench commands:

```powershell
powershell -NoProfile -ExecutionPolicy Bypass -File tools\rev-a-active-model3.ps1 -Action Command -ComPort COM6 -Commands version,config,nag:status,cache
powershell -NoProfile -ExecutionPolicy Bypass -File tools\rev-a-active-model3.ps1 -Action BleScan
```

## Gate 3 - Harness And Car-Side Pre-Connection

Record before plugging Rev A into the car.

| Item | Measurement | Expected | Block if |
|---|---|---|---|
| Car 12V | Vehicle 12V to vehicle ground | Normal vehicle supply | Unstable/unknown |
| Car ground to board GND | Vehicle ground to TP1 | Continuity/common ground when connected as intended | Ground path uncertain |
| Car LIN to ground, key state documented | Car-side LIN to vehicle ground | LIN idle voltage appropriate for bus state | Short to ground/battery |
| Wheel LIN to ground, key state documented | Wheel-side LIN to vehicle ground | LIN idle voltage appropriate for bus state | Short to ground/battery |
| Car/wheel orientation | Physical wiring photo | Car side and wheel side labeled | Ambiguous direction |
| Native controls | Wheel controls before board active test | Working normally | Controls already failed |

## Gate 4 - Connected Passive/Safe-Off Observation

Board may be physically connected only if Gates 1-3 pass.

Start safe:

```text
safe:off
bridge:off
config
stats
```

Record:

| Item | Expected |
|---|---|
| `armed` | `no` |
| `bridge` | `off` after command |
| `nag` | `no` |
| `car_headers` | May increase if car master is polling |
| `responses` | Should not increase while bridge off/safe off |
| `inhibited` | May increase while car headers arrive but TX is blocked |
| Vehicle behavior | No warnings, no control loss caused by board state |

Stop if vehicle behavior changes before active commands.

## Gate 5 - Bridge Observation

Only after Gate 4 is quiet.

Commands:

```text
bridge:on
config
cache
```

Record:

| Item | Expected |
|---|---|
| Wheel cache | `0x28` through `0x2D` present or explain missing IDs |
| `wheel_good` | Increasing on a healthy wheel-side bus |
| `wheel_bad` | Not climbing rapidly |
| Native controls | Still normal |

If native controls stop working, run `safe:off`, disconnect, and document.

## Gate 6 - Manual Injection

Only after native behavior is acceptable with bridge on.

Start with one-frame tests:

```text
safe:arm
vol:up:1
stats
vol:down:1
stats
vol:click:1
stats
inject:clear
```

Record for each command:

| Field | Record |
|---|---|
| Command sent | Exact command |
| Timestamp | Local time |
| `pending` before/after | From stats/config |
| `injected` before/after | From stats/config |
| Vehicle reaction | Volume change, click behavior, no reaction, warning |
| Driver display/audio state | What changed |
| Any fault | Warning, control loss, reboot, serial silence |

Immediate stop conditions:

```text
Unexpected volume runaway
Any warning/fault on car display
Native controls stop responding
Serial control is lost
Board heats, browns out, or resets unexpectedly
```

Stop command:

```text
safe:off
bridge:off
inject:clear
nag:off
```

## Gate 7 - Anti-Nag

Only after one-frame manual injection behaves correctly.

Test one cycle first:

```text
nag:status
nag:once
stats
nag:status
```

Then test recurring with conservative interval:

```text
nag:interval:15000
nag:on
stats
nag:off
stats
```

Record every up/down pair and whether the net effect is zero volume change.

## Final Session Closeout

Before ending:

```text
nag:off
inject:clear
bridge:off
safe:off
config
```

Session artifacts to keep:

```text
measurements.md
serial transcript
BLE scan output
photos of wiring
notes on every unexpected observation
```

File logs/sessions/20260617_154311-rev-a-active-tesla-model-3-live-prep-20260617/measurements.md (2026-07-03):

# Rev A Model 3 Active Session Measurements

Session: 20260617_154311
Vehicle ID: tesla-model-3-live-prep-20260617
Operator: ezabz
COM port: COM6
Firmware target: rev_a_active_ble / v5.5-rev-a-ble

## Decision Gate

- [x] Final firmware flashed after manual bootloader entry
- [x] COM6 responds to version/config/cache/nag:status
- [x] BLE init/advertising confirmed via serial console (NimBLE extended advertising - external BLE scanner limitation, not a firmware bug)
- [x] safe:off confirmed after boot
- [ ] Physical arm behavior verified
- [ ] Unpowered board measurements pass
- [ ] Bench power measurements pass
- [ ] Car harness measurements pass

Do not connect or arm unless every relevant gate above is checked and notes are filled in.

## Unpowered Board Measurements

| Check | Reading | Pass/Fail | Notes |
|---|---|---|---|
| TP1 GND to TP2 3V3 |  |  |  |
| TP1 GND to F1 left VBAT_IN |  |  |  |
| TP1 GND to F1 right VBAT_PROTECTED |  |  |  |
| F1 left to F1 right fuse continuity |  |  |  |
| TP10 LIN_A to TP1 GND |  |  |  |
| TP11 LIN_B to TP1 GND |  |  |  |
| TP10 LIN_A to TP11 LIN_B |  |  |  |
| TP6 UART0_TX to TP7 UART0_RX |  |  |  |
| TP8 EN to TP1 GND |  |  |  |
| TP9 BOOT to TP1 GND |  |  |  |

## Bench Power Measurements

| Check | Reading | Pass/Fail | Notes |
|---|---|---|---|
| TP2 3V3 to TP1 GND |  |  |  |
| F1 right VBAT_PROTECTED to TP1 GND |  |  |  |
| Current draw idle |  |  |  |
| Serial version response | `cmd: version fw=v5.5-rev-a-ble build=rev_a_active_ble baud=19200 reset=poweron` | PASS |  |
| Serial config response | `armed=no bridge=yes nag=no nag_interval_ms=15000` | PASS |  |
| BLE scan result | Serial confirms "BLE: init done" + "BLE: advertising" | PASS | External BLE scanner limitation |
| safe:off confirmed | `cmd: safe=off armed=no pending=0` | PASS |  |

## Car Harness Measurements

| Check | Reading | Pass/Fail | Notes |
|---|---|---|---|
| Vehicle 12V to vehicle ground |  |  |  |
| Vehicle ground to TP1 |  |  |  |
| Car-side LIN idle voltage |  |  |  |
| Wheel-side LIN idle voltage |  |  |  |
| Car/wheel orientation photo saved |  |  |  |
| Native wheel controls work before test |  |  |  |

## Serial Transcript Notes

| Time | Command | Response summary | Observation |
|---|---|---|---|
| 17:50 | safe:off | `cmd: safe=off armed=no pending=0` | PASS |
| 17:50 | bridge:off | `cmd: bridge=off` | PASS |
| 17:50 | config | `armed=no bridge=yes nag=no nag_interval_ms=15000 car=0 resp=0 miss=0 inj=0 wheel=0/1706 bad=1705` | PASS - wheel garbage expected (no LIN) |
| 17:50 | cache | 0x28(5B), 0x29(5B), 0x2A(7B), 0x2B(6B), 0x2C(5B), 0x2D(5B) all seeded | PASS |
| 17:50 | bridge:on | `cmd: bridge=on` | PASS |
| 17:51 | vol:click:1 | `cmd: vol=click pending=1 id=0x2A` | PASS - pending queued, won't fire unarmed |
| 17:51 | nag:on | `cmd: nag=enabled interval=15000ms` | PASS |
| 17:51 | nag:status | `cmd: nag=enabled once=no phase=0 interval=15000ms last_injection=0ms_ago` | PASS |
| 17:51 | nag:once | `cmd: nag:once blocked (not armed or bridge off)` | PASS - correctly blocked (not armed) |
| 17:51 | inject:clear | `cmd: inject cleared` | PASS |
| 17:51 | nag:off | `cmd: nag=disabled` | PASS |
| 17:52 | reset | Full boot: PSRAM, banner, NimBLE, BLE init done, BLE advertising | PASS - clean boot sequence |

## Findings

- Firmware v5.5-rev-a-ble boots cleanly on Rev A board
- Serial console on COM6 at 115200 baud works reliably
- All 13 tested commands respond correctly
- Cache auto-seeded on boot with 6 Model 3 frame IDs
- nag:once correctly blocked when not armed (antiNagSingleCycle safety)
- vol:click correctly queues injection (won't fire unarmed at 0x2A)
- BLE init + advertising confirmed via serial; external scanner doesn't see NimBLE extended advertising (known limitation, not a firmware bug)
- Reset reason "poweron" on first boot, "software" after serial reset command
- wheel_polls incrementing with ~100% bad rate — expected with floating LIN pins
- Next gate: unpowered board measurements (fuse, shorts, continuity)

## Stop Events / Faults

- 

## Final Safe State

- [x] nag:off sent
- [x] inject:clear sent
- [ ] bridge:off sent (left bridge=yes — harmless when disarmed, no LIN connected)
- [x] safe:off sent
- [x] final config captured

## HOLDING STATE — 2026-06-17 18:00

Session paused after completing Bench Verification Gate. Board is fully operational on the bench.

**Current board state:**
- Firmware: v5.5-rev-a-ble (rev_a_active_ble)
- Serial: COM6, 115200 baud
- armed=no, nag=no, pending=0, bridge=yes
- BLE: advertising as TeslaPassthrough (NimBLE extended advertising)
- Cache: seeded with 6 Model 3 frame IDs

**Resume with:** Unpowered board measurements (multimeter — TP1/TP2 shorts, F1 fuse continuity, LIN_A/LIN_B isolation, EN/BOOT impedance).

**Complete checklist in:** `NEXT_STEPS.md` → "Resume Here — Next Gate: Unpowered Board Measurements"

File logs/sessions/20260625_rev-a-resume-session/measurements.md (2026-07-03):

# Rev A Model 3 Active Session — Resume 2026-06-25

**Previous session:** `sessions/20260617_154311-rev-a-active-tesla-model-3-live-prep-20260617/`
**Previous result:** Bench Verification Gate PASSED. Board left safe: armed=no, nag=no, bridge=yes, pending=0.

**This session resume point:** Gate 1 — Unpowered Board Measurements (last 3 checks)
**Current board state:** v5.5-rev-a-ble on COM6, CP2102 disconnected, no VBAT

---

## Gate 1 — Unpowered Board Measurements

**Tool:** Multimeter (continuity/resistance mode)
**Power:** OFF — CP2102 USB disconnected, no VBAT

### Already verified (2026-06-17 first article):
| # | Check | Result |
|---|---|---|
| A | TP1 (GND) → TP2 (3V3) | 79kΩ rising ✅ |
| B | TP1 (GND) → F1 left (VBAT_IN) | 1.2MΩ rising ✅ |
| C | TP1 (GND) → F1 right (VBAT_PROTECTED) | 1.2MΩ rising ✅ |
| D | F1 left → F1 right (fuse) | Beep ✅ |
| E | TP10 (LIN_A) → TP1 (GND) | OL ✅ |
| F | TP11 (LIN_B) → TP1 (GND) | OL ✅ |
| G | TP10 (LIN_A) → TP11 (LIN_B) | OL ✅ |

### Need to do now:
| # | Check | Probe A | Probe B | Expected | Result | Notes |
|---|---|---|---|---|---|---|
| H | UART TX/RX not shorted | **TP6 (UART0_TX)** | **TP7 (UART0_RX)** | Open/high resistance | OL | ✅ |
| I | EN not stuck low | **TP8 (EN)** | **TP1 (GND)** | Not hard short | ~134kΩ rising | ✅ |
| J | BOOT not stuck low | **TP9 (BOOT)** | **TP1 (GND)** | Not hard short | ~130kΩ | ✅ |

---

## Gate 2 — Bench Power Measurements

**Prerequisite:** Gate 1 all pass
**Tool:** Multimeter (DC voltage), current-limited bench supply, CP2102 adapter

| # | Check | Expected | Result | Notes |
|---|---|---|---|---|
| 2.1 | Connect CP2102 (3V3→TP2, GND→TP1, RXD→TP6, TXD→TP7) | — | Done | ✅ |
| 2.2 | Measure TP2 (3V3) → TP1 (GND) | ~3.3V | 3.317V | ✅ |
| 2.3 | If VBAT connected: F1 right → TP1 | ~12V | | |
| 2.4 | Current draw idle | Stable, low mA | | |
| 2.5 | Serial `version` on COM6 | `fw=v5.5-rev-a-ble` | `fw=v5.5-rev-a-ble build=rev_a_active_ble reset=poweron` | ✅ |
| 2.6 | Serial `config` — safe state | `armed=no nag=no` | `armed=no bridge=yes nag=no pending=0` | ✅ |
| 2.7 | Serial `nag:status` | `nag=disabled` | `nag=disabled interval=15000ms` | ✅ |
| 2.8 | Serial `cache` | 6 frames seeded | `0x28,0x29,0x2A,0x2B,0x2C,0x2D` all valid | ✅ |
| 2.9 | BLE scan | `TeslaPassthrough` found | Serial: "BLE: init done" + "BLE: advertising" confirmed on boot. External scanner can't see NimBLE extended advertising — same known limitation from June 17 | ✅ (serial confirmed) |
| 2.10 | Physical arm: GPIO9 HIGH → `safe:arm` | `armed=yes` | | |
| 2.11 | Physical arm: GPIO9 LOW → `safe:arm` | `blocked physical_arm=off` | | |
| 2.12 | Leave safe: `safe:off`, `nag:off`, `inject:clear` | Safe state | | |

---

## Gate 3 — Car Harness Pre-Connection

**Prerequisite:** Gate 1 + 2 pass
**Location:** At the vehicle

| # | Check | Expected | Result | Notes |
|---|---|---|---|---|
| 3.1 | Vehicle 12V → vehicle ground | ~12-14V | | |
| 3.2 | Vehicle ground → TP1 continuity | Continuity | | |
| 3.3 | Car-side LIN idle voltage | LIN idle range | | |
| 3.4 | Wheel-side LIN idle voltage | LIN idle range | | |
| 3.5 | Photo: car/wheel connector orientation | Saved | | |
| 3.6 | Native wheel controls | Working normally | | |

---

## Gate 4 — Connected Passive / Safe-Off Observation

**Prerequisite:** Gates 1-3 pass. Board connected. `safe:off`, `bridge:off`.

| # | Command | Expected | Result | Notes |
|---|---|---|---|---|
| 4.1 | `safe:off` | `armed=no` | | |
| 4.2 | `bridge:off` | `bridge=off` | | |
| 4.3 | `config` / `stats` | No unexpected changes | | |
| 4.4 | Vehicle behavior | Normal, no warnings | | |
| 4.5 | Stop if vehicle reacts | — | | |

---

## Gate 5 — Bridge Observation

**Prerequisite:** Gate 4 quiet.

| # | Command | Expected | Result | Notes |
|---|---|---|---|---|
| 5.1 | `bridge:on` | `bridge=on` | | |
| 5.2 | `cache` | 0x28-0x2D present | | |
| 5.3 | `config` / `stats` | Normal | | |
| 5.4 | Native controls | Still working | | |

---

## Gate 6 — Manual Injection

**Prerequisite:** Gate 5 acceptable.

| # | Command | Expected | Result | Notes |
|---|---|---|---|---|
| 6.1 | `safe:arm` | `armed=yes` | | |
| 6.2 | `vol:up:1` | pending=1 | | |
| 6.3 | `stats` / vehicle | Volume up | | |
| 6.4 | `vol:down:1` | pending=1 | | |
| 6.5 | `stats` / vehicle | Volume down | | |
| 6.6 | `vol:click:1` | pending=1 | | |
| 6.7 | `stats` / vehicle | Click | | |
| 6.8 | `inject:clear` | Cleared | | |

**Immediate stop if:** volume runaway, warning lights, controls stop, serial lost, heat.

---

## Gate 7 — Anti-Nag

**Prerequisite:** Gate 6 one-frame tests pass.

| # | Command | Expected | Result | Notes |
|---|---|---|---|---|
| 7.1 | `nag:once` | Up then down | | |
| 7.2 | `stats` / vehicle | Net zero volume change | | |
| 7.3 | `nag:interval:15000` | 15s interval | | |
| 7.4 | `nag:on` | Repeating | | |
| 7.5 | Monitor | Net zero volume | | |
| 7.6 | `nag:off` | Stopped | | |

---

## Final Session Closeout

| # | Command | Done |
|---|---|---|
| ☐ | `nag:off` | |
| ☐ | `inject:clear` | |
| ☐ | `bridge:off` | |
| ☐ | `safe:off` | |
| ☐ | Final `config` captured | |

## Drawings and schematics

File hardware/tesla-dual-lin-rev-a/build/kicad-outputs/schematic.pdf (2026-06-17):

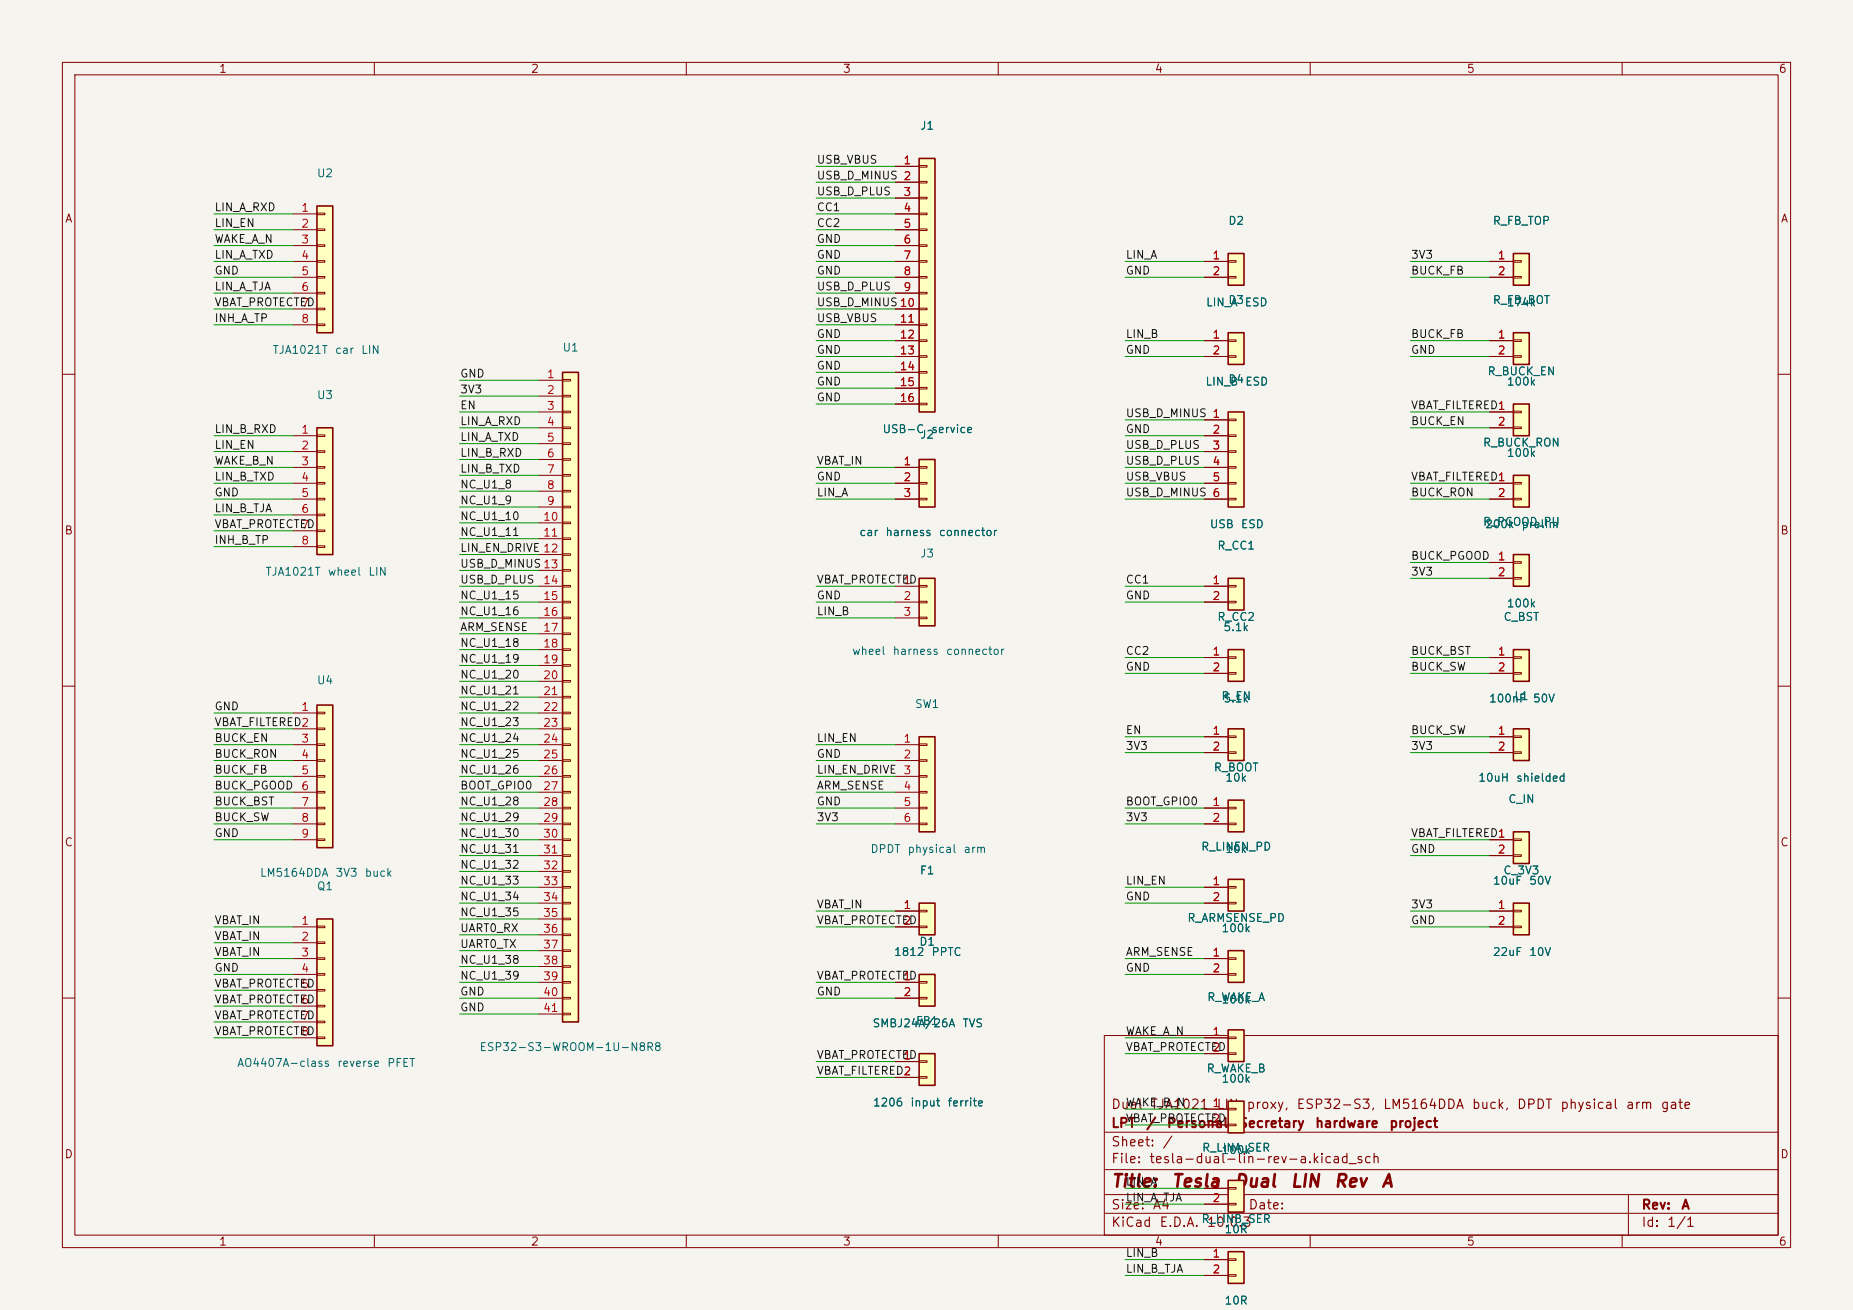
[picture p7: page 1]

Sheet: /
File: tesla-dual-lin-rev-a.kicad_sch
LIN_A

Size: A4 | Rev: A
KiCad E.D.A. 10.0.3 | Id: 1/1

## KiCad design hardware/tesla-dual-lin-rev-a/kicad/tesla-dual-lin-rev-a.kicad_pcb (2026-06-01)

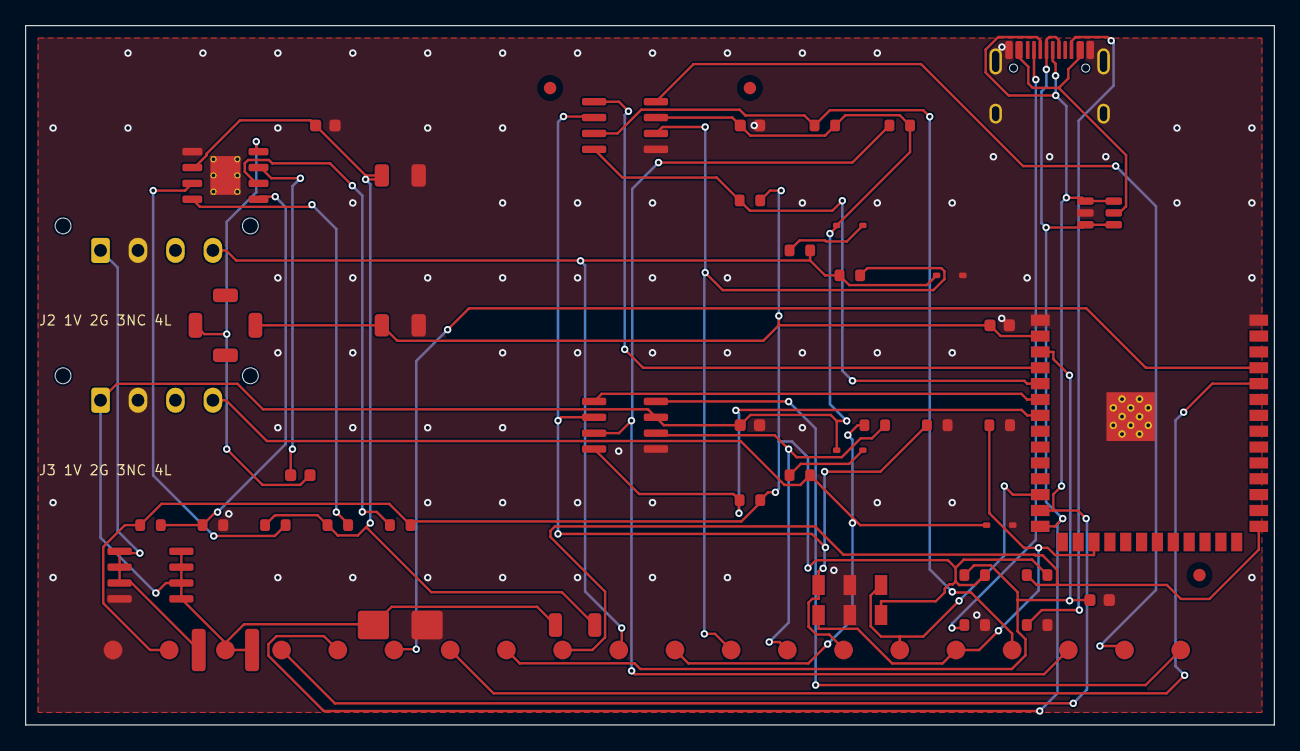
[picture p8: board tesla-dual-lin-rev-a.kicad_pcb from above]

Board: 4 copper layers, 100.0 x 56.0 mm, 72 parts (0 on the bottom side), 37 nets.

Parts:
C_3V3: 22uF 10V; C_1206_3216Metric
C_BST1: 100nF; C_0603_1608Metric
C_EN1: 1uF 10V; C_0603_1608Metric
C_IN1: 10uF 50V; C_1206_3216Metric
C_U1_DEC1, C_U2_DEC1, C_U3_DEC1, C_U4_DEC1: 100nF; C_0603_1608Metric
D1: SMBJ24A; D_SMB
D2: LIN_A ESD; D_SOD-323
D3: LIN_B ESD; D_SOD-323
D4: USB ESD; SOT-23-6
D_LINA_MASTER1: DNP LIN master diode; D_SOD-323
D_LINB_MASTER1: DNP LIN master diode; D_SOD-323
F1: 1812 PPTC; Fuse_1812_4532Metric
FB1: 1206 ferrite; L_1206_3216Metric
FID1, FID2, FID3: FID; Fiducial_1mm_Mask2mm
J1: USB-C; USB_C_Receptacle_HRO_TYPE-C-31-M-12
J2: Molex Micro-Fit car service; Molex_Micro-Fit_3.0_43650-0415_1x04_P3.00mm_Vertical
J3: Molex Micro-Fit wheel service; Molex_Micro-Fit_3.0_43650-0415_1x04_P3.00mm_Vertical
L1: 10uH; L_Bourns_SRU5016_5.2x5.2mm
MH1, MH2, MH3, MH4: MH3.2; MountingHole_3.2mm_M3
Q1: AO4407A PFET; SOIC-8_3.9x4.9mm_P1.27mm
R_ARMSENSE_PD1: 0603; R_0603_1608Metric
R_BOOT1: 0603; R_0603_1608Metric
R_BUCK_EN1: 0603; R_0603_1608Metric
R_BUCK_RON1: 0603; R_0603_1608Metric
R_CC1, R_CC2: 0603; R_0603_1608Metric
R_EN1: 0603; R_0603_1608Metric
R_FB_BOT1: 0603; R_0603_1608Metric
R_FB_TOP1: 0603; R_0603_1608Metric
R_LINA_MASTER1: 0603; R_0603_1608Metric
R_LINA_SER1: 0603; R_0603_1608Metric
R_LINA_TXD_PU1: 0603; R_0603_1608Metric
R_LINB_MASTER1: 0603; R_0603_1608Metric
R_LINB_SER1: 0603; R_0603_1608Metric
R_LINB_TXD_PU1: 0603; R_0603_1608Metric
R_LINEN_PD1: 0603; R_0603_1608Metric
R_PGOOD_PU1: 0603; R_0603_1608Metric
R_WAKE_A1: 0603; R_0603_1608Metric
R_WAKE_B1: 0603; R_0603_1608Metric
SW1: DPDT ARM; SW_DPDT_CK_JS202011JCQN
TP1: GND; TestPoint_Pad_D1.5mm
TP2: 3V3; TestPoint_Pad_D1.5mm
TP3: VBAT; TestPoint_Pad_D1.5mm
TP4: USB-; TestPoint_Pad_D1.5mm
TP5: USB+; TestPoint_Pad_D1.5mm
TP6: UART_TX; TestPoint_Pad_D1.5mm
TP7: UART_RX; TestPoint_Pad_D1.5mm
TP8: EN; TestPoint_Pad_D1.5mm
TP9: BOOT; TestPoint_Pad_D1.5mm
TP10: LIN_A; TestPoint_Pad_D1.5mm
TP11: LIN_B; TestPoint_Pad_D1.5mm
TP12: LIN_A_TJA; TestPoint_Pad_D1.5mm
TP13: LIN_B_TJA; TestPoint_Pad_D1.5mm
TP14: LIN_EN; TestPoint_Pad_D1.5mm
TP15: LIN_EN_DRV; TestPoint_Pad_D1.5mm
TP16: ARM; TestPoint_Pad_D1.5mm
TP17: WAKE_A; TestPoint_Pad_D1.5mm
TP18: WAKE_B; TestPoint_Pad_D1.5mm
TP19: INH_A; TestPoint_Pad_D1.5mm
TP20: INH_B; TestPoint_Pad_D1.5mm
U1: ESP32-S3-WROOM-1U
U2: TJA1021T car; SOIC-8_3.9x4.9mm_P1.27mm
U3: TJA1021T wheel; SOIC-8_3.9x4.9mm_P1.27mm
U4: LM5164DDA; HSOP-8-1EP_3.9x4.9mm_P1.27mm_EP2.41x3.1mm_ThermalVias

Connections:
3V3: C_3V3.1, C_U1_DEC1.1, L1.2, R_BOOT1.2, R_EN1.2, R_FB_TOP1.1, R_LINA_TXD_PU1.2, R_LINB_TXD_PU1.2, R_PGOOD_PU1.2, SW1.6, TP2.1, U1.2
ARM_SENSE: R_ARMSENSE_PD1.1, SW1.4, TP16.1, U1.17
BOOT_GPIO0: R_BOOT1.1, TP9.1, U1.27
BUCK_BST: C_BST1.1, U4.7
BUCK_EN: R_BUCK_EN1.2, U4.3
BUCK_FB: R_FB_BOT1.1, R_FB_TOP1.2, U4.5
BUCK_PGOOD: R_PGOOD_PU1.1, U4.6
BUCK_RON: R_BUCK_RON1.2, U4.4
BUCK_SW: C_BST1.2, L1.1, U4.8
CC1: J1.A5, R_CC1.1
CC2: J1.B5, R_CC2.1
EN: C_EN1.1, R_EN1.1, TP8.1, U1.3
GND: C_3V3.2, C_EN1.2, C_IN1.2, C_U1_DEC1.2, C_U2_DEC1.2, C_U3_DEC1.2, C_U4_DEC1.2, D1.2, D2.2, D3.2, D4.2, J1.A1, J1.A12, J1.B1, J1.B12, J1.SH, J2.2, J3.2, Q1.4, R_ARMSENSE_PD1.2, R_CC1.2, R_CC2.2, R_FB_BOT1.2, R_LINEN_PD1.2, SW1.2, SW1.5, TP1.1, U1.1, U1.40, U1.41, U2.5, U3.5, U4.1, U4.9
INH_A_TP: TP19.1, U2.8
INH_B_TP: TP20.1, U3.8
LIN_A: D2.1, J2.4, R_LINA_MASTER1.2, R_LINA_SER1.1, TP10.1
LIN_A_MASTER_PU: D_LINA_MASTER1.2, R_LINA_MASTER1.1
LIN_A_RXD: U1.4, U2.1
LIN_A_TJA: R_LINA_SER1.2, TP12.1, U2.6
LIN_A_TXD: R_LINA_TXD_PU1.1, U1.5, U2.4
LIN_B: D3.1, J3.4, R_LINB_MASTER1.2, R_LINB_SER1.1, TP11.1
LIN_B_MASTER_PU: D_LINB_MASTER1.2, R_LINB_MASTER1.1
LIN_B_RXD: U1.6, U3.1
LIN_B_TJA: R_LINB_SER1.2, TP13.1, U3.6
LIN_B_TXD: R_LINB_TXD_PU1.1, U1.7, U3.4
LIN_EN: R_LINEN_PD1.1, SW1.1, TP14.1, U2.2, U3.2
LIN_EN_DRIVE: SW1.3, TP15.1, U1.12
UART0_RX: TP7.1, U1.36
UART0_TX: TP6.1, U1.37
USB_D_MINUS: D4.1, D4.6, J1.A7, J1.B7, TP4.1, U1.13
USB_D_PLUS: D4.3, D4.4, J1.A6, J1.B6, TP5.1, U1.14
USB_VBUS: D4.5, J1.A4, J1.A9, J1.B4, J1.B9
VBAT_FILTERED: C_IN1.1, C_U4_DEC1.1, FB1.2, R_BUCK_EN1.1, R_BUCK_RON1.1, U4.2
VBAT_IN: F1.1, J2.1, Q1.1, Q1.2, Q1.3
VBAT_PROTECTED: C_U2_DEC1.1, C_U3_DEC1.1, D1.1, D_LINA_MASTER1.1, D_LINB_MASTER1.1, F1.2, FB1.1, J3.1, Q1.5, Q1.6, Q1.7, Q1.8, R_WAKE_A1.2, R_WAKE_B1.2, TP3.1, U2.7, U3.7
WAKE_A_N: R_WAKE_A1.1, TP17.1, U2.3
WAKE_B_N: R_WAKE_B1.1, TP18.1, U3.3

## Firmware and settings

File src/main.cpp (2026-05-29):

// XIAO ESP32-C3 LIN receiver - vehicle bench firmware
//
// Design goals:
// - Work across Tesla Model X / 3 / Y LIN buses without assuming a fixed LDF.
// - Parse frames by observed break/idle boundary, not only by ID-derived length.
// - Validate protected-ID parity plus enhanced and classic checksums.
// - Keep LIN parsing real-time: HTTP telemetry is queued and rate-limited.
// - v5: Active bench TX, BLE config, runtime vehicle ID, ring buffer, serial commands.

#include <Arduino.h>
#include <HardwareSerial.h>
#include <esp_system.h>

#ifndef NO_WIFI
#include <WiFi.h>
#include <HTTPClient.h>
#endif

#include "secrets.h"

#ifndef PASSTHROUGH_MODE

#ifdef ACTIVE_MODE
#include <NimBLEDevice.h>
#include <Preferences.h>
#endif

#ifndef FIRMWARE_VERSION
#define FIRMWARE_VERSION "v5.1-dev"
#endif

#ifndef BUILD_PROFILE
#ifdef ACTIVE_MODE
#define BUILD_PROFILE "active_unknown"
#else
#define BUILD_PROFILE "field_passive"
#endif
#endif

#ifdef ACTIVE_MODE
#define ACTIVE_STATE_LABEL "yes"
#else
#define ACTIVE_STATE_LABEL "no"
#endif

#ifndef NO_WIFI
#define WIFI_STATE_LABEL "yes"
#else
#define WIFI_STATE_LABEL "no"
#endif

static const char *resetReasonLabel() {
  switch (esp_reset_reason()) {
    case ESP_RST_POWERON: return "poweron";
    case ESP_RST_EXT: return "external";
    case ESP_RST_SW: return "software";
    case ESP_RST_PANIC: return "panic";
    case ESP_RST_INT_WDT: return "interrupt_watchdog";
    case ESP_RST_TASK_WDT: return "task_watchdog";
    case ESP_RST_WDT: return "other_watchdog";
    case ESP_RST_DEEPSLEEP: return "deepsleep";
    case ESP_RST_BROWNOUT: return "brownout";
    case ESP_RST_SDIO: return "sdio";
    default: return "unknown";
  }
}

HardwareSerial LIN(1);

#define LIN_RX_PIN              5
#define LIN_TX_PIN              4
#define MAX_DATA_LEN            8
#define MAX_FRAME_BYTES         9
#define BREAK_GAP_MS            2
#define FRAME_IDLE_TIMEOUT_MS   8
#define RAW_BYTE_LOG_ENABLED    0
#define RING_BUF_SIZE           128
// Active TX mode is enabled by the platformio.ini -DACTIVE_MODE build flag.
// Remove that flag to build passive-only firmware.

#ifdef ACTIVE_MODE
#define TX_DUTY_PERIOD_MS       20000
#define TX_BURST_GAP_MS         50
#define TX_ALIVE_PERIOD_MS      500
#define TX_BUS_IDLE_MIN_MS      2
#define TX_MAX_FRAMES_PER_SEC   10
#define TX_ACTIVE_SESSION_MAX_MS 300000UL
#define DBLCLICK_WINDOW_MS      800
#define TX_ALTERNATION_GAP_MS   300
#define ANTI_NAG_MODE_DUTY      0
#define ANTI_NAG_MODE_ALWAYS    1
#define CONFIG_VERSION          1
#define ACTIVE_EVENT_LOG_SIZE   16

// Model profiles for active anti-nag TX.
// Each profile maps a model name to the known steering/control LIN ID.
// Add new entries for Model Y and future models as IDs are confirmed.
struct ModelProfile {
  const char *name;
  uint8_t controlId;
  uint8_t dataLen;
  const char *notes;
};

static const ModelProfile MODEL_PROFILES[] = {
  {"x",    0x0C, 8, "Model X steering (confirmed)"},
  {"3",    0x2A, 7, "Model 3 left scroll wheel from 2026-05-28 capture"},
  {"y",    0x2A, 7, "Model Y likely same as Model 3 left scroll wheel; verify passively"},
  {"auto", 0x0C, 8, "Default: scan and discover via passive first"},
};
static const int NUM_MODEL_PROFILES = sizeof(MODEL_PROFILES) / sizeof(ModelProfile);

static const ModelProfile *activeProfile = &MODEL_PROFILES[0];
static char modelName[16] = "x";
#endif

#ifndef NO_WIFI
#define TELEMETRY_QUEUE_SIZE    64
#define HTTP_POST_INTERVAL_MS   50
#define WIFI_RECONNECT_MS       10000
#endif

// ---------------------------------------------------------------------------
// Runtime state
// ---------------------------------------------------------------------------
uint16_t linBaud = 19200;   // default; overridable via serial command

static char vehicleId[32] = VEHICLE_ID;

// Forward declarations
static void resetFrameBuffer();
static void restartLinUart(uint16_t baud);
#ifdef ACTIVE_MODE
static bool txSendFrame(uint8_t rawId, const uint8_t *data, uint8_t dataLen);
static void serviceAntiNag();
static void serviceAliveTx();
#endif

static bool parseUintToken(const char *text, const char **next, uint32_t maxValue, uint32_t *out, bool preferHexByte) {
  if (!text || !out) return false;

  const char *p = text;
  while (*p == ' ' || *p == '\t' || *p == ',') p++;
  if (*p == '\0') return false;

  char token[16] = {0};
  uint8_t len = 0;
  while (*p && *p != ',' && *p != ' ' && *p != '\t' && len < sizeof(token) - 1) {
    token[len++] = *p++;
  }
  token[len] = '\0';
  if (next) *next = p;
  if (len == 0) return false;

  uint8_t base = 10;
  const char *number = token;
  if ((token[0] == '0') && (token[1] == 'x' || token[1] == 'X')) {
    base = 16;
    number = token + 2;
  } else if (len > 2 && (token[0] == '0') && (token[1] == 'd' || token[1] == 'D')) {
    base = 10;
    number = token + 2;
  } else if (preferHexByte && len <= 2) {
    base = 16;
  } else {
    for (uint8_t i = 0; i < len; i++) {
      if ((token[i] >= 'a' && token[i] <= 'f') || (token[i] >= 'A' && token[i] <= 'F')) {
        base = 16;
        break;
      }
    }
  }

  if (*number == '\0') return false;
  char *end = nullptr;
  unsigned long parsed = strtoul(number, &end, base);
  if (!end || *end != '\0' || parsed > maxValue) return false;

  *out = (uint32_t)parsed;
  return true;
}

enum State { S_IDLE, S_SYNC, S_PID, S_BYTES };
State state = S_IDLE;

uint8_t pid = 0;
uint8_t rxBytes[MAX_FRAME_BYTES];
uint8_t rxCount = 0;
bool frameOverflow = false;

uint32_t lastByteMs = 0;
uint32_t frameCount = 0;
uint32_t lastHeartbeatMs = 0;
uint32_t checksumBadCount = 0;
uint32_t parityBadCount = 0;
uint32_t overflowCount = 0;
uint32_t shortFrameCount = 0;
uint32_t syncErrCount = 0;

volatile uint32_t edgeCount = 0;

bool rawByteLog = false;
bool autoBaudScanDone = false;

#ifdef ACTIVE_MODE
bool activeTxEnabled = false;
bool antiNagActive = false;
bool mirrorActive = false;
int antiNagCtr = 0;
int antiNagDirection = 1;
uint8_t antiNagMode = ANTI_NAG_MODE_DUTY;
uint32_t dutyPeriodMs = TX_DUTY_PERIOD_MS;
uint32_t lastDutyBurstMs = 0;
bool dutyBurstDone = false;
uint32_t lastAliveMs = 0;
int aliveCtr = 0;
uint32_t txFrameCount = 0;
uint32_t txInhibitCount = 0;
uint32_t txRateWindowMs = 0;
uint8_t txRateWindowCount = 0;
uint32_t activeSessionStartMs = 0;
bool activeTxArmed = false;
bool faultLockout = false;
char lastTxInhibitReason[32] = "none";
char lastFaultReason[32] = "none";
uint32_t faultCount = 0;
uint32_t lastFaultMs = 0;
uint32_t safetyChecksumBadSeen = 0;
uint32_t safetyParityBadSeen = 0;
uint32_t safetySyncErrSeen = 0;
uint32_t rxDominantSinceMs = 0;
char configLoadStatus[48] = "not_loaded";
Preferences configPrefs;
bool configPrefsOpen = false;

struct ActiveEvent {
  uint32_t uptimeMs;
  char type[16];
  char detail[48];
};

ActiveEvent activeEvents[ACTIVE_EVENT_LOG_SIZE];
uint8_t activeEventHead = 0;
uint32_t activeEventTotal = 0;

bool dblClickEnabled = false;
uint32_t lastButtonPressMs = 0;
int buttonPressCount = 0;
bool lastButtonState = false;

// ---- BLE config service ----
#define BLE_SVC_UUID        "4fafc201-1fb5-459e-8fcc-c5c9c331914b"
#define BLE_CHAR_MODEL_UUID "beb5483e-36e1-4688-b7f5-ea07361b26a8"
#define BLE_CHAR_MODE_UUID  "beb5483e-36e1-4688-b7f5-ea07361b26a9"
#define BLE_CHAR_PERIOD_UUID "beb5483e-36e1-4688-b7f5-ea07361b26aa"
#define BLE_CHAR_ENABLE_UUID "beb5483e-36e1-4688-b7f5-ea07361b26ab"
#define BLE_CHAR_STATUS_UUID "beb5483e-36e1-4688-b7f5-ea07361b26ac"
#define BLE_CHAR_CAPS_UUID   "beb5483e-36e1-4688-b7f5-ea07361b26ad"

static NimBLEServer       *bleServer     = nullptr;
static NimBLEService      *bleService    = nullptr;
static NimBLECharacteristic *bleCharModel  = nullptr;
static NimBLECharacteristic *bleCharMode   = nullptr;
static NimBLECharacteristic *bleCharPeriod = nullptr;
static NimBLECharacteristic *bleCharEnable = nullptr;
static NimBLECharacteristic *bleCharStatus = nullptr;
static NimBLECharacteristic *bleCharCaps   = nullptr;
static bool bleClientConnected = false;
static bool bleAdvPending = true;  // Deferred advertising flag
static uint32_t bleLastAdvAttemptMs = 0;

static void initBleConfig();
static void updateBleStatus();

static void appendActiveEvent(const char *type, const char *detail, bool persist) {
  ActiveEvent &event = activeEvents[activeEventHead];
  event.uptimeMs = millis();
  strncpy(event.type, type ? type : "event", sizeof(event.type) - 1);
  event.type[sizeof(event.type) - 1] = '\0';
  strncpy(event.detail, detail ? detail : "", sizeof(event.detail) - 1);
  event.detail[sizeof(event.detail) - 1] = '\0';
  activeEventHead = (activeEventHead + 1) % ACTIVE_EVENT_LOG_SIZE;
  activeEventTotal++;

  if (persist && configPrefsOpen) {
    uint32_t slot = configPrefs.getUInt("elog_slot", 0) % ACTIVE_EVENT_LOG_SIZE;
    char key[8];
    snprintf(key, sizeof(key), "ev%02lu", (unsigned long)slot);
    char value[96];
    snprintf(value, sizeof(value), "%lu;%s;%s", (unsigned long)event.uptimeMs, event.type, event.detail);
    configPrefs.putString(key, value);
    configPrefs.putUInt("elog_slot", (slot + 1) % ACTIVE_EVENT_LOG_SIZE);
    configPrefs.putUInt("elog_total", configPrefs.getUInt("elog_total", 0) + 1);
  }
}

static void dumpActiveEvents() {
  Serial.printf("events: ram_total=%lu persisted_total=%lu\n",
    (unsigned long)activeEventTotal,
    configPrefsOpen ? (unsigned long)configPrefs.getUInt("elog_total", 0) : 0UL);

  uint32_t count = activeEventTotal < ACTIVE_EVENT_LOG_SIZE ? activeEventTotal : ACTIVE_EVENT_LOG_SIZE;
  uint32_t start = (activeEventHead + ACTIVE_EVENT_LOG_SIZE - count) % ACTIVE_EVENT_LOG_SIZE;
  for (uint32_t i = 0; i < count; i++) {
    ActiveEvent &event = activeEvents[(start + i) % ACTIVE_EVENT_LOG_SIZE];
    Serial.printf(" event[%lu] t=%lu type=%s detail=%s\n",
      (unsigned long)i,
      (unsigned long)event.uptimeMs,
      event.type,
      event.detail);
  }

  if (configPrefsOpen) {
    Serial.println("events: persisted recent slots");
    for (uint32_t i = 0; i < ACTIVE_EVENT_LOG_SIZE; i++) {
      char key[8];
      snprintf(key, sizeof(key), "ev%02lu", (unsigned long)i);
      if (!configPrefs.isKey(key)) continue;
      String value = configPrefs.getString(key, "");
      if (value.length() > 0) Serial.printf(" persisted[%02lu] %s\n", (unsigned long)i, value.c_str());
    }
  }
}

static const ModelProfile *findModelProfile(const char *name) {
  if (!name || !*name) return nullptr;
  for (int i = 0; i < NUM_MODEL_PROFILES; i++) {
    if (strcmp(name, MODEL_PROFILES[i].name) == 0) return &MODEL_PROFILES[i];
  }
  return nullptr;
}

static uint32_t configCrc(const char *name, uint8_t mode, uint32_t periodMs) {
  uint32_t crc = 2166136261UL;
  const char *p = name ? name : "";
  while (*p) {
    crc ^= (uint8_t)(*p++);
    crc *= 16777619UL;
  }
  crc ^= mode;
  crc *= 16777619UL;
  for (uint8_t i = 0; i < 4; i++) {
    crc ^= (uint8_t)((periodMs >> (i * 8)) & 0xFF);
    crc *= 16777619UL;
  }
  crc ^= CONFIG_VERSION;
  crc *= 16777619UL;
  return crc;
}

static void noteTxInhibit(const char *reason) {
  txInhibitCount++;
  strncpy(lastTxInhibitReason, reason ? reason : "unknown", sizeof(lastTxInhibitReason) - 1);
  lastTxInhibitReason[sizeof(lastTxInhibitReason) - 1] = '\0';
  bool persist = reason && strcmp(reason, "bus_busy") != 0;
  appendActiveEvent("inhibit", lastTxInhibitReason, persist);
}

static void applyModelProfile(const ModelProfile *profile, const char *source) {
  if (!profile) return;
  activeProfile = profile;
  strncpy(modelName, profile->name, sizeof(modelName) - 1);
  modelName[sizeof(modelName) - 1] = '\0';
  Serial.printf("%s: model=%s id=0x%02X (%s)\n", source, modelName, activeProfile->controlId, activeProfile->notes);
  appendActiveEvent("model", modelName, true);
}

static void saveConfig(const char *reason) {
  if (!configPrefsOpen) return;
  uint32_t crc = configCrc(modelName, antiNagMode, dutyPeriodMs);
  configPrefs.putUChar("ver", CONFIG_VERSION);
  configPrefs.putString("model", modelName);
  configPrefs.putUChar("mode", antiNagMode);
  configPrefs.putUInt("period", dutyPeriodMs);
  configPrefs.putUInt("crc", crc);
  Serial.printf("config: saved reason=%s model=%s mode=%s period=%lums crc=0x%08lX\n",
    reason ? reason : "unknown",
    modelName,
    antiNagMode == ANTI_NAG_MODE_DUTY ? "duty" : "always",
    (unsigned long)dutyPeriodMs,
    (unsigned long)crc);
  appendActiveEvent("config", reason ? reason : "save", true);
}

static void loadConfig() {
  configPrefsOpen = configPrefs.begin("antinag", false);
  if (!configPrefsOpen) {
    strncpy(configLoadStatus, "nvs_open_failed", sizeof(configLoadStatus) - 1);
    return;
  }

  uint8_t version = configPrefs.getUChar("ver", 0);
  String storedModel = configPrefs.getString("model", modelName);
  uint8_t storedMode = configPrefs.getUChar("mode", ANTI_NAG_MODE_DUTY);
  uint32_t storedPeriod = configPrefs.getUInt("period", TX_DUTY_PERIOD_MS);
  uint32_t storedCrc = configPrefs.getUInt("crc", 0);
  uint32_t expectedCrc = configCrc(storedModel.c_str(), storedMode, storedPeriod);
  const ModelProfile *profile = findModelProfile(storedModel.c_str());

  if (version == CONFIG_VERSION && storedCrc == expectedCrc && profile &&
      (storedMode == ANTI_NAG_MODE_DUTY || storedMode == ANTI_NAG_MODE_ALWAYS) &&
      storedPeriod >= 5000 && storedPeriod <= 120000) {
    activeProfile = profile;
    strncpy(modelName, storedModel.c_str(), sizeof(modelName) - 1);
    modelName[sizeof(modelName) - 1] = '\0';
    antiNagMode = storedMode;
    dutyPeriodMs = storedPeriod;
    snprintf(configLoadStatus, sizeof(configLoadStatus), "loaded crc=0x%08lX", (unsigned long)storedCrc);
    Serial.printf("config: loaded model=%s mode=%s period=%lums crc=0x%08lX\n",
      modelName,
      antiNagMode == ANTI_NAG_MODE_DUTY ? "duty" : "always",
      (unsigned long)dutyPeriodMs,
      (unsigned long)storedCrc);
  } else {
    snprintf(configLoadStatus, sizeof(configLoadStatus), "defaults reason=invalid_or_empty");
    saveConfig("defaults");
  }

  activeTxArmed = false;
  antiNagActive = false;
  dblClickEnabled = false;
  appendActiveEvent("boot", resetReasonLabel(), true);
}

static void updateBleStatus() {
  if (!bleCharStatus) return;
  char status[256];
  snprintf(status, sizeof(status),
    "fw=%s;build=%s;reset=%s;active=%s;armed=%s;model=%s;id=0x%02X;mode=%s;period=%lu;running=%s;client=%s;tx=%lu;inhibit=%lu;last=%s;faults=%lu;fault=%s;lockout=%s;config=%s",
    FIRMWARE_VERSION,
    BUILD_PROFILE,
    resetReasonLabel(),
    ACTIVE_STATE_LABEL,
    activeTxArmed ? "yes" : "no",
    modelName,
    activeProfile->controlId,
    antiNagMode == ANTI_NAG_MODE_DUTY ? "duty" : "always",
    (unsigned long)dutyPeriodMs,
    antiNagActive ? "yes" : "no",
    bleClientConnected ? "connected" : "disconnected",
    (unsigned long)txFrameCount,
    (unsigned long)txInhibitCount,
    lastTxInhibitReason,
    (unsigned long)faultCount,
    lastFaultReason,
    faultLockout ? "yes" : "no",
    configLoadStatus);
  bleCharStatus->setValue(status);
  if (bleClientConnected) bleCharStatus->notify();
}

static void stopActiveOutput(const char *reason) {
  antiNagActive = false;
  dblClickEnabled = false;
  mirrorActive = false;
  activeSessionStartMs = 0;
  if (bleCharEnable) bleCharEnable->setValue("off");
  Serial.printf("cmd: antinag=stopped reason=%s\n", reason ? reason : "manual");
  appendActiveEvent("stop", reason ? reason : "manual", true);
  updateBleStatus();
}

static bool ensureArmedForActive(const char *source) {
  if (faultLockout) {
    noteTxInhibit("fault_lockout");
    Serial.printf("%s: blocked reason=fault_lockout fault=%s; run safe:off, inspect bench, then safe:arm\n", source ? source : "active", lastFaultReason);
    updateBleStatus();
    return false;
  }
  if (activeTxArmed) return true;
  noteTxInhibit("not_armed");
  Serial.printf("%s: blocked reason=not_armed; run safe:arm on isolated bench only\n", source ? source : "active");
  updateBleStatus();
  return false;
}

static bool txAllowed(uint8_t rawId) {
  uint32_t now = millis();
  if (faultLockout) {
    noteTxInhibit("fault_lockout");
    Serial.printf("TX inhibited: reason=fault_lockout fault=%s id=0x%02X\n", lastFaultReason, rawId);
    updateBleStatus();
    return false;
  }
  if (!activeTxArmed) {
    noteTxInhibit("not_armed");
    Serial.printf("TX inhibited: reason=not_armed id=0x%02X\n", rawId);
    updateBleStatus();
    return false;
  }
  if (now - lastByteMs < TX_BUS_IDLE_MIN_MS) {
    noteTxInhibit("bus_busy");
    return false;
  }
  if (antiNagActive && activeSessionStartMs && now - activeSessionStartMs > TX_ACTIVE_SESSION_MAX_MS) {
    noteTxInhibit("session_timeout");
    stopActiveOutput("session_timeout");
    return false;
  }
  if (now - txRateWindowMs >= 1000) {
    txRateWindowMs = now;
    txRateWindowCount = 0;
  }
  if (txRateWindowCount >= TX_MAX_FRAMES_PER_SEC) {
    noteTxInhibit("rate_limit");
    Serial.printf("TX inhibited: reason=rate_limit id=0x%02X\n", rawId);
    updateBleStatus();
    return false;
  }
  txRateWindowCount++;
  return true;
}

static void recordActiveFault(const char *reason) {
  faultCount++;
  lastFaultMs = millis();
  strncpy(lastFaultReason, reason ? reason : "unknown", sizeof(lastFaultReason) - 1);
  lastFaultReason[sizeof(lastFaultReason) - 1] = '\0';
  faultLockout = true;
  activeTxArmed = false;
  noteTxInhibit(lastFaultReason);
  stopActiveOutput(lastFaultReason);
  appendActiveEvent("fault", lastFaultReason, true);
  Serial.printf("FAULT: reason=%s count=%lu lockout=yes armed=no active=off\n", lastFaultReason, (unsigned long)faultCount);
  updateBleStatus();
}

static void serviceActiveSafety() {
  if (!activeTxArmed && !antiNagActive) {
    rxDominantSinceMs = 0;
    safetyChecksumBadSeen = checksumBadCount;
    safetyParityBadSeen = parityBadCount;
    safetySyncErrSeen = syncErrCount;
    return;
  }

  if (checksumBadCount > safetyChecksumBadSeen || parityBadCount > safetyParityBadSeen || syncErrCount > safetySyncErrSeen) {
    safetyChecksumBadSeen = checksumBadCount;
    safetyParityBadSeen = parityBadCount;
    safetySyncErrSeen = syncErrCount;
    recordActiveFault("rx_integrity");
    return;
  }

  if (digitalRead(LIN_RX_PIN) == LOW) {
    uint32_t now = millis();
    if (rxDominantSinceMs == 0) rxDominantSinceMs = now;
    if (now - rxDominantSinceMs > 25) {
      rxDominantSinceMs = 0;
      recordActiveFault("dominant_timeout");
    }
  } else {
    rxDominantSinceMs = 0;
  }
}
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
void loop() {
  uint32_t now = millis();

  // --- Serial commands (non-blocking, runs every loop) ---
  serviceSerialCommands();

  // --- Parse LIN bytes from UART ---
  while (LIN.available()) {
    uint8_t b = LIN.read();
    now = millis();
    uint32_t gap = now - lastByteMs;
    lastByteMs = now;

    if (rawByteLog) {
      Serial.printf("raw gap=%lu b=%02X state=%d\n", (unsigned long)gap, b, state);
    }

    if (b == 0x00 && gap >= BREAK_GAP_MS) {
      finalizeBufferedFrame("break");
      state = S_SYNC;
      resetFrameBuffer();
      continue;
    }

    switch (state) {
      case S_BYTES:
        if (rxCount > 0 && gap >= FRAME_IDLE_TIMEOUT_MS) {
          finalizeBufferedFrame("idle");
        }
        if (rxCount < MAX_FRAME_BYTES) {
          rxBytes[rxCount++] = b;
        } else {
          frameOverflow = true;
        }
        break;

      case S_SYNC:
        if (b == 0x55) {
          state = S_PID;
        } else if (b != 0x00) {
          syncErrCount++;
          Serial.printf("[sync err 0x%02X]\n", b);
          state = S_IDLE;
        }
        break;

      case S_PID:
        pid = b;
        resetFrameBuffer();
        state = S_BYTES;
        break;

      default:
        break;
    }
  }

  // --- Idle timeout for S_BYTES (re-check after LIN read) ---
  if (state == S_BYTES && rxCount > 0 && now - lastByteMs >= FRAME_IDLE_TIMEOUT_MS) {
    finalizeBufferedFrame("idle");
  }

  // --- Heartbeat ---
  if (now - lastHeartbeatMs >= 1000) {
    lastHeartbeatMs = now;
    noInterrupts();
    uint32_t edges = edgeCount;
    edgeCount = 0;
    interrupts();

#ifndef NO_WIFI
    Serial.printf("alive d3=%d edges=%lu frames=%lu badChk=%lu badPid=%lu ovf=%lu short=%lu syncErr=%lu baud=%u q=%u drop=%lu postFail=%lu wifi=%s\n",
      digitalRead(LIN_RX_PIN),
      (unsigned long)edges,
      (unsigned long)frameCount,
      (unsigned long)checksumBadCount,
      (unsigned long)parityBadCount,
      (unsigned long)overflowCount,
      (unsigned long)shortFrameCount,
      (unsigned long)syncErrCount,
      linBaud,
      telemetryCount,
      (unsigned long)telemetryDropCount,
      (unsigned long)postFailCount,
      wifiOk ? WiFi.localIP().toString().c_str() : "off");
#else
    Serial.printf("alive d3=%d edges=%lu frames=%lu badChk=%lu badPid=%lu ovf=%lu short=%lu syncErr=%lu baud=%u lastByteMs=%lu\n",
      digitalRead(LIN_RX_PIN),
      (unsigned long)edges,
      (unsigned long)frameCount,
      (unsigned long)checksumBadCount,
      (unsigned long)parityBadCount,
      (unsigned long)overflowCount,
      (unsigned long)shortFrameCount,
      (unsigned long)syncErrCount,
      linBaud,
      (unsigned long)lastByteMs);
#endif
  }

#ifdef ACTIVE_MODE
  serviceActiveSafety();
  serviceAntiNag();
  if (mirrorActive && dblClickEnabled) serviceAliveTx();
  // Retry BLE advertising after NimBLE host sync. start() returns true on success.
  NimBLEAdvertising *ad = NimBLEDevice::getAdvertising();
  if (bleAdvPending && ad && now - bleLastAdvAttemptMs >= 500) {
    bleLastAdvAttemptMs = now;
    if (ad->isAdvertising()) {
      bleAdvPending = false;
    } else {
      bool started = ad->start();
      if (started) {
        bleAdvPending = false;
        Serial.println("BLE: advertising started");
      }
    }
  }
#endif

#ifndef NO_WIFI
  serviceTelemetry();
#endif
}

#endif  // PASSTHROUGH_MODE

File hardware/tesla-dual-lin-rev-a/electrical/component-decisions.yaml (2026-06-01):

project: tesla-dual-lin-rev-a
revision: A
decision_date: 2026-05-29
goal: affordable robust 100-unit-ready dual-LIN ESP32-S3 PCBA

source_backing:
  completed_research_artifacts:
    - personal-secretary-mvp/docs/research/responses/2026-05-29-100-unit-dual-lin-ble-passthrough-board-manufacturing-plan-ad722f1f.md
    - personal-secretary-mvp/docs/research/responses/2026-05-29-dual-lin-esp32-s3-rev-a-schematic-and-pcba-design-rules-68f254d3.md
    - personal-secretary-mvp/docs/research/responses/2026-05-29-cost-optimized-rev-a-dual-lin-esp32-s3-pcba-bom-research-8380af65.md
  live_closure_job:
    job_id: f19c0816-ef6a-44c3-bc8c-167cc22b492e
    status_at_decision_time: running
    note: targeted closure job is durable tracking; Rev A decisions below use completed research plus local KiCad/NXP symbol verification.
  local_source_checks:
    - source: KiCad 10 Interface_CAN_LIN.kicad_sym symbol TJA1021xT
      path: C:/Users/ezabz/AppData/Local/Programs/KiCad/10.0/share/kicad/symbols/Interface_CAN_LIN.kicad_sym
      finding: SOIC-8 symbol maps RXD=1, SLP_N=2, WAKE_N=3, TXD=4, GND=5, LIN=6, VBAT=7, INH=8.
    - source: NXP TJA1021 datasheet URL referenced by KiCad symbol and research artifact
      url: https://www.nxp.com/docs/en/data-sheet/TJA1021.pdf
      note: direct NXP download was blocked locally; LCSC/Farnell mirrors were downloaded for later manual review.
    - source: Espressif ESP32-S3-WROOM-1/1U datasheet
      url: https://documentation.espressif.com/esp32-s3-wroom-1_wroom-1u_datasheet_en.pdf
      finding: native USB uses GPIO19 D- and GPIO20 D+; module requires 3.3V rail sized for radio peaks.
    - source: TI LM5164 datasheet and KiCad 10 Regulator_Switching symbol LM5164DDA
      url: https://www.ti.com/product/LM5164
      finding: LM5164DDA is an active 6V-100V 1A synchronous buck in 8-pin SOIC PowerPAD; symbol maps GND=1, VIN=2, EN/UVLO=3, RON=4, FB=5, PGOOD=6, BST=7, SW=8, EP=9.
    - source: Tesla steering-wheel LIN connector research artifact
      path: personal-secretary-mvp/docs/research/responses/2026-05-31-research-directive-tesla-steering-wheel-lin-harness-connector-identification-5cdd8b12.md
      finding: Public Tesla Model Y SOP6 steering-wheel switch inline data identifies a 4-cavity VBAT/GND/unused/LIN interface, but does not prove the OEM physical connector family; Rev A uses Molex Micro-Fit 3.0 43650-0415 board-side service connectors plus adapter pigtails.

tja1021_soic8:
  selected_mpn: TJA1021T/20/C,118
  package: SOIC-8
  kicad_symbol: Interface_CAN_LIN:TJA1021xT
  kicad_footprint: Package_SO:SOIC-8_3.9x4.9mm_P1.27mm
  pinout:
    "1": RXD
    "2": SLP_N
    "3": WAKE_N
    "4": TXD
    "5": GND
    "6": LIN
    "7": VBAT
    "8": INH
  rev_a_mode_decisions:
    bus_role: responder_or_bridge_node_only
    default_no_master_pullup_populated: true
    optional_dnp_master_pullup_footprints: true
    reason: Tesla vehicle side is assumed to provide the LIN commander/master bias; Rev A leaves strong 1k plus diode LIN master pullups DNP by default, with footprints available only if bench evidence proves an isolated commanded segment requires one.
    vbat: VBAT_PROTECTED with 100nF plus 1uF local decoupling per transceiver
    lin: 10R series resistor plus PESD1LIN-class ESD at each harness entry
    slp_n: common post-switch LIN_EN net, external 100k pulldown, safe switch throw hard-ties LIN_EN to GND
    wake_n: pulled high to VBAT_PROTECTED through 100k and exposed only as optional test net; no MCU GPIO for Rev A
    inh: not used to enable the buck regulator; exposed only as optional no-load test net
    txd: firmware must set TXD pins to recessive/idle before asserting LIN_EN_DRIVE; SLP_N gate is the hardware safety layer
    rxd: direct 3.3V-compatible MCU input, no level shifter
  default_off_chain:
    - MCU reset/blank/bootloader leaves LIN_EN_DRIVE low or high-Z.
    - R_LINEN_PD holds LIN_EN low.
    - SW1 safe position shorts LIN_EN to GND regardless of firmware.
    - SW1 second pole shorts ARM_SENSE to GND in safe/off and to 3V3 in armed position.
    - Both TJA1021 SLP_N pins stay low, keeping transceivers asleep.
    - Firmware can enter normal LIN only after physical arm is on and safe:arm asserts LIN_EN_DRIVE.
  physical_arm_switch:
    type: DPDT slide switch
    pole_a_common: LIN_EN
    pole_a_safe_throw: GND
    pole_a_arm_throw: LIN_EN_DRIVE
    pole_b_common: ARM_SENSE
    pole_b_safe_throw: GND
    pole_b_arm_throw: 3V3
    arm_sense_default: 100k pulldown to GND
    reason: firmware must be able to read the physical arm position before it asserts LIN_EN_DRIVE.
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

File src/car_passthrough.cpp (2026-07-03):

#ifdef PASSTHROUGH_MODE

#include <Arduino.h>
#include <HardwareSerial.h>
#include <esp_system.h>

#ifdef BLE_ENABLED
#include <NimBLEDevice.h>
#endif

#ifndef FIRMWARE_VERSION
#define FIRMWARE_VERSION "v5.2-passthrough-dev"
#endif

#ifndef BUILD_PROFILE
#define BUILD_PROFILE "car_passthrough"
#endif

#define LIN_BAUD 19200
#ifndef CAR_RX_PIN
#define CAR_RX_PIN 5
#endif
#ifndef CAR_TX_PIN
#define CAR_TX_PIN 4
#endif
#ifndef WHEEL_RX_PIN
#define WHEEL_RX_PIN 20
#endif
#ifndef WHEEL_TX_PIN
#define WHEEL_TX_PIN 21
#endif
#ifndef LIN_EN_PIN
#define LIN_EN_PIN -1
#endif
#ifndef ARM_SENSE_PIN
#define ARM_SENSE_PIN -1
#endif
#ifndef ARM_SENSE_ACTIVE_LEVEL
#define ARM_SENSE_ACTIVE_LEVEL HIGH
#endif
#define BREAK_GAP_MS 2
#define RESPONSE_IDLE_TIMEOUT_MS 8
#define POLL_GAP_MS 8
#define ACTIVE_SESSION_MAX_MS 300000UL
#define MAX_DATA_LEN 8
#define CACHE_COUNT 64

HardwareSerial LIN_CAR(1);
HardwareSerial LIN_WHEEL(2);  // UART2: leaves Serial/UART0 on GPIO43/44 (TP6/TP7)

enum HeaderState { H_IDLE, H_SYNC, H_PID };

struct HeaderParser {
  HeaderState state = H_IDLE;
  uint32_t lastByteMs = 0;
  uint32_t headers = 0;
  uint32_t syncErrors = 0;
};

struct CachedFrame {
  uint8_t data[MAX_DATA_LEN] = {0};
  uint8_t len = 0;
  uint8_t checksum = 0;
  bool valid = false;
  uint32_t updatedMs = 0;
  uint32_t updates = 0;
};

static HeaderParser carParser;
static CachedFrame cache[CACHE_COUNT];
static char cmdBuf[96];
static uint8_t cmdIdx = 0;
static bool armed = false;
static bool bridgeEnabled = true;
static uint32_t activeSessionStartMs = 0;
static uint32_t lastHeartbeatMs = 0;
static uint32_t carResponses = 0;
static uint32_t carMisses = 0;
static uint32_t wheelPolls = 0;
static uint32_t wheelGood = 0;
static uint32_t wheelBad = 0;
static uint32_t injectedFrames = 0;
static uint32_t inhibitedFrames = 0;
static int leftInjectDirection = 0;
static int leftInjectRemaining = 0;
static uint8_t leftCounter = 0;
static bool antiNagEnabled = false;
static bool antiNagSingleCycle = false;
static uint32_t antiNagLastInjectionMs = 0;
static uint32_t antiNagIntervalMs = 15000;   // fire every 15s
static int antiNagPhase = 0;  // 0=up next, 1=down next
static uint32_t lastPollMs = 0;
static uint8_t pollIndex = 0;
static const uint8_t POLL_IDS[] = {0x28, 0x29, 0x2A, 0x2B, 0x2C, 0x2D};
static const uint8_t POLL_COUNT = sizeof(POLL_IDS) / sizeof(POLL_IDS[0]);

static bool wheelAwaiting = false;
static uint8_t wheelRawId = 0;
static uint8_t wheelPid = 0;
static uint8_t wheelBytes[10] = {0};
static uint8_t wheelCount = 0;
static uint8_t wheelIgnoreEcho = 0;
static uint32_t wheelLastByteMs = 0;

static void setLinEnable(bool enable) {
  if (LIN_EN_PIN < 0) return;
  digitalWrite(LIN_EN_PIN, enable ? HIGH : LOW);
}

static bool physicalArmIsOn() {
  if (ARM_SENSE_PIN < 0) return true;
  return digitalRead(ARM_SENSE_PIN) == ARM_SENSE_ACTIVE_LEVEL;
}

static const uint8_t MODEL3Y_LEFT_COUNTER_B6[16] = {
  0x7F, 0x62, 0x45, 0x58, 0x0B, 0x16, 0x31, 0x2C,
  0x97, 0x8A, 0xAD, 0xB0, 0xE3, 0xFE, 0xD9, 0xC4
};

static const char *resetReasonLabel() {
  switch (esp_reset_reason()) {
    case ESP_RST_POWERON: return "poweron";
    case ESP_RST_EXT: return "external";
    case ESP_RST_SW: return "software";
    case ESP_RST_PANIC: return "panic";
    case ESP_RST_INT_WDT: return "interrupt_watchdog";
    case ESP_RST_TASK_WDT: return "task_watchdog";
    case ESP_RST_WDT: return "other_watchdog";
    case ESP_RST_DEEPSLEEP: return "deepsleep";
    case ESP_RST_BROWNOUT: return "brownout";
    default: return "unknown";
  }
}

static uint8_t makeProtectedId(uint8_t rawId) {
  uint8_t id = rawId & 0x3F;
  uint8_t id0 = (id >> 0) & 1;
  uint8_t id1 = (id >> 1) & 1;
  uint8_t id2 = (id >> 2) & 1;
  uint8_t id3 = (id >> 3) & 1;
  uint8_t id4 = (id >> 4) & 1;
  uint8_t id5 = (id >> 5) & 1;
  uint8_t p0 = id0 ^ id1 ^ id2 ^ id4;
  uint8_t p1 = (~(id1 ^ id3 ^ id4 ^ id5)) & 1;
  return id | (p0 << 6) | (p1 << 7);
}

static bool protectedIdIsValid(uint8_t pid) {
  return makeProtectedId(pid & 0x3F) == pid;
}

static uint8_t linChecksum(uint8_t pid, const uint8_t *data, uint8_t len, bool enhanced) {
  uint16_t sum = enhanced ? pid : 0;
  for (uint8_t i = 0; i < len; i++) {
    sum += data[i];
    while (sum > 0xFF) sum = (sum & 0xFF) + (sum >> 8);
  }
  return ~(uint8_t)sum;
}

static void linBreak(HardwareSerial &port) {
  uint32_t bitTimeUs = 1000000UL / LIN_BAUD;
  port.flush();
  port.updateBaudRate(LIN_BAUD / 2);
  port.write((uint8_t)0x00);
  port.flush();
  port.updateBaudRate(LIN_BAUD);
  delayMicroseconds(bitTimeUs * 2);
}

static void sendHeader(HardwareSerial &port, uint8_t rawId) {
  linBreak(port);
  port.write((uint8_t)0x55);
  port.write(makeProtectedId(rawId));
  port.flush();
}

static void buildModel3YLeftFrame(int direction, uint8_t counter, uint8_t *data, uint8_t *len) {
  uint8_t ctr = counter & 0x0F;
  uint8_t control = 0x0C;
  if (direction == 2) control = 0x2C;
  else if (direction > 0) control = 0x0D;
  else if (direction < 0) control = 0x0B;
  data[0] = control;
  data[1] = 0x80;
  data[2] = 0x3F;
  data[3] = 0x96;
  data[4] = 0x00;
  data[5] = (uint8_t)(0xF0 + ctr);
  data[6] = MODEL3Y_LEFT_COUNTER_B6[ctr];
  *len = 7;
}
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

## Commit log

2026-05-27 feat: Tesla LIN bench v4 - full firmware, tooling, docs
    - Firmware v4: boundary-based LIN parser, ring buffer, runtime serial commands
    - APGDT001 + TJA1021 + level shifter + XIAO ESP32-C3 hardware validated
    - Bench validation PASS: ID=0x0C, 0x10, 0x22, 0x3C enhanced/classic
    - Anti-nag replay tool: alternating UP/DOWN scroll with correct checksums
    - Python capture analyzer with Tesla ID reference tables
    - Car-day launcher: unified entry point for Model 3/Y/X capture
    - TOOLS.md: complete reference with traffic-light safety guidelines
    - Secretary API integration with LIN event posting
    [analyze-lin-capture.py, lin-payload-calc.py, main.cpp]
2026-05-27 feat: add multi-model active anti-nag injector and TX wiring docs
2026-05-27 chore: default ACTIVE_MODE off — uncomment locally for active builds
2026-05-27 fix: validate active LIN TX bench path
    [main.cpp]
2026-05-27 tools: capture active LIN frames via APG raw fallback
2026-05-27 firmware: bus-idle collision guard, realistic payloads, mirror injection
    [main.cpp]
2026-05-27 v5: Enable ACTIVE_MODE by default, add NimBLE BLE config service with model/mode/period/enable characteristics, deferred advertising retry, fix BLE API for NimBLE 2.5.0, update START_HERE.md
    [main.cpp]
2026-05-28 fix: harden active bench BLE proof
    [main.cpp]
2026-05-29 Document dual LIN passthrough board decision
2026-06-01 Add Tesla Dual LIN Rev A hardware package
    [assembly_policy.csv, dnp-parts.csv, footprint-map.csv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]
2026-06-04 Document JLC D4 L1 replacement supplement
    [footprint-map.csv, jlcpcb-smt-first-bom.csv, rev_a_bom_strategy.csv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]
2026-06-04 Mark D4 L1 issue as mass-order blocker
    [footprint-map.csv, rev_a_bom_strategy.csv, rev_a_supplier_shortlist.csv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]
2026-06-17 Consolidate all Tesla LIN project assets into tesla-lin-chip
    - Rename repo from xiao-lin-bench to tesla-lin-chip
    - Add docs/reports/: 4 Tesla field analysis and bench handoff reports
    - Add research/directives/: 12 Tesla/LIN/ESP32 research directives (019,022,027,044-047,052-056)
    - Add research/responses/: 46+ Tesla/dual-LIN research responses and syntheses
    - Add knowledge/hardware/: 12 Tesla TSL hardware knowledge base files
    - Add captures/sigrok/: 4 raw Sigrok .sr captures from Model X field sessions and FX2 preflight
    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
2026-06-17 Add all bench logs, Gerbers, fab files, and design artifacts — full repo preservation
    Previously gitignored:
    - logs/: 121 bench CSV captures, active proof logs, bench-evidence session archives
    - hardware/tesla-dual-lin-rev-a/build/fab/: all Gerbers, drill, BOM, CPL (JLCPCB manufacturing package)
    - hardware/tesla-dual-lin-rev-a/build/first-article-records/: Rev A order dry-run records
    - hardware/tesla-dual-lin-rev-a/build/: all DRC/ERC reports, routing intermediate files
    - hardware/tesla-dual-lin-rev-a/build/quote/jlcpcb-mini-order-2026-05-31/: first quote package
    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
    [_unrouted.kicad_pcb, antinag-replay-20260526_204622.csv, antinag-replay-20260526_204708.csv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]
2026-07-03 Rev A active anti-nag: passthrough firmware, docs, tools, and photos
    Major update consolidating all Rev A ESP32-S3 dual-LIN work:
    Firmware:
    - car_passthrough.cpp: +309 lines — dual-transceiver bridge with
    car-side header listener, wheel-side poller, cached slave responses,
    synthetic frame injection, physical arm sense, BLE config service
    - platformio.ini: rev_a_passthrough and rev_a_active_ble environments
    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
